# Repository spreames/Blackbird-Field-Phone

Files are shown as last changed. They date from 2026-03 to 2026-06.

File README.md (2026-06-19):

# Blackbird Field Phone

A cave rescue field phone for replacing the TP-6N.

#### **Status: Incomplete -- do not for design use until all files loaded**

### Background:

In the USA, cave rescue communications have been done with military field phones for decades. These are two-wire systems that are part of a party-line system (aka parallel connected). The National Cave Rescue Commission (NCRC) has a cache of these phones that are used for training. These units are available in the military surplus stores and online such as eBay. Over the years these field phones have become standard for all cave rescue teams in the USA.

There are three standard field phones that are in use today. The TA-1 ("sound powered" phone) which does not requires batteries but has a very limited range of 2 miles or less. The TA-312 (the "crank phone") has a theoretical range of 20 miles but weights 10.0 lbs with batteries! The TP-6N (the "NATO phone") has the same range but has solid-state circuitry, is much lighter (2.5 lbs), and much smaller.

The problem is that the units are failing. There a no replacement parts, no schematics, and no theory of operation. The most recent model, the TP-6N, was designed in 1973 -- a 50-year old design!

### Introduction to the Blackbird:

In December 2021, the NCRC formed the Communication Committee (CommComm) to address the increasing failure rate with the military phones in the field. The group decided to begin the design of a clone of the TP-6N which was named "Blackbird". Many of the original components are obsolete and very hard to obtain such as custom transformers and uni-junction transistors. So the team designed a functional clone such that works the same as the TP-6N but uses the modern techniques such as SMT components, KiCAD schematics and PCB layouts, 3D printing, and LTspice simulations.

The requirements and goals are:

- Backward compatable with the existing field phones

- Lighter, smaller, and requiring less power

- Runs off three AA batteries

- Is the same cost or less as TP-6Ns on eBay (when they are available)

The complete Goals and Requirements document is 13 pages and is linked here:

xxxxxx

### Block Diagram:

xxxx

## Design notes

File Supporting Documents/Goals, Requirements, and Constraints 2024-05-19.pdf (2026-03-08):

Goals, Requirements, and Constraints for the Design of the TP-6N Field Phone Replacement

last edit: May 19, 2024

authors: Steve Reames, with additions from members of the NCRC Communications Committee

### 1.0 Background:

The TP-6N has been the most popular field phone for cave rescue for over 15 years. It has been reliable, lightweight, and does well in the caving environment. There is a need for a replacement field phone that will be designed as a replacement for the TP-6N.

### 1.1 Who are the Users?

The users of the replacement field phone would be anyone who is involved with communications for cave rescue. This can include ordinary cavers who volunteer their time for teaching or real rescues, search and rescue team members (SAR), or agency personnel such as firefighters, National Park Service (NPS), the Bureau of Land Management (BLM), or United States Forest Service (USFS). This project is generally focused on U.S. users, but can include foreign cave rescue team members.

The NCRC has formed the NCRC Communication Committee (CommComm) to address the needs for supporting cave rescue communications, which includes a replacement for the TP-6N field phone. CommComm has taken the responsibility to design and possibly manufacture this potential replacement field phone. The committee will take into account the needs of the above mentioned users in the design of the field phone.

### 2.0 Abbreviations and Terms:

POTS: Plain Ordinary Telephone Service. Also referred to as a "landline".

EMC: Electromagnetic Compatibility. Ability of electrical equipment to function acceptably in their electromagnetic environment by limiting the unintentional generation of electromagnetic energy.

NCRC: National Cave Rescue Commission. A division of the NSS dedicated to cave rescue training.

TP-6N: A field phone often referred to as the "NATO phone". Designed in 1973 by the Norwegian Armed Forces.

TA-312: A field phone often referred to as the "crank phone". Designed in the 1950's and deployed in the Korean war.

TA-1: A field phone often referred to as the "sound powered phone". Designed in the 1950's.

RFI: Radio Frequency Interference. An old term, now replaced with EMC.

Opamp: Operational Amplifier. An integrated circuit with many uses in electronics.

SAR: Search and Rescue

PTT: Push To Talk. A switch that enables the microphone of a field phone.

### 3.0 Nomenclature:

A number surrounded by brackets, such as [1], indicates the priority of the requirement. There are three categories:

[1] -- Required: Cannot be changed without revisiting the purpose of the entire project.
[2] -- Strong Want: We are willing to put extra effort to accomplish this requirement.
[3] -- Would Be Nice: An extra feature that would make the product easier to use.

### 4.0 Requirements:

The requirements in this section are a combination of military specifications and real-world use of the field phones. The published military specs are very sparse and are completely inadequate for designing a replacement field phone (see Appendixes). When military specs are not available we fall back to measurements of physical units, knowing that we will be working with typical values rather than worst case values.

Section 4.1

[1] Backward compatible with the existing 2-wire military field phones, specifically the TP-6N (“NATO” phone), TA-312 (“Crank phone”), and the TA-1 (Sound-powered phone).

Description: Backward compatible means that the new phone can be added to an existing phone system with no adverse effect. The physical implementation can be different, for example the TA-312 uses D-cell batteries and the new proposed phone will use AA batteries. But the main functions of duplex voice communication with high-voltage ringing signal must be maintained.

Section 4.2

[1] The replacement unit will work with the standard 2-wire communication system. It will be designed to use lines with no 48V bias (LB, not CB, in military speak). It may work with lines DC voltage applied but is not required. Wires for cave rescue are assumed to have no DC bias.

Description: Conventional POTS telephones use a central 48V battery for powering the phone and for signaling. This is not required for cave rescue applications and the design of inductors that need to support 48V DC lines is unnecessarily complex. There is also the question of range. Two TP-6N units can communicate up to 14 miles (wet, WD-1 wire). The TA-312 also can go 14 miles (wet, WD-1 wire). The TA-1 is rated at 4 miles, and the EE-8 is rated at 7 miles. It is also known that each additional attached phone reduces the range. The proposed unit has not been tested for range. The standard WD-1 military wire is assumed, but the system should work with any pair of wires, though the range may be reduced.

Section 4.3

[2] Power: The replacement unit should operate from 3.0V to 5.0V. The quiescent current should be equal to or less than 7.5 mA. Typical power would be three AA batteries (4.5V to 3.0V) or a single 18650 Lithium-ion battery (4.2V to 3.0V).

Description: This is based on the typical use of three AA batteries for the TP-6N. The TP-6N was designed to use three D-cells, but the military wanted the unit to run for weeks. The capacity of an alkaline AA is approximately 2300 mAh (for a 1.0V dropout). So the quiescent run time would be 300 hours. For a Sanyo 3400mAh lithium-ion battery the run time would be 450 hours. The actual run time will be less due to use of the microphone and the ringer. It is rare for a cave rescue to run for 4 days (100 hours). In that situation it is reasonable to expect that someone would bring replacement batteries if the rescue ran that long. So a quiescent current of 7.5 mA is very conservative and can be increased if needed. The maximum permitted voltage of 5.0V is because many of the low-power opamps have a maximum voltage of 5.5V.

Section 4.4

Ringing Voltage: Ringing is a high-voltage signal used to alert other users on the line. The function of ringing is a type [1] requirement, but the exact voltage and frequency is a type [2] requirement. The ringing is expected to be an AC signal in the 40 to 100 Vpeak range. The ringer circuitry must not be damaged by a short circuit on the line.

Description: The generation of the ringing signal is one of the hardest design challenges for the replacement field phone. The circuit must work at the minimum input voltage (3.0V) but generate a 60 V (typical) signal that is switched at a 20 Hz (typical) to create an 120 Vp-p waveform on the line. The TP-6N has an amazing low part count for their circuit but required custom magnetics that we do not have access to nor the construction of said magnetics. We, being small-shop designers and manufacturers, are limited by off-the-shelf components or building components (such as magnetics) that are easily assembled with technician skills and do not require special tools.

The TA-1 uses a hand generator to create the ringing signal. One squeeze on the trigger creates the output voltage. The TA-312 has a crank generator on the side of the unit to create the ringing signal. On the receiving end, the TA-312 has a hammer on a diaphragm that creates a drumming sound. The specs for the TA-312 say the ringing signal is 20 Hz at 90 to 100 V (but does not indicate if that voltage is Vpeak, Vp-p, or RMS).

The TP-6N uses a solid-state ringing signal. When the button is pressed the circuit creates a 20 Hz or 25 Hz signal (depending on whether the unit is Norwegian or Swedish). The specification is that with a 4.5 V battery voltage the output is 60 Vrms; with a 3.0 V battery the output voltage is 38 Vrms (with a 3 Kohm load). It is known that on long lines the TP-6N does not have enough energy to trigger the sounder of a TA-312.

Commercial ringing circuits (used with local PBX systems) often have specifications of an output of voltage of 70 to 91 Vrms with an input power of 2 to 3 Watts. (Though available on eBay, they all require an input voltage of 12V.)

The telephone system (POTS) specifies the impedance of one REN (Ringer Equivalent Number) to be approximately 7 Kohm (or more) at 20 Hz. This is consistent with our measurement of 35 Kohm at the input of a TP-6N. Though REN is specified for POTS, the military phone system is derived from the POTS.

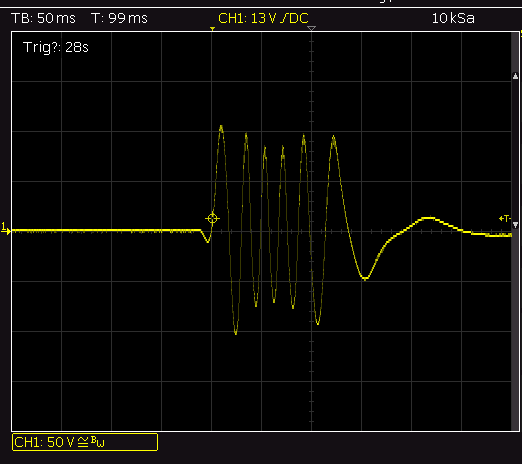
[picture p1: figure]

Ringing signal for the TA-1 (with 500 ft line and TP-6N load)

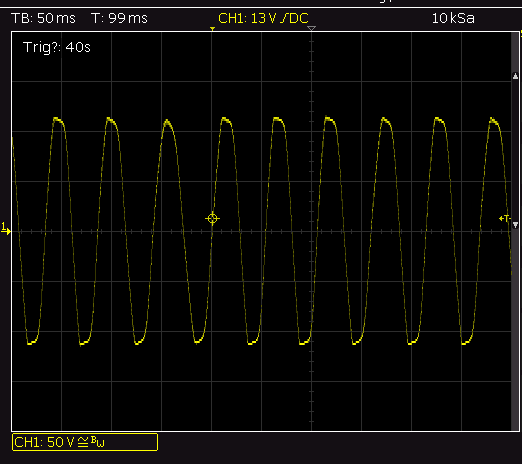
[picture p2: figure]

Ringing signal from a TA-312 (with 500 ft line and TP-6N load)

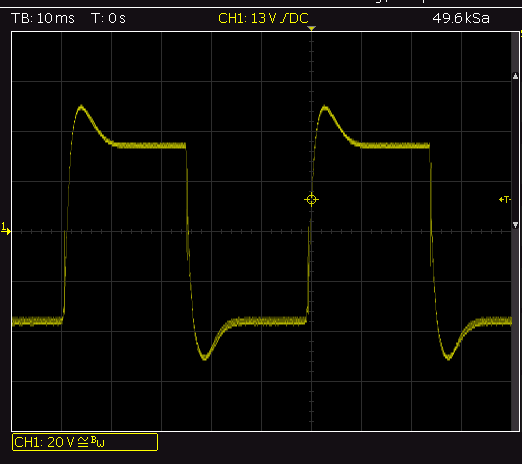
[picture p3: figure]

Ringing signal from TP-6N (with a 500 ft line and a TA-312 load)

Section 4.5

[2] Incoming Ringing Signal (audio): An incoming ringing signal will be heard in the earpiece of the handset. No additional circuitry is needed to receive the signal.

Description: The current design uses the same system as the TP-6N; the clicking from the ringing signal is heard in the earpiece. This is different from almost all military field phones; they typically have a separate sounder in the base unit. The TA-312 has a "drum" that vibrates at the ringing signal frequency. The British PTC-414 (circa 1993) has a piezoelectric buzzer that oscillates at 2 KHz, modulated by the 20 Hz ringing signal. This information is just for reference in the case we wish to change how the incoming ringing signal is indicated.

Section 4.6

[2] Incoming Ringing Indicator (visual): When a ringing signal is present, whether it is being generated in the unit or being received from a remote unit, a red LED flashes (at 20 Hz). An additional troubleshooting feature [3] of the TP-6N is that if the unit is open circuited (or not connected to the line) then the user can hear the ringing in the earpiece, but no LED is present. If the unit is shorted then the LED is visible, but no ringing is heard in the earpiece.

Description: The LED in the TP-6N appears to be type 1-3/4 (5 mm) which makes sense because red LEDs were just entering the market in the early 1970's. No other field phone (of that vintage) has a visible indicator. But it has been found to be very handy, particularly for troubleshooting. The LED on the TP-6N is very hard to see in daylight but works very well in cave conditions. These days there are much more efficient LEDs that only cost a few more pennies.

Section 4.7

[1] Weight and Volume: The weight and volume should be equal or less than a TP-6N.

Description: The weight of the TP-6N handset and cord is 0.73 lbs, the base unit of the TP-6N is 2.16 lb, and the entire package, including the pouch and D-cell batteries is 3.64 lbs. This is an unfair comparison because we never use D-cells, instead we use the insert with three AA batteries. Subtracting the difference between the D-cells and the AA cells, we should be looking for a target weight of 2.97 lbs. Volume is also a key parameter for cave rescuers. The existing TP-6N (total package) is approximately 10.2" x 7.7" x 2.6". A smaller package would enable a rescuer to move faster, or carry more gear at the same speed. Both are valuable attributes.

The intent of the project is to leverage techniques and processes that did not exist or were too expensive to implement in the 1970's. Some examples are 3D printing, inexpensive PCBs, and surface-mount devices (SMDs).

Section 4.8

[1] Full Duplex Communication: The existing military phone system uses full duplex communications. Specifically, when talker A is speaking, they still can hear speech from person
B. This requires a "hybrid" circuit which combines 4-wire communication (microphone and earpiece) into a 2-wire system which is attached to the field wire. This is how POTS works.

Description: The addition of a hybrid circuit is an additional complexity which is generally avoided. But to be compatible with existing field phones then it is required. The other approach, a half duplex system, is what is used with radios -- when the talker keys the microphone then no one else can interrupt the transmission. The use of a hybrid gives the ability of the receiver to give instant feedback to the transmitter (e.g. "hold on, give me that number slower", or "break, break, priority message incoming"). One could argue the utility of that feature, but since we want to be compatible with existing field phones then the decision is done. There is the question of why do we have a PTT button on our field phones? POTS does not have it. The answer is to keep the noise down on the wires. Only the person who has keyed their PTT will enable their microphone.

Section 4.9

[1] Electromagnetic Compatibility: Any electronic circuit has the potential to radiate electromagnetic energy and interfere with nearby communications. The Federal Communications Commission (FCC) is responsible for regulating the frequency and intensity of any EM emissions. There are three options for handing the FCC regulations. 1) Ensure by design that any potential radiation will be below any of the frequencies that are regulated by the

FCC. 2) Submit sample circuits to a test lab for certification that will confirm that the circuit is compliant. 3) Ignore the FCC regulations because it is unlikely we would be caught. We must decide which of the three options we choose to follow.

Description: Reading the regulations for EMC can be overwhelming. But in the U.S. battery operated devices are exempt as long as there are no clocks higher than 1.705 MHz. So the current Blackbird project is exempt. There is a caveat is that the product is not exempt if the product is running and connected (directly or indirectly) to an AC power line. So the field phone cannot be running while plugged into a battery charger. One of the proposed features is the ability to run off external batteries, such as 12V car battery. This would probably require a switching power supply to convert the 12V into 4.5V for the field phone circuitry. Most switching power supplies (at these powers and voltages) switch at 150 KHz to 1 MHz, so we are still covered. (see Appendix D.)

Technically, there is a fourth option: do it yourself kits. For many years it has been assumed that if you build a kit then it is exempt. Though this may have been true in the past, it is not correct anymore. But it is not clear who is responsible for compliance -- the kit manufacturer or the user. A dated link from Sparkfun is interesting reading:
https://www.sparkfun.com/tutorials/398

It would be nice to have the field phone covered in other countries, specially the EU. That would be a type [3] requirement. In recent years the EU has been regulating lower frequency emissions. In the past you could be safe with any frequency below 30 KHz. Recent changes apply to some circuits as low as 9 KHz (think of buried wires for guiding a robot lawn mower). Since certifications generally cost $2500 and up, it is not cost efficient for us to comply with EU regulations. But if we do have to do testing for the U.S. then it typically only costs another 10% to certify for the EU also.

EMC certification is a complex topic and cannot be easily summarized in these pages.

### 5.0 Requirements for Future Text-Based Communications System

(To be determined)

Notes from Andy Sheaff in April 2024:

Digital Text System Constraints (no particular order):

* Use WD-1 field wire for an communications because teams already have this wire and are unlikely to change.

* Avoid baseband digital data to keep Comms Operators from having to listen to the digital data; Parallel voice and data may be possible.

* Operate without termination because this just happens.

* Operate with or without stubs and branches of arbitrary length because the location of field phones may be in different and down forked passages. Field wire goes where it needs to.

* Operate with 10 km of wire between stations from Steve's recollection of the most distance rescue.

(Note: Steve's recollection was from the Fisher Ridge rescue reported by Tim Miller. They used 9,000 feet of wire, which is different than 10 km, though 10 km would be good goal -Steve R.)

* Devices should not be damaged by a short on the field wire because shorts do occur.

* Operate with a variable number of field phones attached as the number of field phones varies.

Appendix A:

Technical Data for the TP-6N

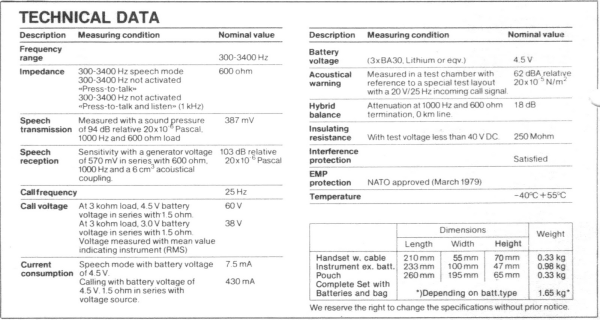
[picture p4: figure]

Appendix B:

Specifications for the TA-312/PT

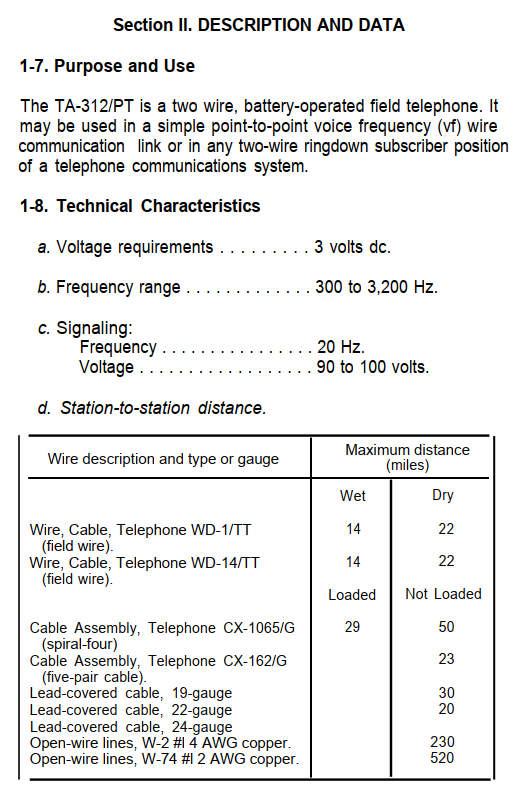
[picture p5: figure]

Appendix C:

Specifications for the TA-1/PT

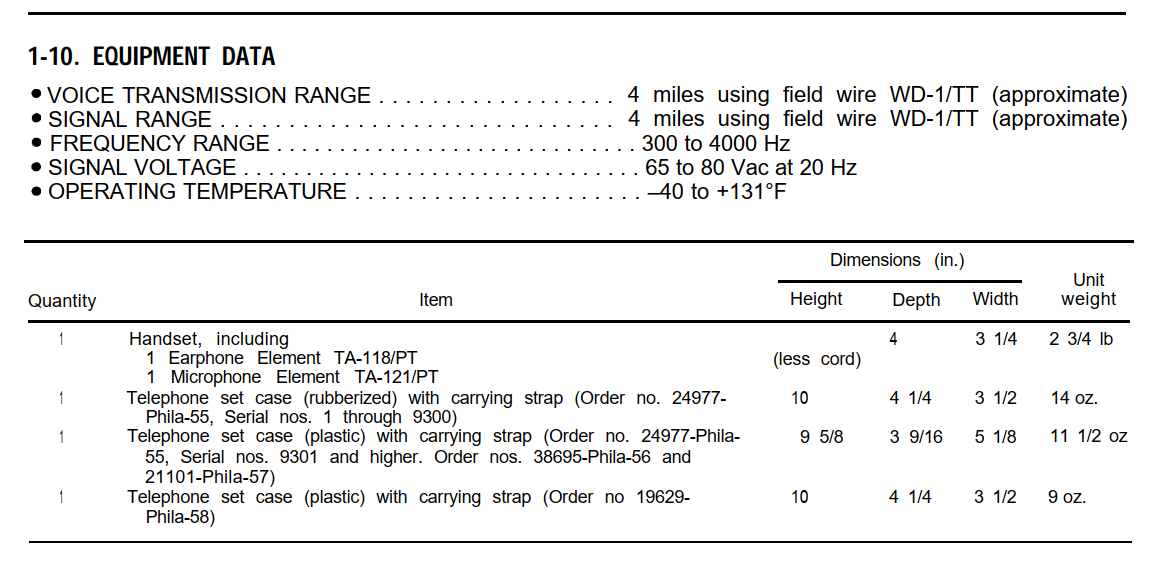
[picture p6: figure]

Appendix D:
FCC Title 47, Chapter 1, Subchapter A, Part 15, Subpart B:

§ 15.103 Exempted devices.

Except as provided in paragraph (j) (https://www.ecfr.gov/current/title-47/section-15.103#p-15.103(j)) of this section, the following devices are subject only to the general conditions of operation in §§ 15.5 (https://www.ecfr.gov/current/title-47/section-15.5) and 15.29, (https://www.ecfr.gov/current/title-47/section-15.29) and are exempt from the specific technical standards and other requirements contained in this part. The operator of the exempted device shall be required to stop operating the device upon a finding by the Commission or its representative that the device is causing harmful interference. Operation shall not resume until the condition causing the harmful interference has been corrected. Although not mandatory, it is strongly recommended that the manufacturer of an exempted device endeavor to have the device meet the specific technical standards in this part.

(a) A digital device utilized exclusively in any transportation vehicle including motor vehicles and aircraft.
(b) A digital device used exclusively as an electronic control or power system utilized by a public utility or in an industrial plant. The term public utility includes equipment only to the extent that it is in a dedicated building or large room owned or leased by the utility and does not extend to equipment installed in a subscriber's facility.
(c) A digital device used exclusively as industrial, commercial, or medical test equipment.
(d) A digital device utilized exclusively in an appliance, e.g., microwave oven, dishwasher, clothes dryer, air conditioner (central or window), etc.
(e) Specialized medical digital devices (generally used at the direction of or under the supervision of a licensed health care practitioner) whether used in a patient's home or a health care facility. Non-specialized medical devices, i.e., devices marketed through retail channels for use by the general public, are not exempted. This exemption also does not apply to digital devices used for record keeping or any purpose not directly connected with medical treatment.
(f) Digital devices that have a power consumption not exceeding 6 nW.
(g) Joystick controllers or similar devices, such as a mouse, used with digital devices but which contain only non-digital circuitry or a simple circuit to convert the signal to the format required (e.g., an integrated circuit for analog to digital conversion) are viewed as passive add-on devices, not themselves directly subject to the technical standards or the equipment authorization requirements.
(h) Digital devices in which both the highest frequency generated and the highest frequency used are less than 1.705 MHz and which do not operate from the AC power lines or contain provisions for operation while connected to the AC power lines. Digital devices that include, or make provision for the use of, battery eliminators, AC adaptors or battery chargers which permit operation while charging or that connect to the AC power lines indirectly, obtaining their power through another device which is connected to the AC power lines, do not fall under this exemption.
(i) Responsible parties should note that equipment containing more than one device is not exempt from the technical standards in this part unless all of the devices in the equipment meet the criteria for exemption. If only one of the included devices qualifies for exemption, the remainder of the equipment must comply with any applicable regulations. If a device performs more than one function and all of those functions do not meet the criteria for exemption, the device does not qualify for inclusion under the exemptions.
(j) Notwithstanding other provisions of this section, the rules governing certification apply to any equipment produced by any entity identified on the Covered List, as established pursuant to § 1.50002 of this chapter, (https://www.ecfr.gov/current/title-47/section-1.50002) as producing covered communications equipment.

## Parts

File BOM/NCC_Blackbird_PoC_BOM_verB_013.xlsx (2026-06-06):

MME P/N | REV | DWG No | PART DESCRIPTION | REF. DES. | QTY | UOM | Make/Buy | MFGR-1 | MFGR-1 P/N | DIST-1 | DIST-1 P/N | MFGR-2 | MFGR-2 P/N | MFGR-3 | MFGR-3 P/N | Cost (1) | Ext. Cost (1) | Cost (10) | Ext Cost (10)
 |  |  | Top Level – Blackbird Proof-of-Concept Field Phone
 |  |  | Main PCB Assy |  | 1 | EA | M
 |  |  | Handset Assy |  | 1 | EA | M
 |  |  | Base Unit Assy |  | 1 | EA | M
 |  |  | Battery, 18650 |  | 1 | EA | B
 |  |  | Battery, AA |  | 3 | EA | B
MME P/N | REV | DWG No | PART DESCRIPTION | REF. DES. | QTY | UOM | Make/Buy | MFGR-1 | MFGR-1 P/N | DIST-1 | DIST-1 P/N | MFGR-2 | MFGR-2 P/N | MFGR-3 | MFGR-3 P/N | Cost (1) | Ext. Cost (1) | Cost (10) | Ext Cost (10)
 |  |  | Handset Assy
 |  |  | Speaker, IP67, 30mm, WSPH-3005 |  | 1 | EA | B | Soberton Inc. | WSPH-3005 | Digikey | 433-1284-ND |  |  |  |  | $3.03 | $3.03 | $2.28 | $2.28
 |  |  | Microphone, 6mm dia, electret |  | 1 | EA | B | Soberton Inc. | EM6027LW-42C | Digikey | 433-1154-ND |  |  |  |  | $1.68 | $1.68 | $1.37 | $1.37
 |  |  | Switch, momentary pushbutton, for PTT | M1 | 1 | EA | B | Judco Manufacturing Inc. | 40-2390-00 | Digikey | 506PB-ND |  |  |  |  | $2.35 | $2.35 | $2.03 | $2.03 | old switch
 |  | xxx | Microphone Insert, 82A filament, Recreus FilaFlex |  | 1 | EA | M |  |  |  |  |  |  |  |  | $0.15 | $0.15 | $0.15 | $0.15
 |  |  | Cable, 5 cond, 5 x 0.34mm (22 AWG) |  | 1.5 | m | B | Helukabel | 49608 | TME | STR-PUR5X0.34 |  |  |  |  | $4.87 | $7.30 | $2.42 | $3.62
 |  |  | Cable gland, with pigtail |  | 1 | EA | B | Heyco Products Corp | 3237 | Digikey | 3720-3237-ND |  |  |  |  | $1.78 | $1.78 | $1.51 | $1.51
 |  |  | Screw, 316 SS, Button Head, Hex Drive, M3 x 0.5mm, 10mm Long |  | 13 | EA | B | McMaster | 94500A223 |  |  |  |  |  |  | $0.09 | $1.14 | $0.09 | $1.14 | uses 2.5mm hex driver
 |  |  | Connector,butt splice, 22-26 AWG, crimp |  | 5 | EA | B | TE Conn AMP Connectors | 321026 | Digikey | A27461 |  |  |  |  | $0.39 | $1.95 | $0.31 | $1.57
 |  |  | Connector, butt splice,
 |  |  | Brass Heat-Set Inserts for Plastic, M3 x 5.7mm | M3 | 13 | EA | B | CNC Kitchen | M3x5.7 | CNC Kitchen |  | McMaster | 97171A310 |  |  | $0.21 | $2.73 | $0.12 | $1.57
 |  | xxx | Filament, 3D printer, PCTG, Handset Cover, 2 copies |  | 26 | gm | M | 3D Fuel | Pro PCTG filament |  |  |  |  |  |  | $0.04 | $1.04 | $0.04 | $1.04 | based on PCTG
 |  | xxx | Filament, 3D printer, PCTG, Handset, Left body |  | 57 | gm | M | 3D Fuel | Pro PCTG filament |  |  |  |  |  |  | $0.04 | $2.27 | $0.04 | $2.27 | based on PCTG
 |  | xxx | Filament, 3D printer, PCTG, Handset, Right body |  | 58 | gm | M | 3D Fuel | Pro PCTG filament |  |  |  |  |  |  | $0.04 | $2.31 | $0.04 | $2.31 | based on PCTG
MME P/N | REV | DWG No | PART DESCRIPTION | REF. DES. | QTY | UOM | Make/Buy | MFGR-1 | MFGR-1 P/N | DIST-1 | DIST-1 P/N | MFGR-2 | MFGR-2 P/N | MFGR-3 | MFGR-3 P/N | Cost (1) | Ext. Cost (1) | Cost (10) | Ext Cost (10)
 |  |  | Base Unit Assy
 |  |  | Diode, LED, red, T ¾ package (5mm), 60 deg, 700 mcd | D200 | 1 | EA | B | Lumex Opto/Components Inc. | SSL-LX5093SID | Digikey | 67-2288-ND | Kingbright | WP63SURDK |  |  | $0.68 | $0.68 | $0.40 | $0.40
 |  |  | Diode mounting, for 1 ¾ package | LED mounting | 1 | EA | B | Lumex Opto/Components Inc. | SSH-LX5091 | Digikey | 67-1332-ND |  |  |  |  | $0.33 | $0.33 | $0.18 | $0.18
 |  |  | LED mounting,
 |  |  | Speaker, 8 ohm, square, for buzzer |  | 1 | EA | B | Wolff Electronics | OWS-131845W50A-8 | Digikey | 3949-OWS-131845W50A-8-ND |  |  |  |  | $1.51 | $1.51 | $1.18 | $1.18
 |  |  | Terminal Post, for comm line connection |  | 2 | EA | B | CLIFF Electronics | CL681561 | Digikey | 4654-CL681561-ND |  |  |  |  | $2.23 | $4.46 | $2.09 | $4.18
 |  |  | Connector, TRRS, 3.5mm, panel mount (aux connector) |  | 1 | EA | B | Same Sky (Formerly CUI Devices) | SJ5-43502PM | Digikey | CP5-43502PM-ND |  |  |  |  | $2.43 | $2.43 | $2.07 | $2.07
 |  |  | Cable gland with pigtail, PG7, nylon, range 2.9-6.35mm |  | 1 | EA | B | Heyco | 3237 | Digikey | 3720-3237-ND |  |  |  |  | $1.78 | $1.78 | $1.51 | $1.51
 |  |  | Switch, momentary pushbutton, for Ringer, waterproof | M2 | 1 | EA | B | CIT Relay and Switch | FHNDSBX | Digikey | 2449-FHNDSBX-ND | E-Switch | PV0H240SS |  |  | $7.77 | $7.77 | $7.77 | $7.77 | new switch
 |  |  | Brass Heat-Set Inserts for Plastic, M3 x 5.7mm | M3 | 7 | EA | B | CNC Kitchen | M3x5.7 | CNC Kitchen |  | McMaster | 97171A310 |  |  | $0.21 | $1.47 | $0.12 | $0.85
 |  |  | Brass Heat-Set Inserts for Plastic, ¼-20 | M4 | 1 | EA | B | McMaster | 93365A160 |  |  |  |  |  |  | $0.21 | $0.21 | $0.21 | $0.21
 |  |  | Screw, 316 SS, Button Head, Hex Drive, M3 x 0.5mm, 10mm Long | uses 2.5mm hex driver | 7 | EA | B | McMaster | 94500A223 |  |  |  |  |  |  | $0.09 | $0.61 | $0.09 | $0.61
 |  |  | Rod, 304 SS Rod, 3 mm Diameter |  | 0.2 | FT | B | McMaster | 1272T33 |  |  |  |  |  |  | $3.77 | $0.75 | $3.77 | $0.75
 |  |  | Battery Contact, leaf, 1017-1 | battery door side | 3 | EA | B | Keystone Electronics | 1017-1 | Digikey | 36-1017-1-ND |  |  |  |  | $0.19 | $0.57 | $0.15 | $0.46
 |  |  | Battery Contact, leaf, 209 | inside of the case | 3 | EA | B | Keystone Electronics | 209 | Digikey | 36-209-ND |  |  |  |  | $0.25 | $0.75 | $0.20 | $0.61
 |  |  | O-ring, large, for case |  | 1 | EA | B | McMaster-Carr | 1302N156 |  |  |  |  |  |  | $8.24 | $8.24 | $1.64 | $1.64 | bag of 5
 |  |  | O-ring, medium, for battery door |  | 1 | EA | B | McMaster-Carr | 9262K529 |  |  |  |  |  |  | $7.17 | $7.17 | $0.29 | $0.29 | bag of 25
 |  |  | Cable gland, with pigtail |  | 1 | EA | B | Heyco Products Corp | 3237 | Digikey | 3720-3237-ND |  |  |  |  | $1.78 | $1.78 | $1.51 | $1.51
 |  |  | Ring lug, 4mm or #8, non-insulated | for comm line conn. | 2 | EA | B | Amazon |  |  |  |  |  |  |  | $13.94 | $27.88 | $0.09 | $0.17 | https://www.amazon.com/dp/B0CYBZDDG6
 |  |  | D-ring, 1/4-20 tripod mounting, stainless | for battery door | 1 | EA | B | Amazon |  |  |  |  |  |  |  | $1.60 | $1.60 | $1.60 | $1.60 | https://www.amazon.com/dp/B0CR1PKCG3
 |  |  | rubber seal for D-ring | for battery door | 1 | EA | B
 |  | xxx | Filament, 3D printer, PCTG, CASE |  | 226 | gm | M | 3D Fuel | Pro PCTG filament |  |  |  |  |  |  | $0.04 | $9.02 | $0.04 | $9.02 | based on PCTG
 |  | xxx | Filament, 3D printer, PCTG, Case Cover |  | 22 | gm | M | 3D Fuel | Pro PCTG filament |  |  |  |  |  |  | $0.04 | $0.88 | $0.04 | $0.88 | based on PCTG
 |  | xxx | Filament, 3D printer, PCTG, Battery Cover |  | 24 | gm | M | 3D Fuel | Pro PCTG filament |  |  |  |  |  |  | $0.04 | $0.96 | $0.04 | $0.96 | based on PCTG
MME P/N | REV | DWG No | PART DESCRIPTION | REF. DES. | QTY | UOM | Make/Buy | MFGR-1 | MFGR-1 P/N | DIST-1 | DIST-1 P/N | MFGR-2 | MFGR-2 P/N | MFGR-3 | MFGR-3 P/N | Cost (1) | Ext. Cost (1) | Cost (10) | Ext Cost (10)
 |  |  | Internal Cables
 |  |  | Connector, JST XA, 8-pin, right angle, receptacle, TH | J1A | 1 | EA | B | JST Sales America Inc. | XAP-08V-1 | Digikey | 455-2154-ND |  |  |  |  | $0.19 | $0.19 | $0.16 | $0.16
 |  |  | Connector, JST XA, 4-pin, right angle, receptacle, TH | J2A, J6A | 2 | EA | B | JST Sales America Inc. | XAP-04V-1 | Digikey | 455-2150-ND |  |  |  |  | $0.10 | $0.20 | $0.08 | $0.15
 |  |  | Connector, JST VH, 2-pin, right angle, receptacle, TH | J3A | 1 | EA | B | JST Sales America Inc. | VHR-2N | Digikey | 455-VHR-2N-ND | JST Sales America Inc. | VHR-2M |  |  | $0.10 | $0.10 | $0.07 | $0.07
 |  |  | Connector, JST XA, 5-pin, right angle, receptacle,TH | J4A | 1 | EA | B | JST Sales America Inc. | XAP-05V-1 | Digikey | 455-2151-ND |  |  |  |  | $0.10 | $0.10 | $0.08 | $0.08
 |  |  | Connector, pins for JST XA connectors | pins for XA conn. | 21 | EA | B | JST Sales America Inc. | SXA-001T-P0.6 | Digikey | 455-1904-500-ND |  |  |  |  | $0.02 | $0.52 | $0.02 | $0.52 | strips of 100, 500, or 1000
 |  |  | Connector, pins for JST VH connectors | pins for VH conn. | 2 | EA | B | JST Sales America Inc. | SVH-21T-P1.1 | Digikey | 455-1133-100-ND |  |  |  |  | $0.05 | $0.11 | $0.05 | $0.11 | strips of 100, 500, or 1000
 |  |  | Wire, AWG 24, stranded, irradiated PVC, black |  | 1.5 | FT | B | Daburn | 2200/24 black | Daburn | 2200/24 black |  |  |  |  | $0.22 | $0.33 | $0.22 | $0.33
 |  |  | Wire, AWG 24, stranded, irradiated PVC, red |  | 1.5 | FT | B | Daburn | 2200/24 red | Daburn | 2200/24 red |  |  |  |  | $0.22 | $0.33 | $0.22 | $0.33
 |  |  | Wire, AWG 24, stranded, irradiated PVC, green |  | 1 | FT | B | Daburn | 2200/24 green | Daburn | 2200/24 green |  |  |  |  | $0.22 | $0.22 | $0.22 | $0.22
 |  |  | Wire, AWG 24, stranded, irradiated PVC, gray |  | 1 | FT | B | Daburn | 2200/24 gray | Daburn | 2200/24 gray |  |  |  |  | $0.22 | $0.22 | $0.22 | $0.22
 |  |  | Wire, AWG 24, stranded, irradiated PVC, yellow |  | 1 | FT | B | Daburn | 2200/24 yellow | Daburn | 2200/24 yellow |  |  |  |  | $0.22 | $0.22 | $0.22 | $0.22
 |  |  | Wire, AWG 24, stranded, irradiated PVC, white |  | 1.5 | FT | B | Daburn | 2200/24 white | Daburn | 2200/24 white |  |  |  |  | $0.22 | $0.33 | $0.22 | $0.33
 |  |  | Wire, AWG 24, stranded, irradiated PVC, brown |  | 1 | FT | B | Daburn | 2200/24 brown | Daburn | 2200/24 brown |  |  |  |  | $0.22 | $0.22 | $0.22 | $0.22
 |  |  | Wire, AWG 22, stranded, irradiated PVC, black |  | 1 | FT | B | Daburn | 2200/24 black | Daburn | 2200/24 black |  |  |  |  | $0.24 | $0.24 | $0.24 | $0.24
MME P/N | REV | DWG No | PART DESCRIPTION | REF. DES. | QTY | UOM | Make/Buy | MFGR-1 | MFGR-1 P/N | DIST-1 | DIST-1 P/N | MFGR-2 | MFGR-2 P/N | MFGR-3 | MFGR-3 P/N | Cost (1) | Ext. Cost (1) | Cost (10) | Ext Cost (10)
 |  |  | Main PCB Assy
 |  |  | Cap, ceramic, 22uF, 25V, 20%, X5R, SMT 0805 | C4,C19,C22,C25 | 4 | EA | B | Samsung Electro-Mechanics | CL21A226MAYNNNE | Digikey | 1276-CL21A226MAYNNNECT-ND |  |  |  |  | $0.08 | $0.32 | $0.04 | $0.17
 |  |  | Cap, ceramic, 330pF, 50V, 5%, NP0, SMT 0805 | C23 | 1 | EA | B | KEMET | C0805C331J5GACTU | Digikey | 399-C0805C331J5GACTUCT-ND |  |  |  |  | $0.10 | $0.10 | $0.05 | $0.05
 |  |  | Cap,ceramic, 10uF, 25V, X5R, 20%, SMD 0805 | C24 | 1 | EA | B | Murata Electronics | GRM21BR61E106KA73K | Digikey | 490-16824-1-ND |  |  |  |  | $0.15 | $0.15 | $0.09 | $0.09
 |  |  | Cap, ceramic, 0.47uF, 250V, 10%, X7R, SMT 1812 | C18,C26,C27 | 3 | EA | B | KYOCERA AVX | 1812PC474KAT2A | Digikey | 478-10710-1-ND |  |  |  |  | $0.54 | $1.62 | $0.32 | $0.97
 |  |  | Cap, ceramic, 39nF, 50V, 10%, X7R, SMT 0805 | C15,C33 | 2 | EA | B | YAGEO | AC0805KRX7R9BB393 | Digikey | 13-AC0805KRX7R9BB393CT-ND |  |  |  |  | $0.10 |  | $0.04
 |  |  | Cap, ceramic, 0.1uF, 50V, X7R, 20%, SMD 0805 | C1, C2, C5, C6, C7, C8, C20, C28, C30, C32, C35 | 11 | EA | B | KEMET | C0805C104M5RAC7800 | Digikey | 399-C0805C104M5RAC7800CT-ND |  |  |  |  | $0.10 | $1.10 | $0.04 | $0.47
 |  |  | Cap, ceramic, 1uF, 10%, 25V, X7R, SMD 0805 | C14,C29,C31 | 3 | EA | B | Samsung Electro-Mechanics | CL21B105KAFNNNE | Digikey | 1276-1066-1-ND | KEMET | C0805C105K3RACTU |  |  | $0.08 | $0.24 | $0.01 | $0.03
 |  |  | Cap, ceramic, 470pF, 50V, 5%, NP0, SMT 0805 | C9 | 1 | EA | B | KEMET | C0805C471J5GAC7210 | Digikey | 399-C0805C471J5GAC7210CT-ND |  |  |  |  | $0.18 | $0.18 | $0.10 | $0.10
 |  |  | Cap, ceramic, 1600pF, 50V, 5%, NP0, SMT 0805 | C10 | 1 | EA | B | KEMET | C0805C162J5GACTU | Digikey | 399-C0805C162J5GACTUCT-ND |  |  |  |  | $0.00 | $0.00 | $0.30 | $0.30
 |  |  | Cap, ceramic, 0.12uF, 50V, 10%, X7R, SMT 0805 | C11 | 1 | EA | B | YAGEO | CC0805KRX7R9BB124 | Digikey | 311-4323-1-ND |  |  |  |  | $0.10 | $0.10 | $0.05 | $0.05
 |  |  | Cap, ceramic, 0.01uF, 50V, 5%, NP0, SMT 0805 | C12 | 1 | EA | B | Walsin Technology Corp | 0805N103J500CT | Digikey | 1292-0805N103J500CT-ND |  |  |  |  | $0.10 | $0.10 | $0.05 | $0.05
 |  |  | Cap, ceramic, 150pF, 50V, 5%, NP0, SMT 0805 | C13, C39 | 2 | EA | B | KEMET | C0805C151J5GACTU | Digikey | 399-C0805C151J5GACTUCT-ND |  |  |  |  | $0.10 | $0.20 | $0.05 | $0.11
 |  |  | Cap, ceramic, 1.0uF, 250V, Tip & Ring, SMT 1825 | C16 | 1 | EA | B | KYOCERA AVX | 1825PC105KAT2A | Digikey | 478-8052-1-ND |  |  |  |  | $1.32 | $1.32 | $0.83 | $0.83
 |  |  | Cap, ceramic, 3.3uF, 10V, 10%, X5R, SMT 0805 | C17 | 1 | EA | B | Samsung Electro-Mechanics | CL21A335KPFNNNE | Digikey | 1276-2912-1-ND |  |  |  |  | $0.19 | $0.19 | $0.11 | $0.11
 |  |  | Cap, ceramic, 2.2uF, 16V, 10%, X7R, SMT 0805 | C3,C21 | 2 | EA | B | Samsung Electro-Mechanics | CL21B225KOFNNNE | Digikey | 1276-1162-1-ND |  |  |  |  | $0.11 | $0.22 | $0.06 | $0.12
 |  |  | Cap, ceramic, 390nF, 16V, 5%, X7R, SMT 0805 | C36 | 1 | EA | B | KYOCERA AVX | 0805YC394JAT2A | Digikey | 478-10574-1-ND |  |  |  |  | $0.36 | $0.36 | $0.21 | $0.21
 |  |  | Cap, ceramic, 5.6nF, 50V, 5%, NP0, SMT 0805 | C37 | 1 | EA | B | Murata Electronics | GRM2195C2A562JA01D | Digikey | 490-GRM2195C2A562JA01DCT-ND |  |  |  |  | $0.10 | $0.10 | $0.06 | $0.06
 |  |  | Cap, ceramic, 560pF, 50V, 5%, NP0, SMT 0805 | C34 | 1 | EA | B | YAGEO | CC0805JRNPO9BN561 | Digikey | 311-1120-1-ND |  |  |  |  | $0.11 | $0.11 | $0.06 | $0.06
 |  |  | Cap, alum-poly, 100uF, 25V, 20%, 6.6x6.6, 6mm tall, SMT | C38 | 1 | EA | B | KEMET | A768EB107M1ELAS036 | Digikey | 399-A768EB107M1ELAS036CT-ND | KYOCERA AVX | 478-APA0609101M025RCT-ND |  |  | $0.53 | $0.53 | $0.33 | $0.33
 |  |  | Diode, Schottkey, 30V, 500mA, SOD-123, MBR0530 | D20,D21,D22,D23 | 4 | EA | B | Micro Commercial Co | MBR0530-TP | Digikey | MBR0530TPMSCT-ND |  |  |  |  | $0.15 | $0.60 | $0.10 | $0.42
 |  |  | Diode, 1000V, 1A, SMT SMA, M7 | D24,D25 | 2 | EA | B | Diotec Semiconductor | M7 | Digikey | 4878-M7CT-ND |  |  |  |  | $0.10 | $0.20 | $0.06 | $0.11
 |  |  | Diode, dual, 300mA, 75V, SOT-23 | D1,D2,D3 | 2 | EA | B | Diodes Incorporated | BAV99-7-F | Digikey | BAV99-FDICT-ND | onsemi | BAV99LT1G |  |  | $0.10 | $0.20 | $0.06 | $0.12
 |  |  | Diode, TVS, unidirectional, 5.0V, SMT SMA, SMAJ5.0A | D4 | 1 | EA | B | Diotec Semiconductor | P4SMAJ5.0A | Digikey | 4878-P4SMAJ5.0ACT-ND | MCC (Micro Commercial Components) | SMAJ5.0A-TP | YAGEO | SMAJ5.0A/TR13 | $0.11 | $0.11 | $0.09 | $0.09
 |  |  | Diode, 1A, 1000V, SOD-123F, SLM1 | D5,D6,D7,D8,D9,D10,D11,D12 | 8 | EA | B | Diotec Semiconductor | SL1M | Digikey | 4878-SL1MCT-ND |  |  |  |  | $0.10 | $0.80 | $0.06 | $0.50
 |  |  | Diode, zener, 12V, 5%, SOD-123 | D13,D14 | 2 | EA | B | Micro Commercial Co | BZT52C12-TP | Digikey | BZT52C12-TPMSCT-ND |  |  |  |  | $0.10 | $0.20 | $0.06 | $0.12
 |  |  | Diode, 150mA, 75V, SOD-123, 1N4148W | D15,D17,D18 | 3 | EA | B | Diodes Incorporated | 1N4148W-13-F | Digikey | 1N4148W-13FDICT-ND |  |  |  |  | $0.10 | $0.30 | $0.06 | $0.18
 |  |  | Diode, thyristor, 150V, SMT SMA, TISP4145 | D16 | 1 | EA | B | Bourns Inc. | TISP4145M3BJR-S | Digikey | TISP4145M3BJR-SCT-ND | Bourns Inc. | TISP4145H3BJR-S |  |  | $1.17 | $1.17 | $0.73 | $0.73
 |  |  | Diode, Schottky, 1A, 20V, <0.4V, SOT-123 | D19 | 1 | EA | B | Panjit International Inc. | MBR1020VL-AU_R1_000A1 | Digikey | 3757-MBR1020VL-AU_R1_000A1CT-ND | onsemi | MBR120VLSFT1G | Diodes Inc. | DFLS120LQ-7 | $0.30 | $0.30 | $0.18 | $0.18 | Minimum Vf, <0.4V
 |  |  | Diode, LED, red, SMT 1206 | D26 | 0 | EA | B | Kingbright | APT3216SECK/J3-PRV | Digikey | 754-1796-1-ND |  |  |  |  | $0.44 | $0.00 | $0.44 | $0.00 | optional
 |  |  | Connector, JST XA, 8-pin, right angle, TH | J3 | 1 | EA | B | JST Sales America Inc. | S08B-XASK-1 | Digkey | 455-S08B-XASK-1-ND |  |  |  |  | $0.56 | $0.56 | $0.47 | $0.47
 |  |  | Connector, JST XA, 4-pin, right angle, TH | J2,J4 | 2 | EA | B | JST Sales America Inc. | S04B-XASK-1 | Digikey | 455-4090-ND |  |  |  |  | $0.40 | $0.80 | $0.34 | $0.68
 |  |  | Connector, JST VH, 2-pin, right angle, TH | J5 | 1 | EA | B | JST Sales America Inc. | S2P-VH | Digikey | 455-S2P-VH-ND |  |  |  |  | $0.19 | $0.19 | $0.16 | $0.16
 |  |  | Connector, JST XA, 5-pin, right angle, TH | J1 | 1 | EA | B | JST Sales America Inc. | S05B-XASK-1 | Digikey | 455-S05B-XASK-1-ND |  |  |  |  | $0.42 | $0.42 | $0.36 | $0.36
 |  |  | Connector, 0.1” header, 3-pin, female, TH, programming | J6 | 1 | EA | B | Samtec Inc. | SLW-103-01-F-S | Digikey | SAM15260-ND |  |  |  |  | $0.56 | $0.56 | $0.56 | $0.56
 |  |  | Inductor, 12mH, radial, D8.5mm x 11.2 tall, TH | L1, L2 | 2 | EA | B | Abracon LLC | AIUR-04-123J | Digikey | AIUR-04-123J-ND |  |  |  |  | $0.64 | $1.28 | $0.53 | $1.05
 |  |  | Inductor, 15uH, 2A, 5x5mm or 6.3x6.6.0mm, SMT | L3 | 1 | EA | B | Laird-Signal Integrity Products | TYS5040150M-10 | Digikey | 240-2712-1-ND | EPCOS - TDK Electronics | B82562N4153M000 | Würth Elektronik | 74404054150 | $0.41 | $0.41 | $0.33 | $0.33
 |  |  | Transistor, NPN, 40V, 600mA, SOT-23, MMBT4401 | Q2,Q6,Q8,Q14 | 4 | EA | B | MCC (Micro Commercial Components) | MMBT4401-TP | Digikey | MMBT4401TPMSCT-ND | Diodes Incorporated | MMBT4401-7-F | Good-Ark Semiconductor | MMBT4401 | $0.12 | $0.48 | $0.07 | $0.29
 |  |  | Transistor, PNP, 40V, 600mA, SOT-23, MMBT4403 | Q3,Q4,Q5,Q7 | 4 | EA | B | MCC (Micro Commercial Components) | MMBT4403-TP | Digikey | MMBT4403-TPCT-ND | ANBON SEMICONDUCTOR (INT'L) LIMITED | MMBT4403 | onsemi | MMBT4403LT1G | $0.12 | $0.48 | $0.07 | $0.29
 |  |  | MOSFET, N-channel, 30V, 5A, SOT-23 | Q1 | 1 | EA | B | Good-Ark Semiconductor | GSF3404 | Digikey | 4786-GSF3404CT-ND |  |  |  |  | $0.25 | $0.25 | $0.15 | $0.15
 |  |  | Transistor, NPN, 300V, 500mA, SOT-23, MMBTA42 | Q10,Q13 | 2 | EA | B | Diodes Incorporated | MMBTA42-7-F | Digikey | MMBTA42-FDICT-ND |  |  |  |  | $0.17 | $0.34 | $0.10 | $0.20
 |  |  | Transistor, PNP, 300V, 500mA, SOT-23, MMBTA92 | Q11,Q12 | 2 | EA | B | Diodes Incorporated | MMBTA92-7-F | Digikey | MMBTA92-FDICT-ND |  |  |  |  | $0.19 | $0.38 | $0.12 | $0.24
 |  |  | Transistor, MOSFET, P-chan,, >20V, >600mA, SOIC-8 | Q9 | 1 | EA | B | Diodes Incorporated | DMP3085LSS-13 | Digikey | DMP3085LSS-13DICT-ND | Panjit International Inc. | PJL9407_R2_00001 | Taiwan Semiconductor Corporation | TSM600P03CS RLG | $0.44 | $0.44 | $0.27 | $0.27
 |  |  | Resistor, 49.9R, 1%, SMD 0805 | R21 | 1 | EA | B | YAEGO | RC0805FR-0749R9L | Digikey | 311-49.9CRCT-ND |  |  |  |  | $0.11 | $0.11 | $0.01 | $0.01
 |  |  | Resistor, 499R, 1%, SMD 0805 | R20,R27 | 2 | EA | B | YAEGO | RC0805FR-07499RL | Digikey | 311-499CRCT-ND |  |  |  |  | $0.10 | $0.20 | $0.01 | $0.02
 |  |  | Resistor, 16 ohms, 5%, 3W, pulse-withstanding, SMD 2512 | R17,R18 | 2 | EA | B | Rohm Semiconductor | LTR100JZPJ160 | Digikey | 846-LTR100JZPJ160CT-ND | TE Connectivity | 3430A3F16RTDF |  |  | $0.60 | $1.20 | $0.35 | $0.70
 |  |  | Resistor, 30.1K, 1%, SMD 0805 | R22 | 1 | EA | B | YAEGO | RC0805FR-0730K1L | Digikey | 311-30.1KCRCT-ND |  |  |  |  | $0.10 |  | $0.01
 |  |  | Resistor, 200K, 1%, SMD 0805 | R19,R51,R52,R60,R61,R62 | 6 | EA | B | YAEGO | RC0805FR-07200KL | Digikey | 311-200KCRCT-ND |  |  |  |  | $0.11 | $0.66 | $0.01 | $0.05
 |  |  | Resistor, 100K, 1%, SMD 0805 | R8,R10,R11,R13,R14,R29,R31 | 7 | EA | B | YAEGO | RC0805FR-07100KL | Digikey | 311-100KCRCT-ND |  |  |  |  | $0.10 | $0.70 | $0.02 | $0.11
 |  |  | Resistor, 10.0K, 1%, SMD 0805 | R1,R3,R35,R49,R50,R56 | 6 | EA | B | YAEGO | RC0805FR-0710KL | Digikey | 311-10.0KCRCT-ND |  |  |  |  | $0.12 | $0.72 | $0.01 | $0.07
 |  |  | Resistor, 2.00K, 1%, SMD 0805 | R12,R36,R44,R55 | 4 | EA | B | YAEGO | RC0805FR-072KL | Digikey | 311-2.00KCRCT-ND |  |  |  |  | $0.11 | $0.44 | $0.01 | $0.04
 |  |  | Resistor, 90.9K, 1%, SMD 0805 | R34,R58 | 2 | EA | B | YAEGO | RC0805FR-0790K9L | Digikey | 311-90.9KCRCT-ND |  |  |  |  | $0.10 | $0.20 | $0.01 | $0.01
 |  |  | Resistor, 1.00K, 1%, SMD 0805 | R16,R24,R28,R30 | 4 | EA | B | YAEGO | RC0805FR-071KL | Digikey | 311-1.00KCRCT-ND |  |  |  |  | $0.10 | $0.40 | $0.01 | $0.04
 |  |  | Resistor, 66.5R | R37,R40 | 2 | EA | B | YAGEO | RC0805FR-0766R5L | Digikey | 311-66.5CRCT-ND |  |  |  |  | $0.10 | $0.20 | $0.03 | $0.06
 |  |  | Resistor, 1.00R, 1%, SMD 0805 | R39 | 1 | EA | B | YAEGO | RC0805FR-071RL | Digikey | 311-1.00CRCT-ND |  |  |  |  | $0.10 | $0.10 | $0.01 | $0.01
 |  |  | Resistor, 806R, 1%, SMD 0805 | R15 | 1 | EA | B | YAEGO | RC0805FR-07806RL | Digikey | 311-806CRCT-ND |  |  |  |  | $0.11 | $0.11 | $0.01 | $0.01
 |  |  | Resistor, 11.0K, 1%, SMD 0805 | R6 | 1 | EA | B | YAEGO | RC0805FR-0711KL | Digikey | 311-11.0KCRCT-ND |  |  |  |  | $0.10 | $0.10 | $0.01 | $0.01
 |  |  | Resistor, 20.0K, 1%, SMD 0805 | R2,R4,R7,R25,R26,R45,R46,R57 | 8 | EA | B | YAEGO | RC0805FR-0720KL | Digikey | 311-20.0KCRCT-ND |  |  |  |  | $0.10 | $0.80 | $0.01 | $0.08
 |  |  | Resistor, 16.9K, 1%, SMD 0805 | R9 | 1 | EA | B | YAEGO | RC0805FR-0716K9L | Digikey | 311-16.9KCRCT-ND |  |  |  |  | $0.10 | $0.10 | $0.01 | $0.01
 |  |  | Resistor, 4.99K, 1%, SMD 0805 | R32, R38,R42,R47,R48 | 5 | EA | B | YAEGO | RC0805FR-074K99L | Digikey | 311-4.99KCRCT-ND |  |  |  |  | $0.11 | $0.55 | $0.01 | $0.06
 |  |  | Resistor, 100R, 1%, SMD 1210 | R53,R54 | 2 | EA | B | Stackpole Electronics | RMCF1210JT100R | Digikey | RMCF1210JT100RCT-ND |  |  |  |  | $0.13 | $0.26 | $0.06 | $0.12
 |  |  | Resistor, 31.6K, 1%, SMD 0805 | R5 | 1 | EA | B | YAEGO | RC0805FR-0731K6L | Digikey | 311-31.6KCRCT-ND |  |  |  |  | $0.14 | $0.14 | $0.01 | $0.01
 |  |  | Resistor, 499K, 1%, SMD 0805 | R23,R59 | 2 | EA | B | YAEGO | RC0805FR-07499KL | Digikey | 311-499KCRCT-ND |  |  |  |  | $0.10 | $0.20 | $0.01 | $0.02
 |  |  | Resistor, 5.60K, 1%, SMD 0805 | R68,R74 | 2 | EA | B | YAEGO | RC0805FR-075K6L | Digikey | 311-5.60KCRCT-ND |  |  |  |  | $0.10 | $0.20 | $0.01 | $0.02
 |  |  | Resistor, 9.09K, 1%, SMD 0805 | R66,R72 | 2 | EA | B | YAEGO | RC0805FR-079K09L | Digikey | 311-9.09KCRCT-ND |  |  |  |  | $0.10 | $0.20 | $0.01 | $0.02
 |  |  | Resistor, 332R, 1%, SMD 0805 | R63,R69 | 2 | EA | B | YAEGO | RC0805FR-07332RL | Digikey | 311-332CRCT-ND |  |  |  |  | $0.10 | $0.20 | $0.01 | $0.02
 |  |  | Resistor, 845R, 1%, SMD 0805 | R64,R70 | 2 | EA | B | YAEGO | RC0805FR-07845RL | Digikey | 311-845CRCT-ND |  |  |  |  | $0.10 | $0.20 | $0.01 | $0.02
 |  |  | Resistor, 143K, 1%, SMD 0805 | R65,R71 | 2 | EA | B | YAEGO | RC0805FR-07143KL | Digikey | 311-143KCRCT-ND |  |  |  |  | $0.10 | $0.20 | $0.02 | $0.03
 |  |  | Resistor, 464R, 1%, SMD 0805 | R67,R73 | 2 | EA | B | YAEGO | RC0805FR-07464RL | Digikey | 311-464CRCT-ND |  |  |  |  | $0.10 | $0.20 | $0.01 | $0.02
 |  |  | Resistor, 121K, 1%, SMD 0805 | R41 | 1 | EA | B | YAEGO | RC0805FR-07121KL | Digikey | 311-121KCRCT-ND |  |  |  |  | $0.10 | $0.10 | $0.01 | $0.01
 |  |  | Resistor, 100R, 1%, SMD 0805 | R43 | 1 | EA | B | YAEGO | RC0805FR-13100RL | Digikey | 13-RC0805FR-13100RLCT-ND |  |  |  |  | $0.10 | $0.10 | $0.01 | $0.01
 |  |  | Resistor, 200R, 1%, SMD 0805 | R75 | 0 | EA | B | YAEGO | RC0805FR-07200RL | Digikey | 311-200CRCT-ND |  |  |  |  | $0.10 | $0.00 | $0.01 | $0.00 | optional
 |  | xxx | Transformer, bobbin | T1A | 1 | EA | M | EPCOS - TDK Electronics | B65820W1008D001 | Digikey | 495-5307-ND |  |  |  |  | $1.95 | $1.95 | $1.35 | $1.35
 |  | xxx | Transformer, ferrite, pair | T1B | 1 | EA | M | EPCOS - TDK Electronics | B65819J0000R087 | Digikey | 495-75901-ND |  |  |  |  | $2.72 | $2.72 | $1.87 | $1.87
 |  | xxx | Transformer, RM7 clamp | T1C | 2 | EA | M | EPCOS - TDK Electronics | B65820B2001X000 | Digkey | 495-5306-ND |  |  |  |  | $0.43 | $0.86 | $0.30 | $0.61
 |  |  | IC, analog switch, SOT-23-5, 74LVC1G66 | U3,U8 | 2 | EA | B | Texas Instruments | SN74LVC1G66DBVR | Digikey | 296-13253-1-ND | 3PEAK | TPW3115-S5TR | UMW | SN74LVC1G66DBVR | $0.18 | $0.36 | $0.12 | $0.24
 |  |  | IC, dual opamp, TLV9052, SOIC-8 | U2 | 1 | EA | B | Texas Instruments | TLV9052IDR | Digikey | 296-53049-1-ND |  |  |  |  | $0.73 | $0.73 | $0.52 | $0.52
 |  |  | IC, optocoupler, TLV-817, DIP-4 | U4 | 1 | EA | B | Lite-On Inc. | LTV-816S-TA1 | Digikey | 160-1892-1-ND | American Bright Optoelectronics Corporation | APC-817D1-SL | QT Brightek (QTB) | Q817CST1 | $0.38 | $0.38 | $0.26 | $0.26
 |  |  | IC, audio amplfier, TPA321, SOIC-8 | U1,U5 | 2 | EA | B | Texas Instruments | TPA321DR | Digikey | 296-46365-1-ND |  |  |  |  | $1.13 | $2.26 | $0.81 | $1.63
 |  |  | IC, opamp, dual, SOIC-8, TLV9002 | U14 | 1 | EA | B | Texas Instruments | TLV9002IDR | Digikey | 296-47596-1-ND |  |  |  |  | $0.59 | $0.59 | $0.42 | $0.42
 |  |  | IC, opamp, single, SOT23-5, TLV9001 | U9,U13 | 2 | EA | B | Texas Instruments | TLV9001IDBVR | Digikey | 296-TLV9001IDBVRCT-ND |  |  |  |  | $0.40 | $0.80 | $0.28 | $0.55
 |  |  | IC, comparator, dual, SOIC-8, TS3702 | U7 | 1 | EA | B | STMicroelectronics | TS3702IDT | Digkey | 497-2267-1-ND | STMicroelectronics | TS3702CDT | Texas Instruments | TLC3702IDR | $0.66 | $0.66 | $0.47 | $0.47
 |  |  | IC, microprocessor, SOIC-20, ATtiny406 | U11 | 1 | EA | B | Microchip Technology | ATTINY406-SNR | Digikey | ATTINY406-SNRCT-ND | Microchip Technology | ATTINY406-SFR |  |  | $0.96 | $0.96 | $0.96 | $0.96
 |  |  | IC, AND gate, single, SOT-23-5, 74AHC1G08 | U12 | 1 | EA | B | Texas Instruments | SN74AHC1G08DBVR | Digikey | 296-1091-1-ND |  |  |  |  | $0.12 | $0.12 | $0.08 | $0.08
 |  |  | IC, switching supply regulator, SOT-23-5, LM2735Y | U6 | 1 | EA | B | Texas Instruments | LM2735YMFX/NOPB | Digikey | 296-38711-1-ND |  |  |  |  | $2.44 | $2.44 | $1.81 | $1.81
 |  |  | IC, regulator, LDO, 2.5V, SOT-23-5, TPS7A2025 | U10 | 1 | EA | B | Texas Instruments | TPS7A2025PDBVR | Digikey | 296-TPS7A2025PDBVRCT-ND |  |  |  |  | $0.36 | $0.36 | $0.25 | $0.25
 |  | xxx | PCB |  | 1 | EA | M | OSH Park | internal | OSHpark |  |  |  |  |  | $40.03 | $40.03 | $36.00 | $36.00 | estimated cost
 |  |  |  |  |  |  |  |  |  |  |  |  |  |  | Total Cost = |  | $193.13 |  | $121.17
 |  |  | Small O-ring |  |  |  |  | McMaster-Carr | 1174N781 | old
 |  |  |  |  |  |  |  |  | 1174N422
 |  |  | Large O-ring |  |  |  |  | McMaster-Carr | 1302N155
Future Components

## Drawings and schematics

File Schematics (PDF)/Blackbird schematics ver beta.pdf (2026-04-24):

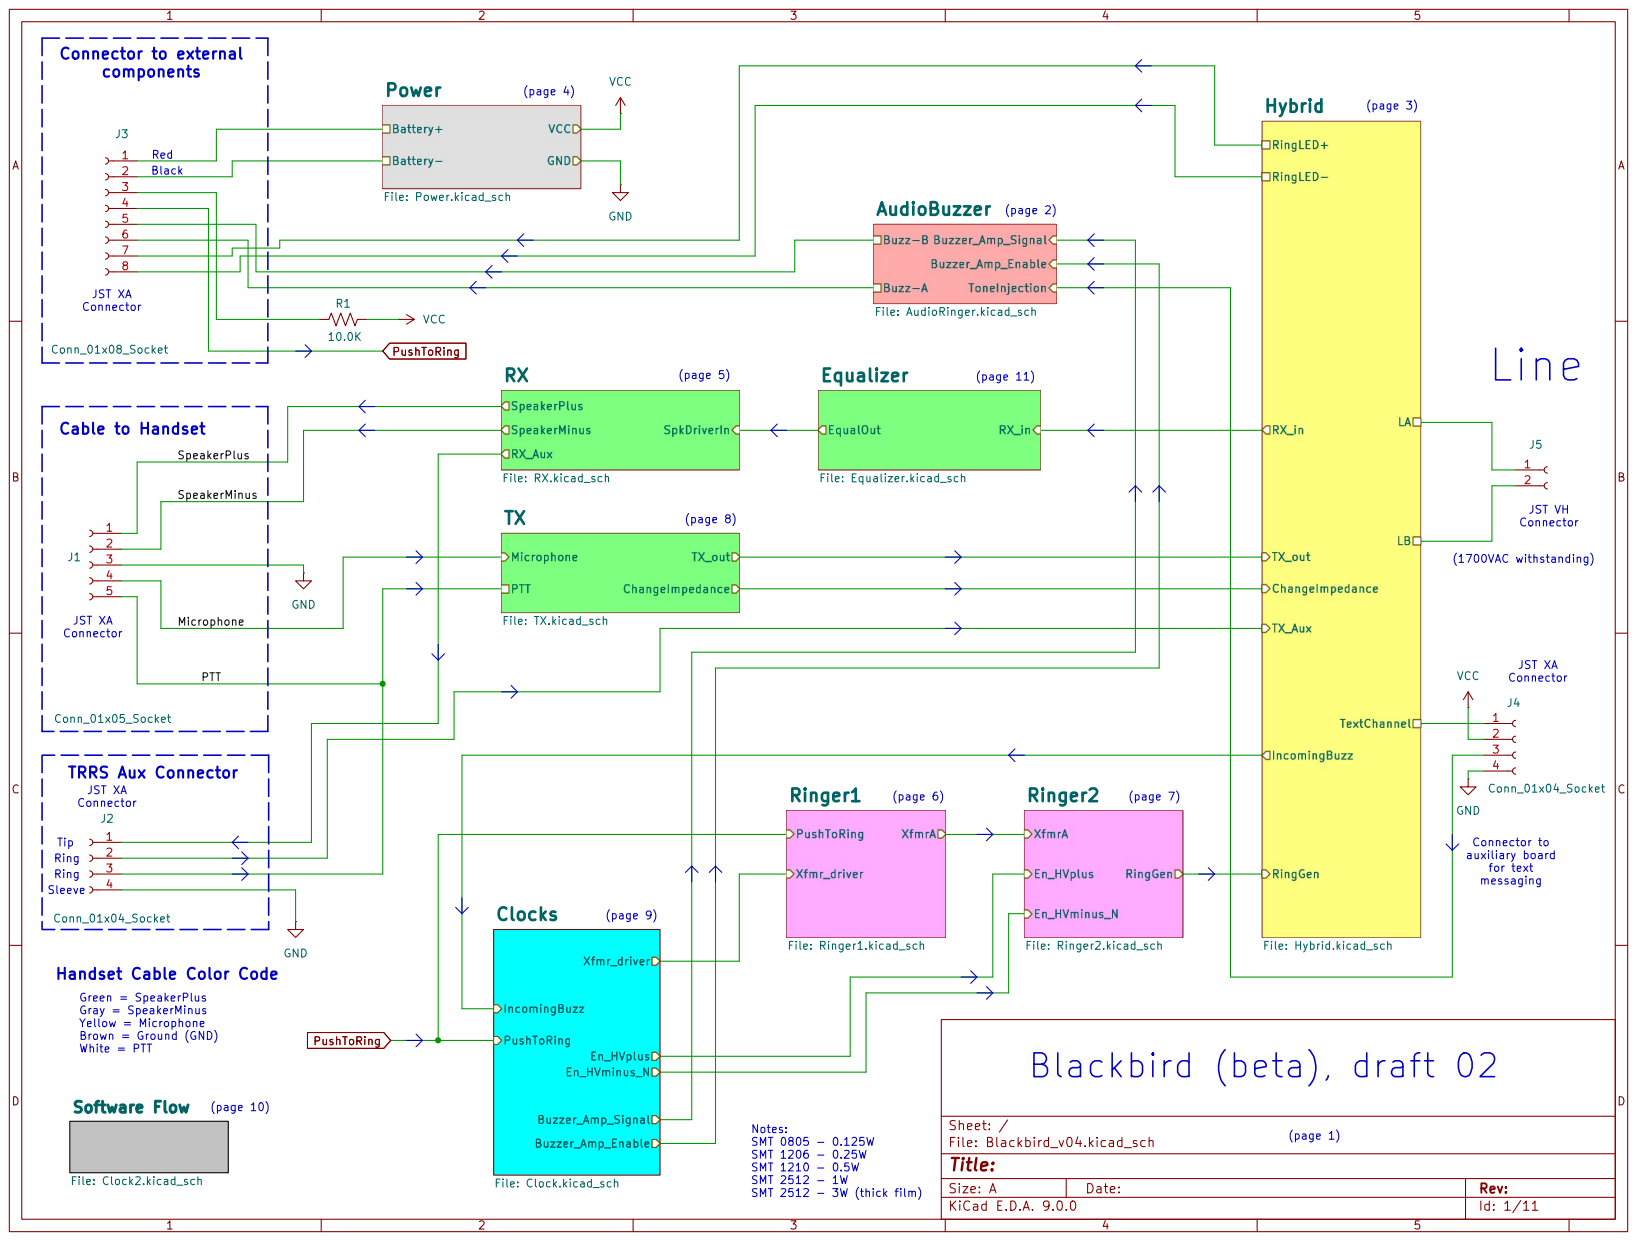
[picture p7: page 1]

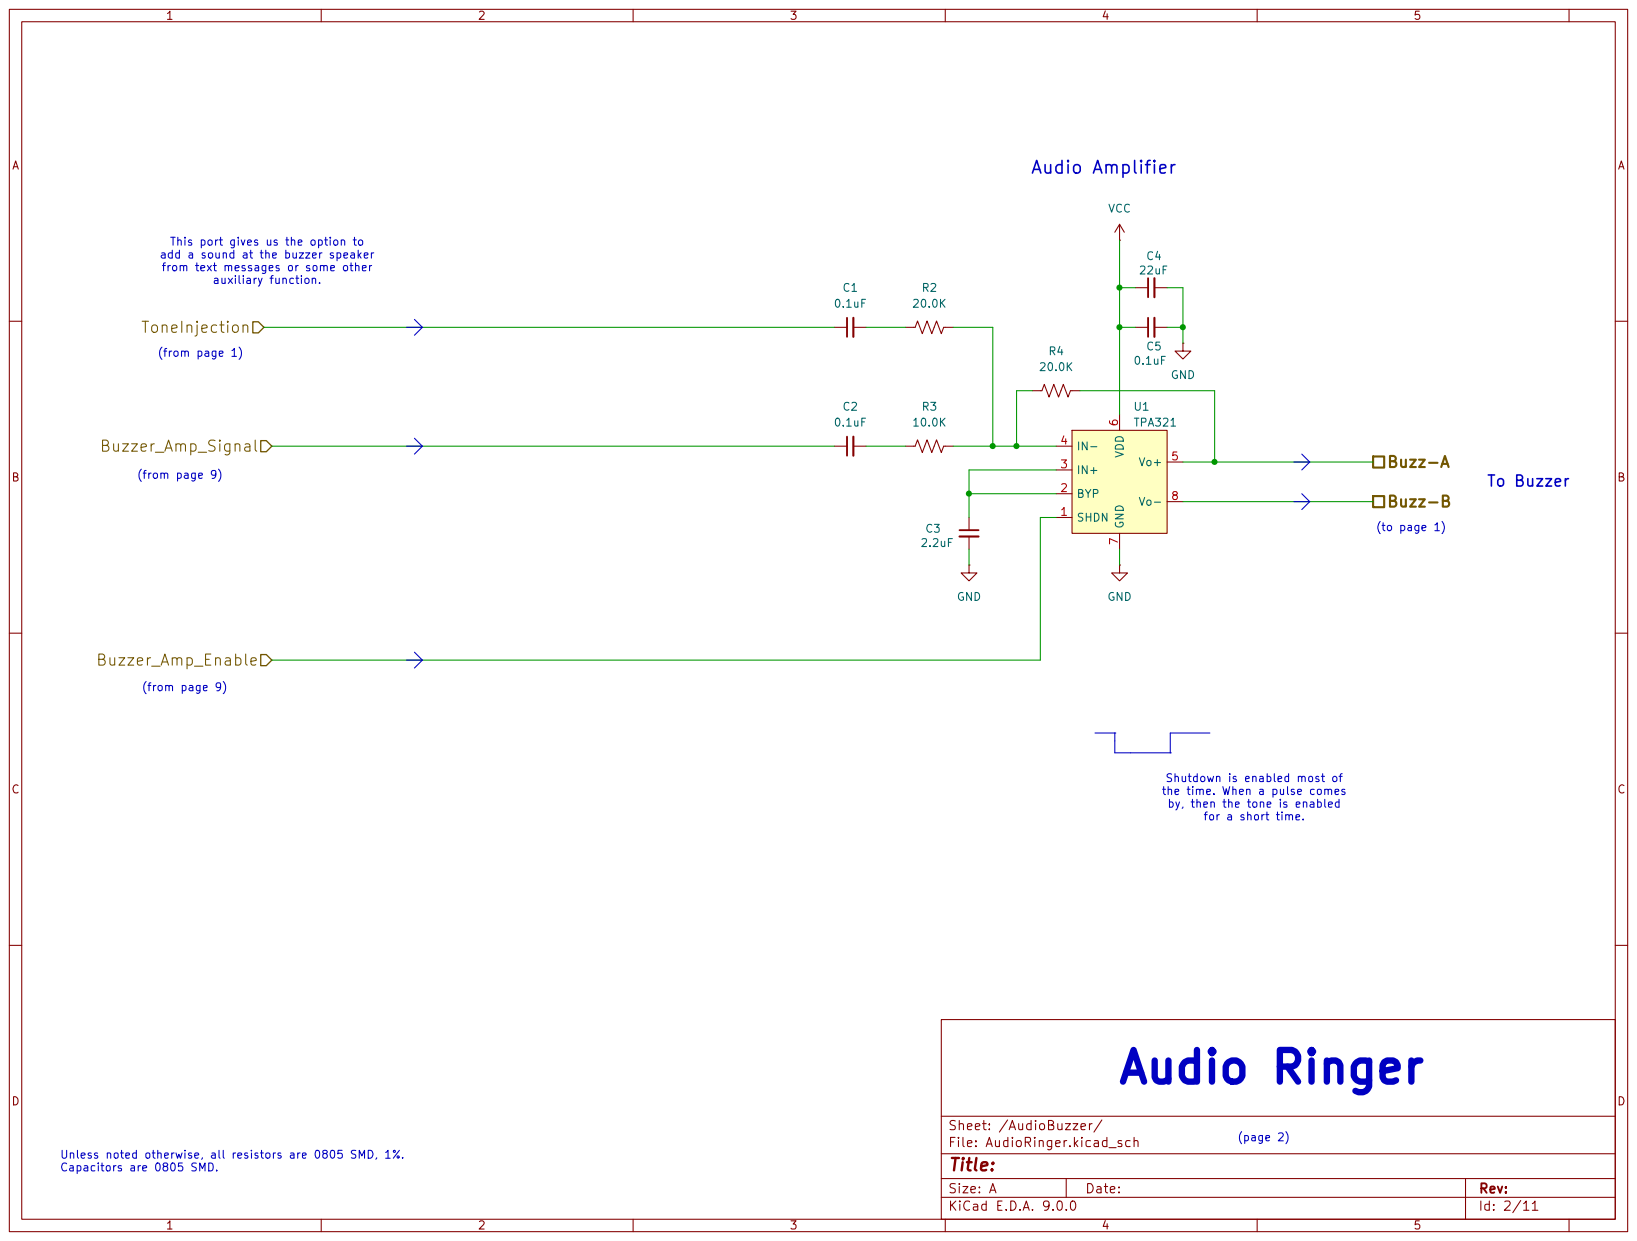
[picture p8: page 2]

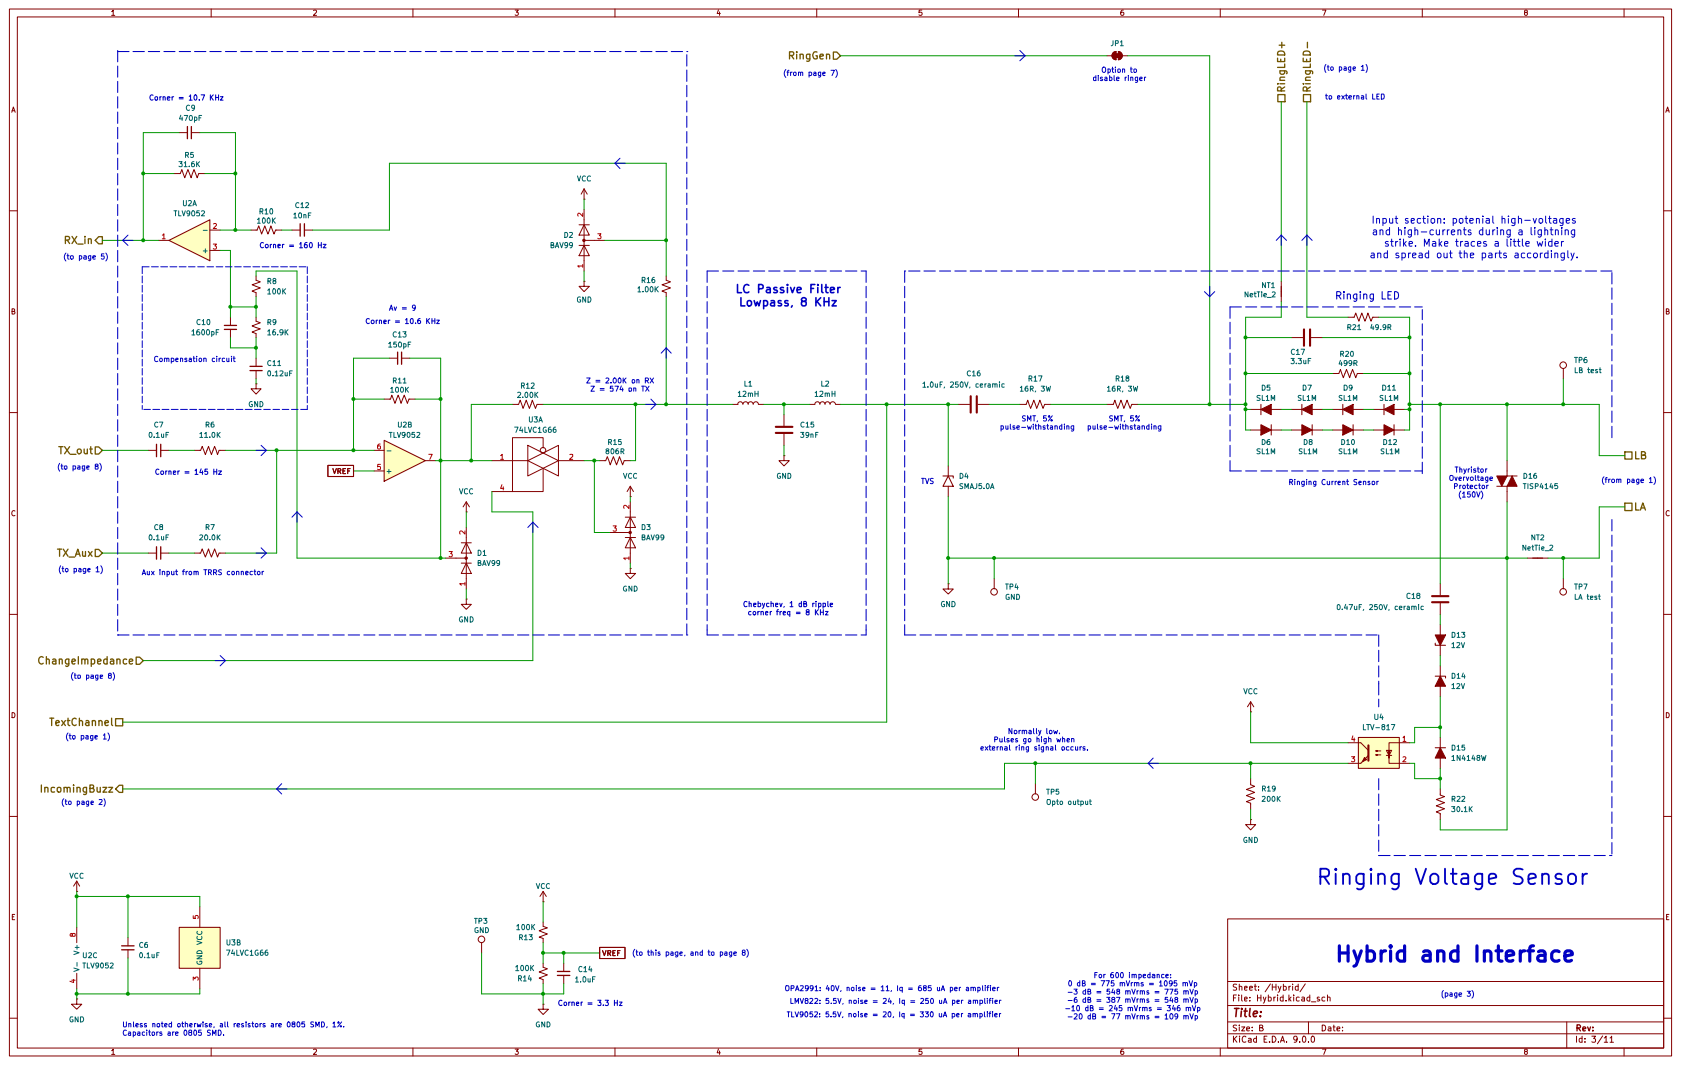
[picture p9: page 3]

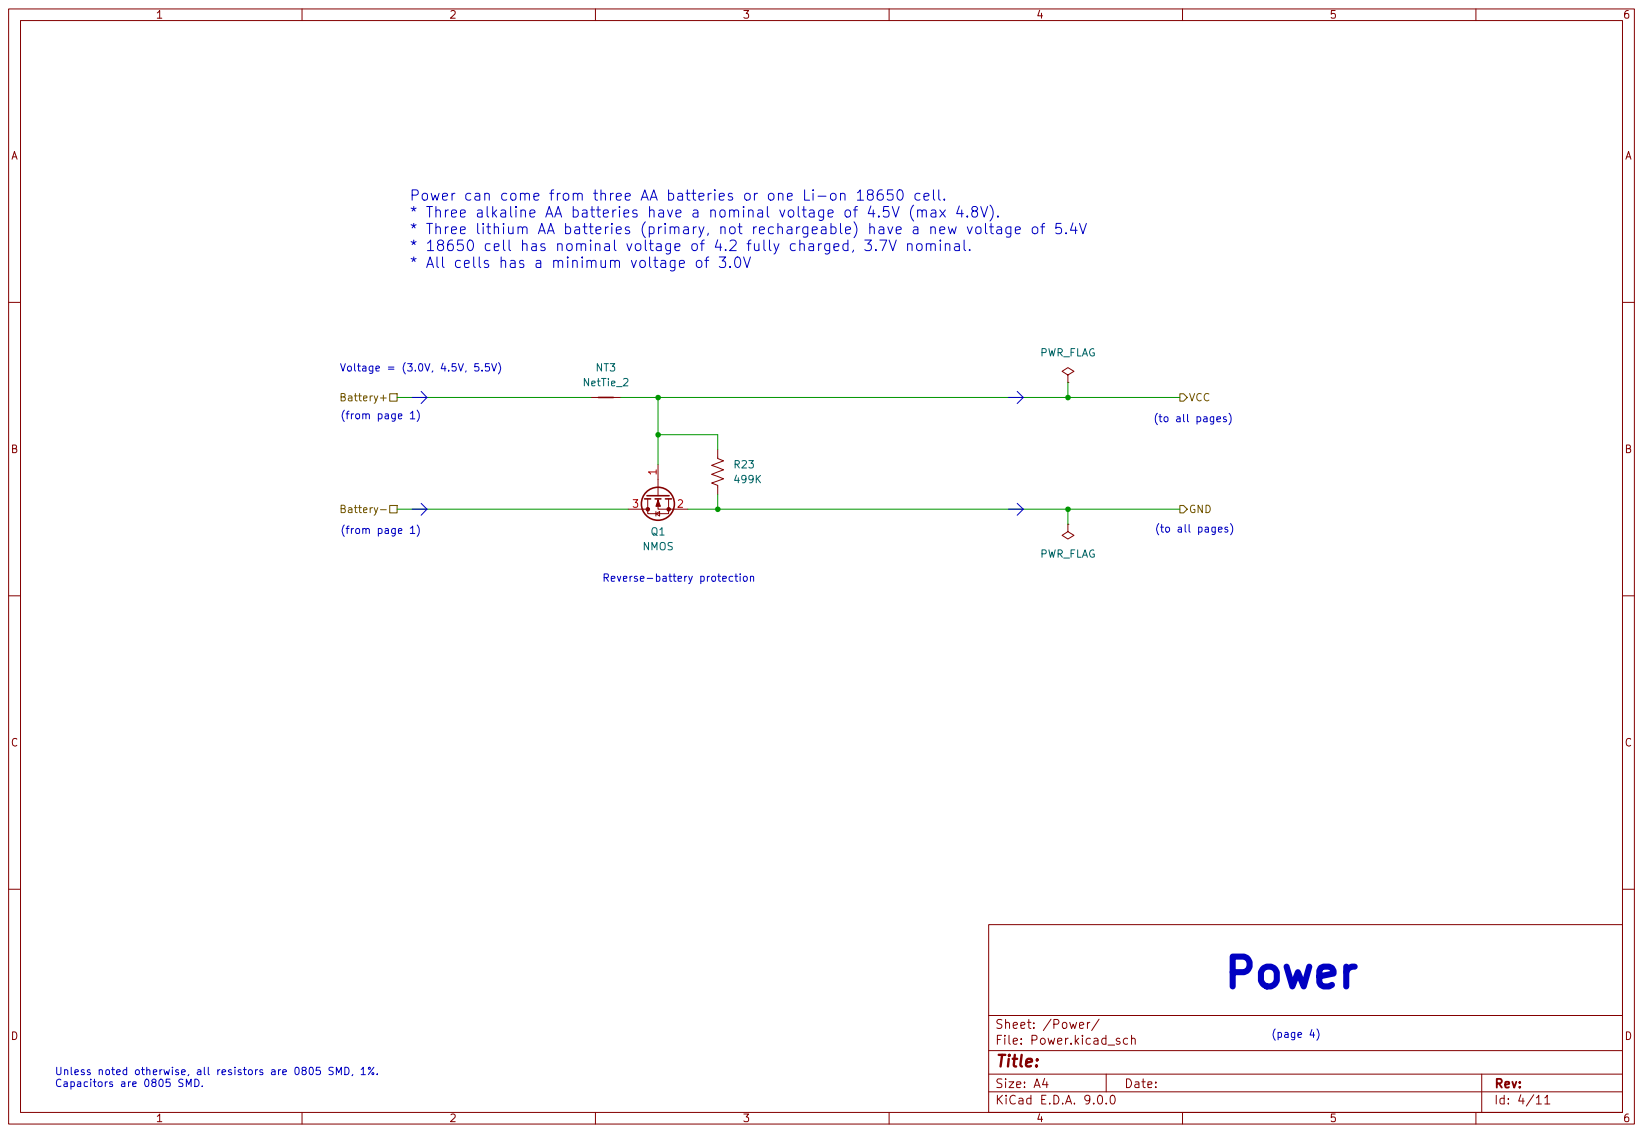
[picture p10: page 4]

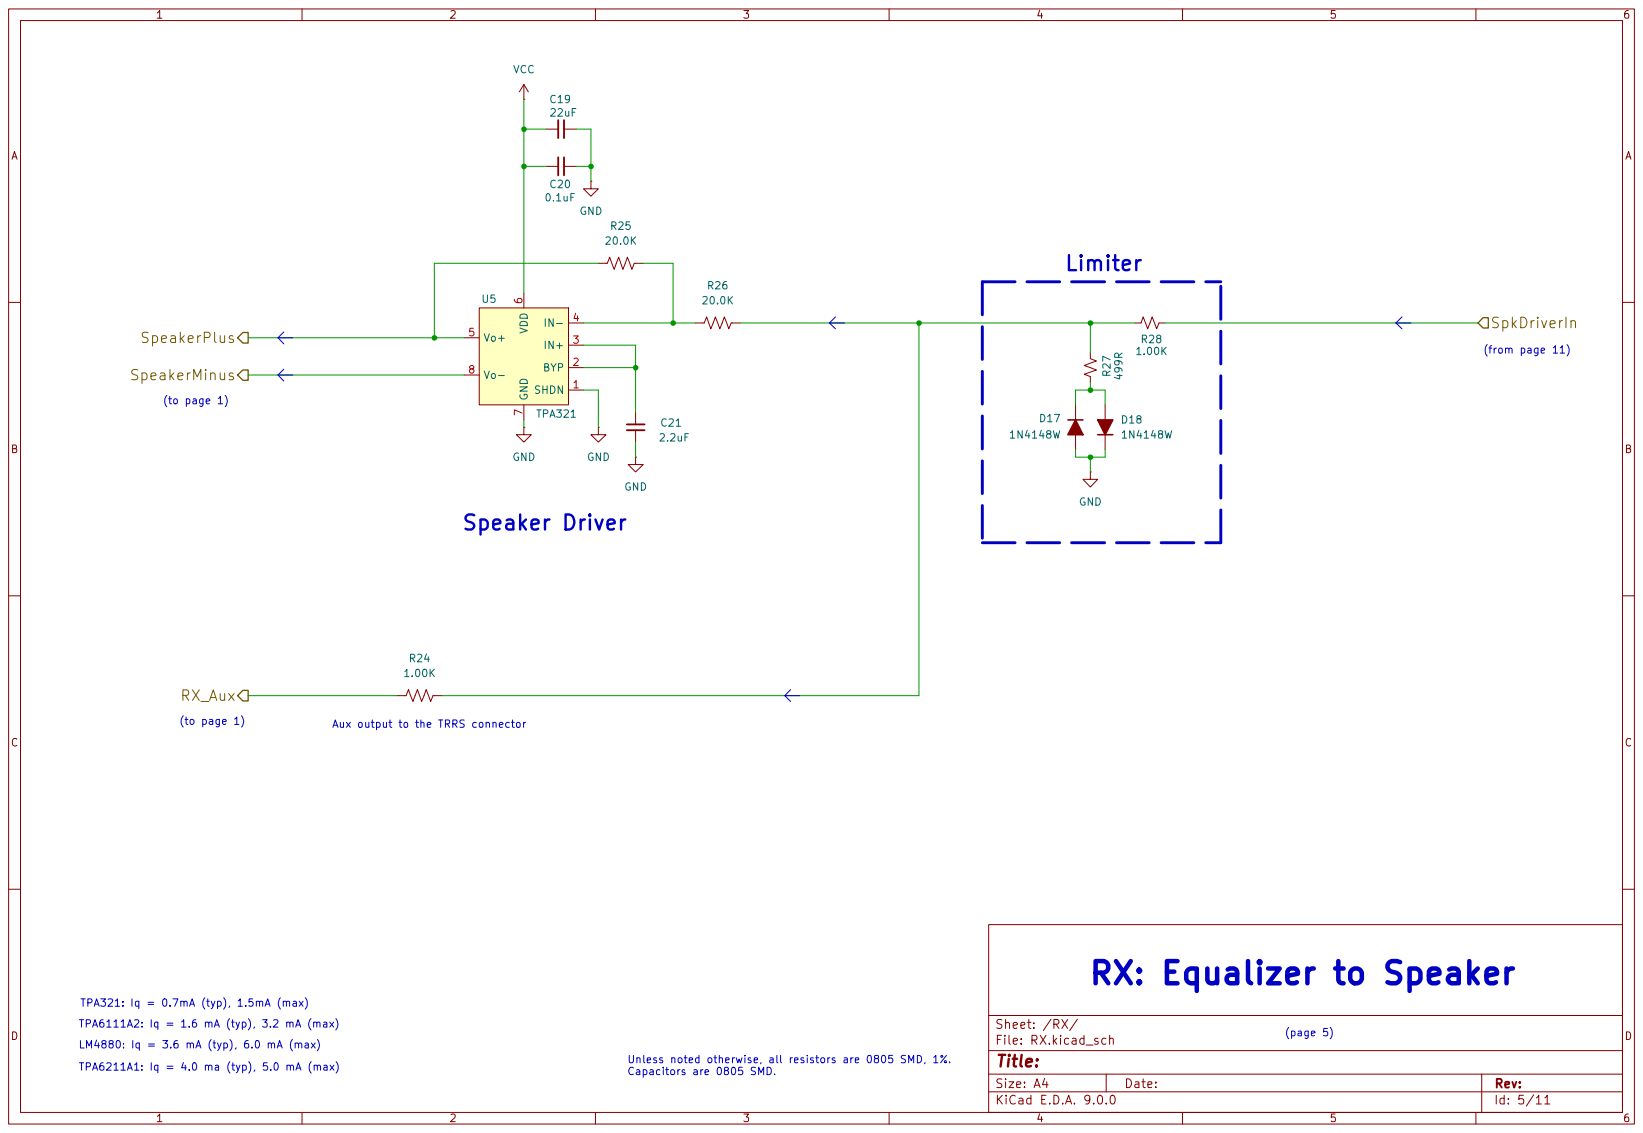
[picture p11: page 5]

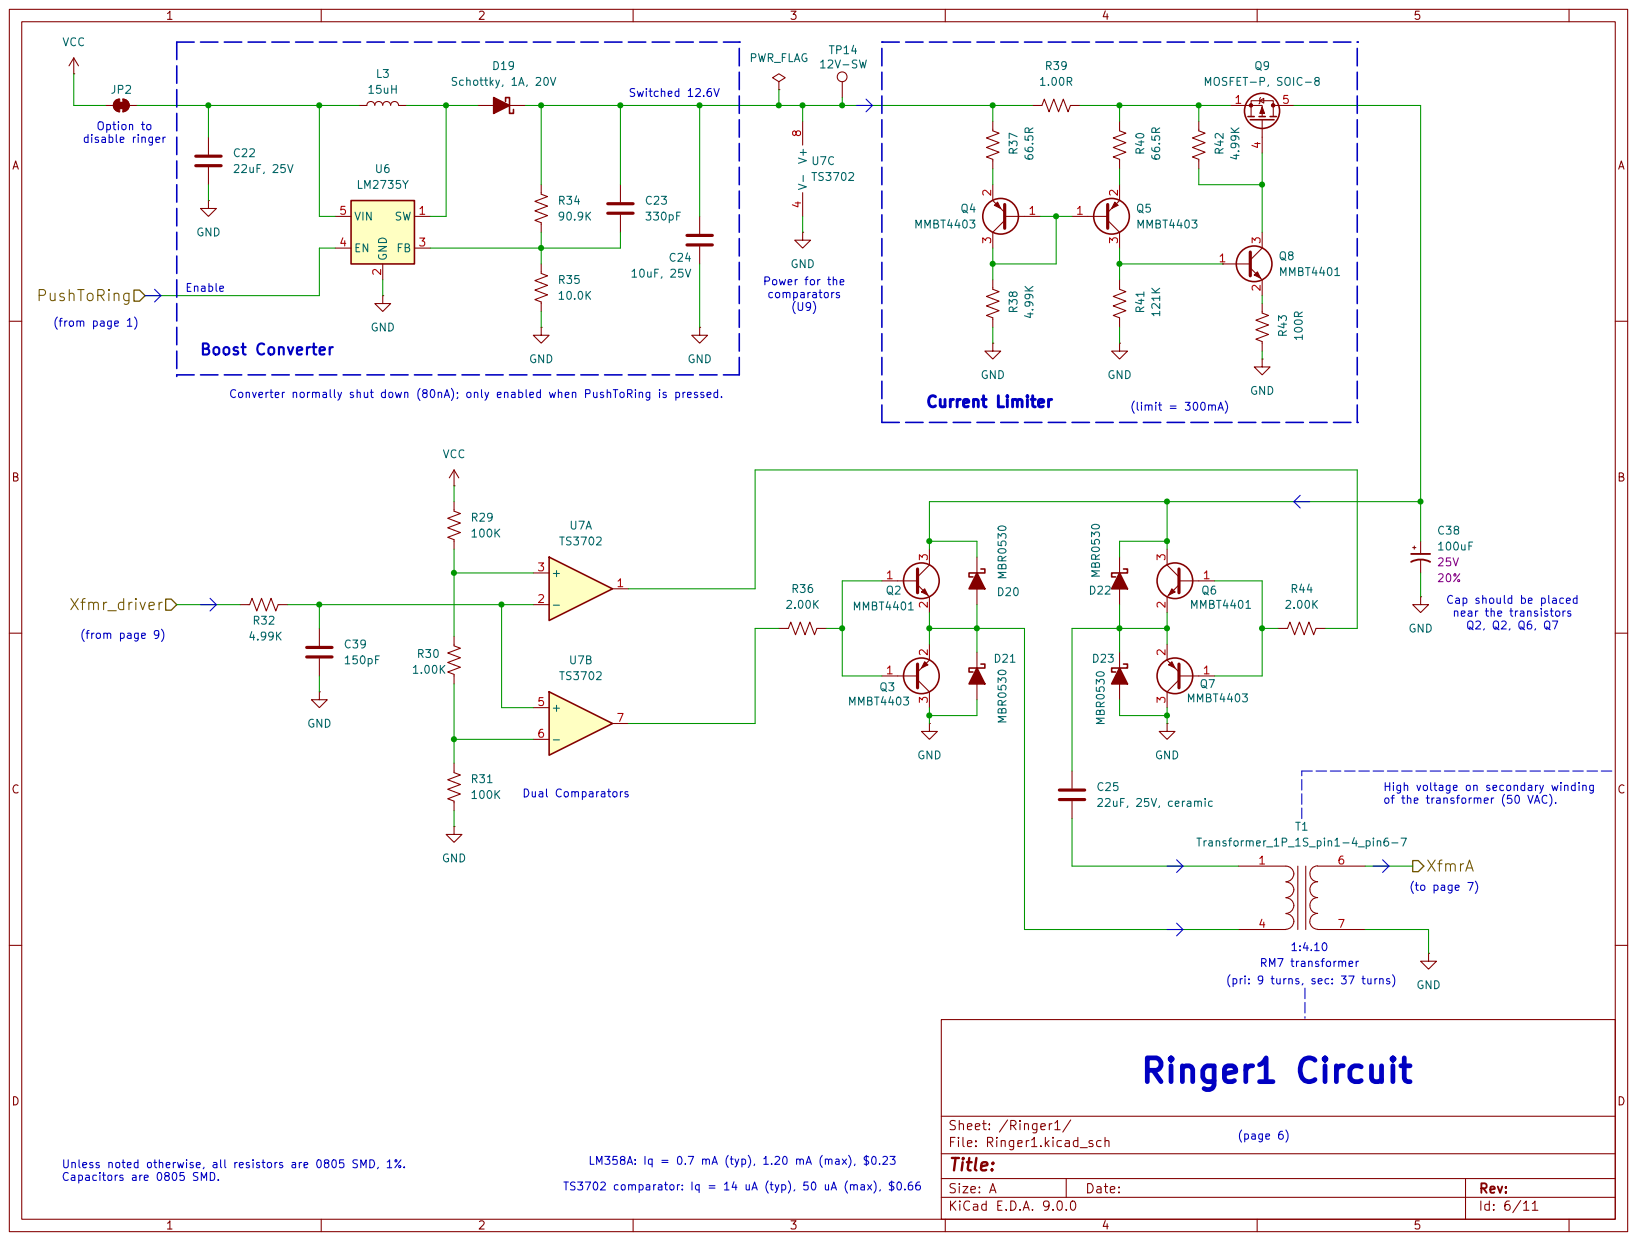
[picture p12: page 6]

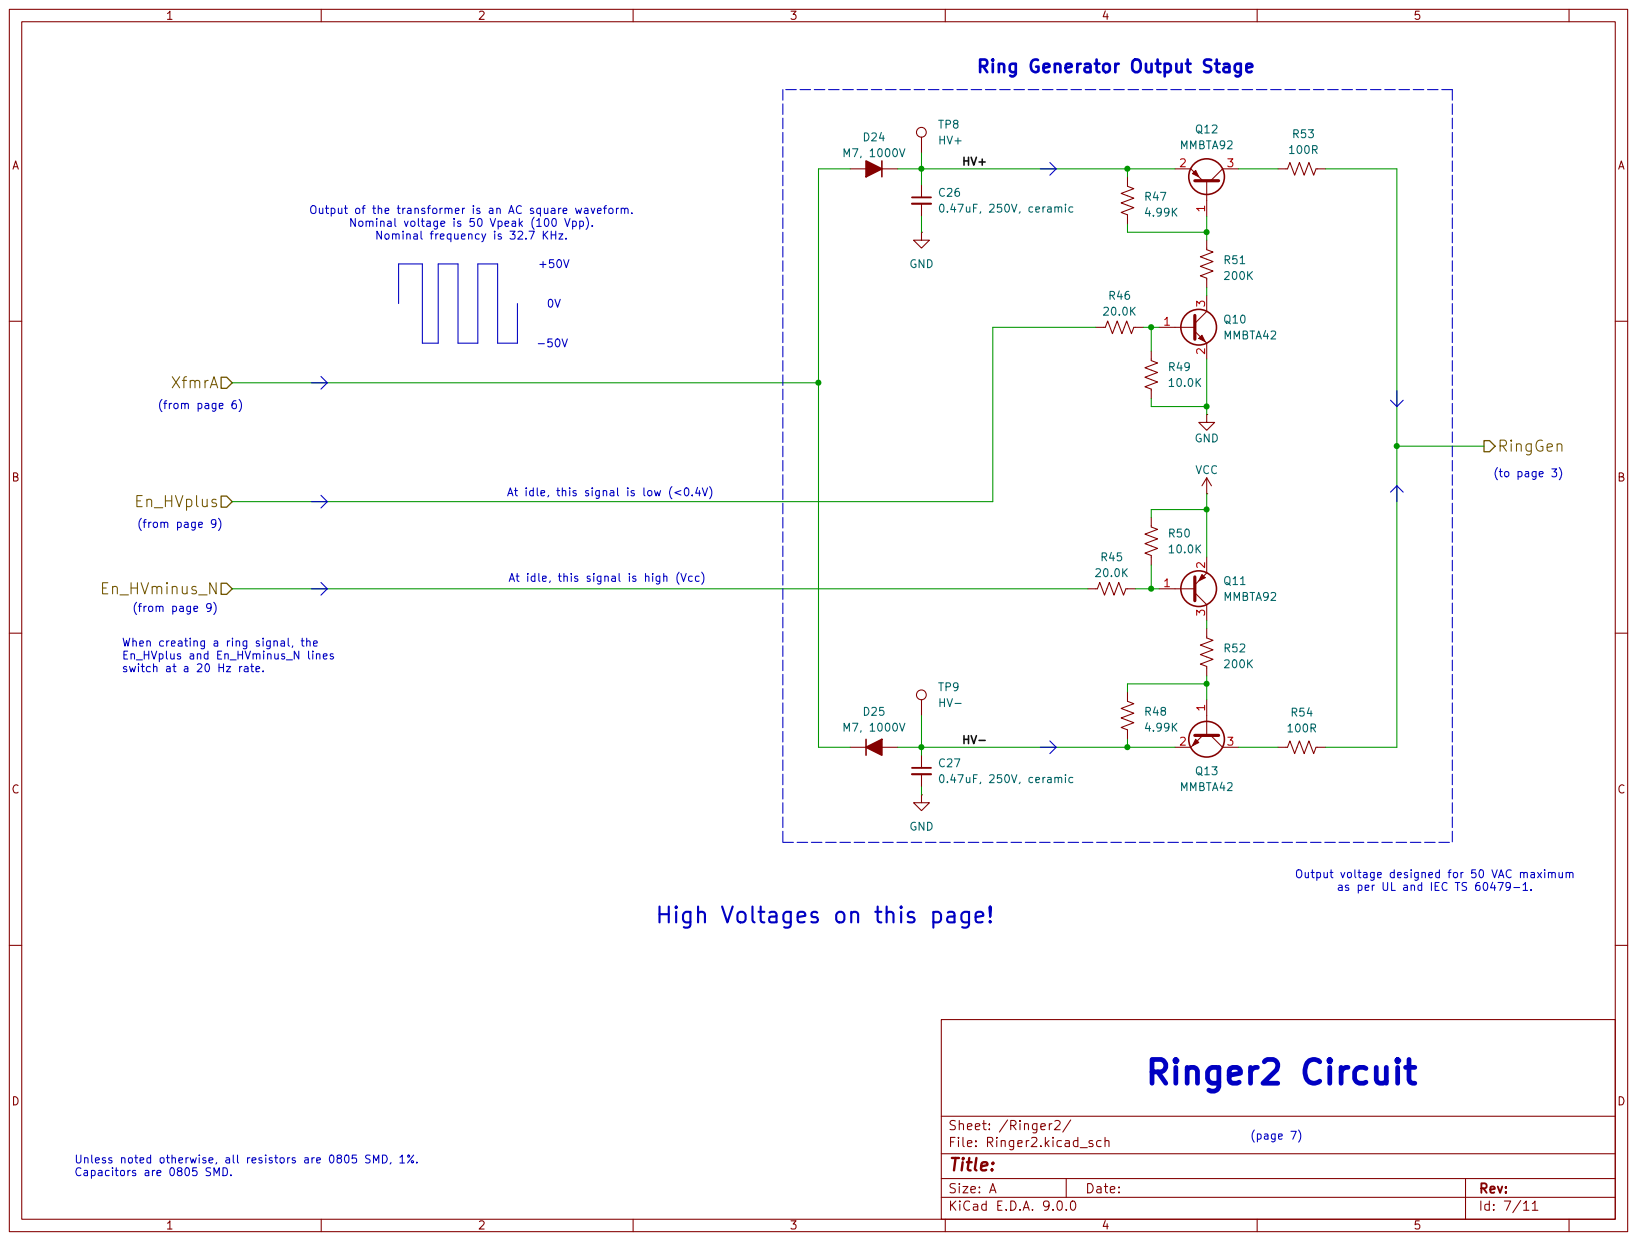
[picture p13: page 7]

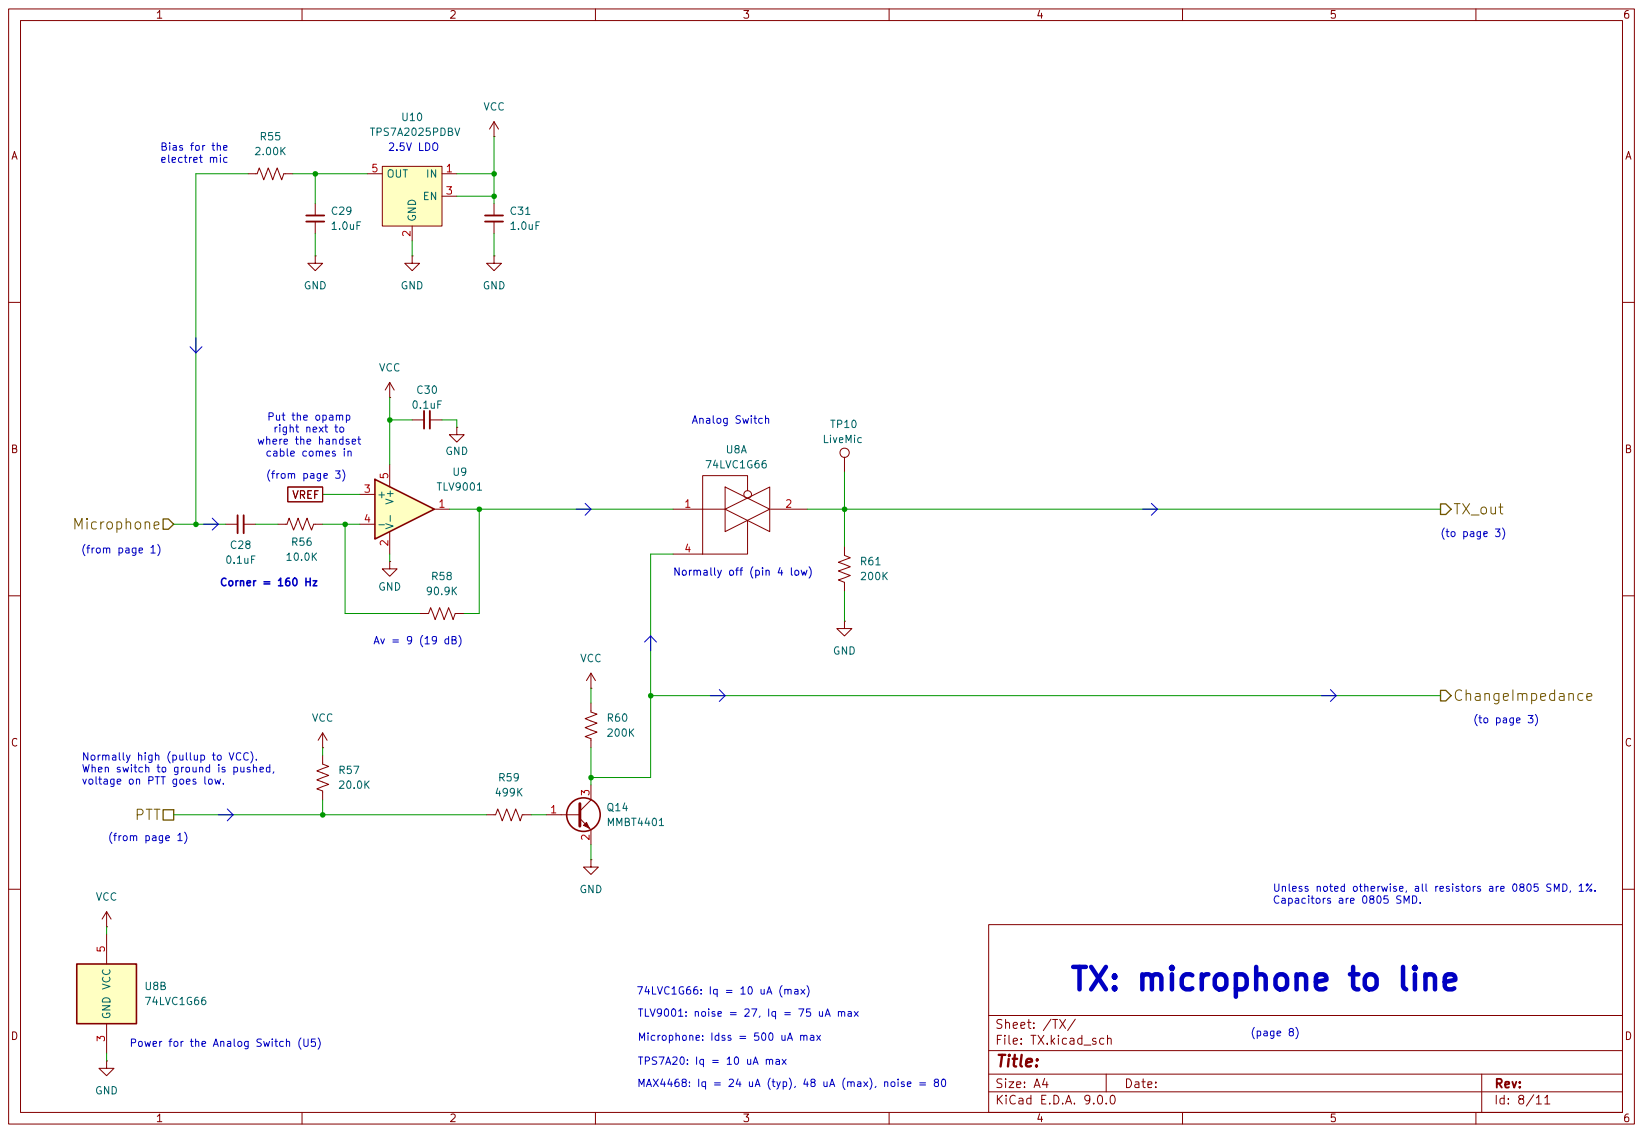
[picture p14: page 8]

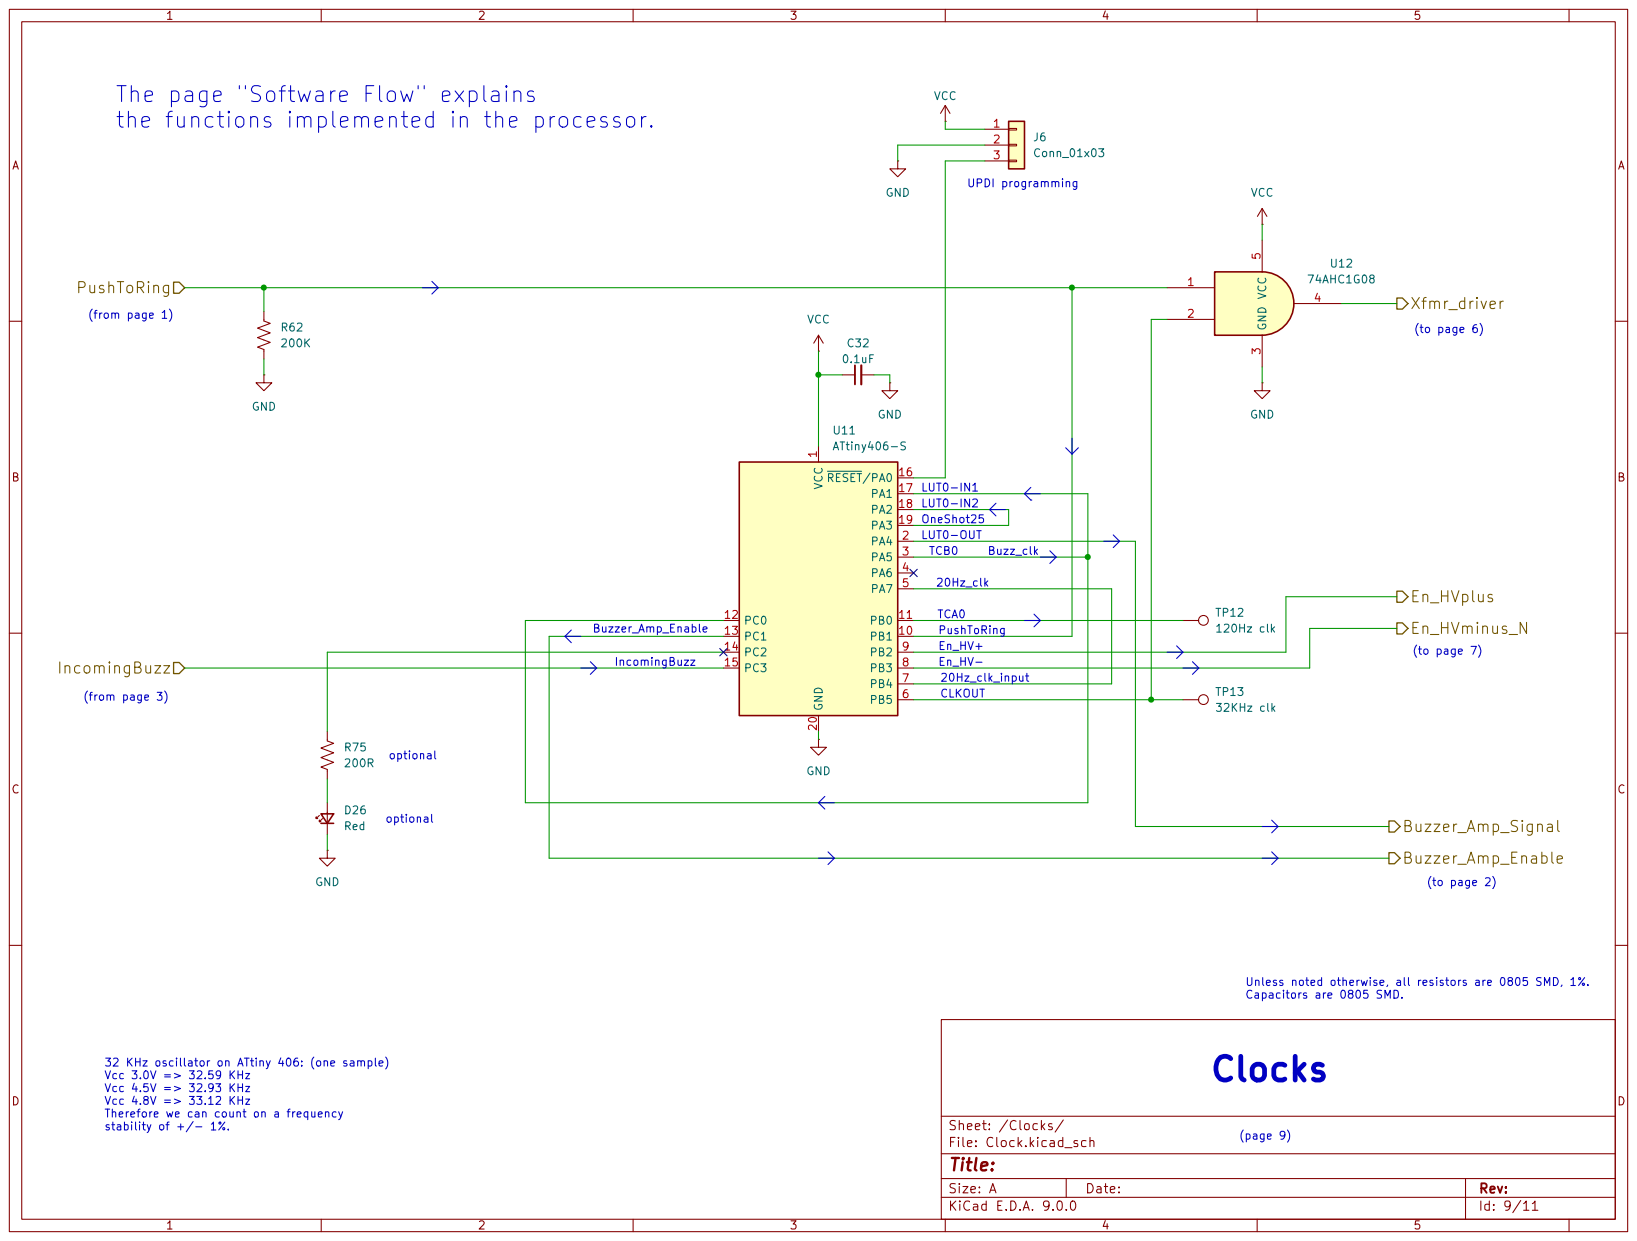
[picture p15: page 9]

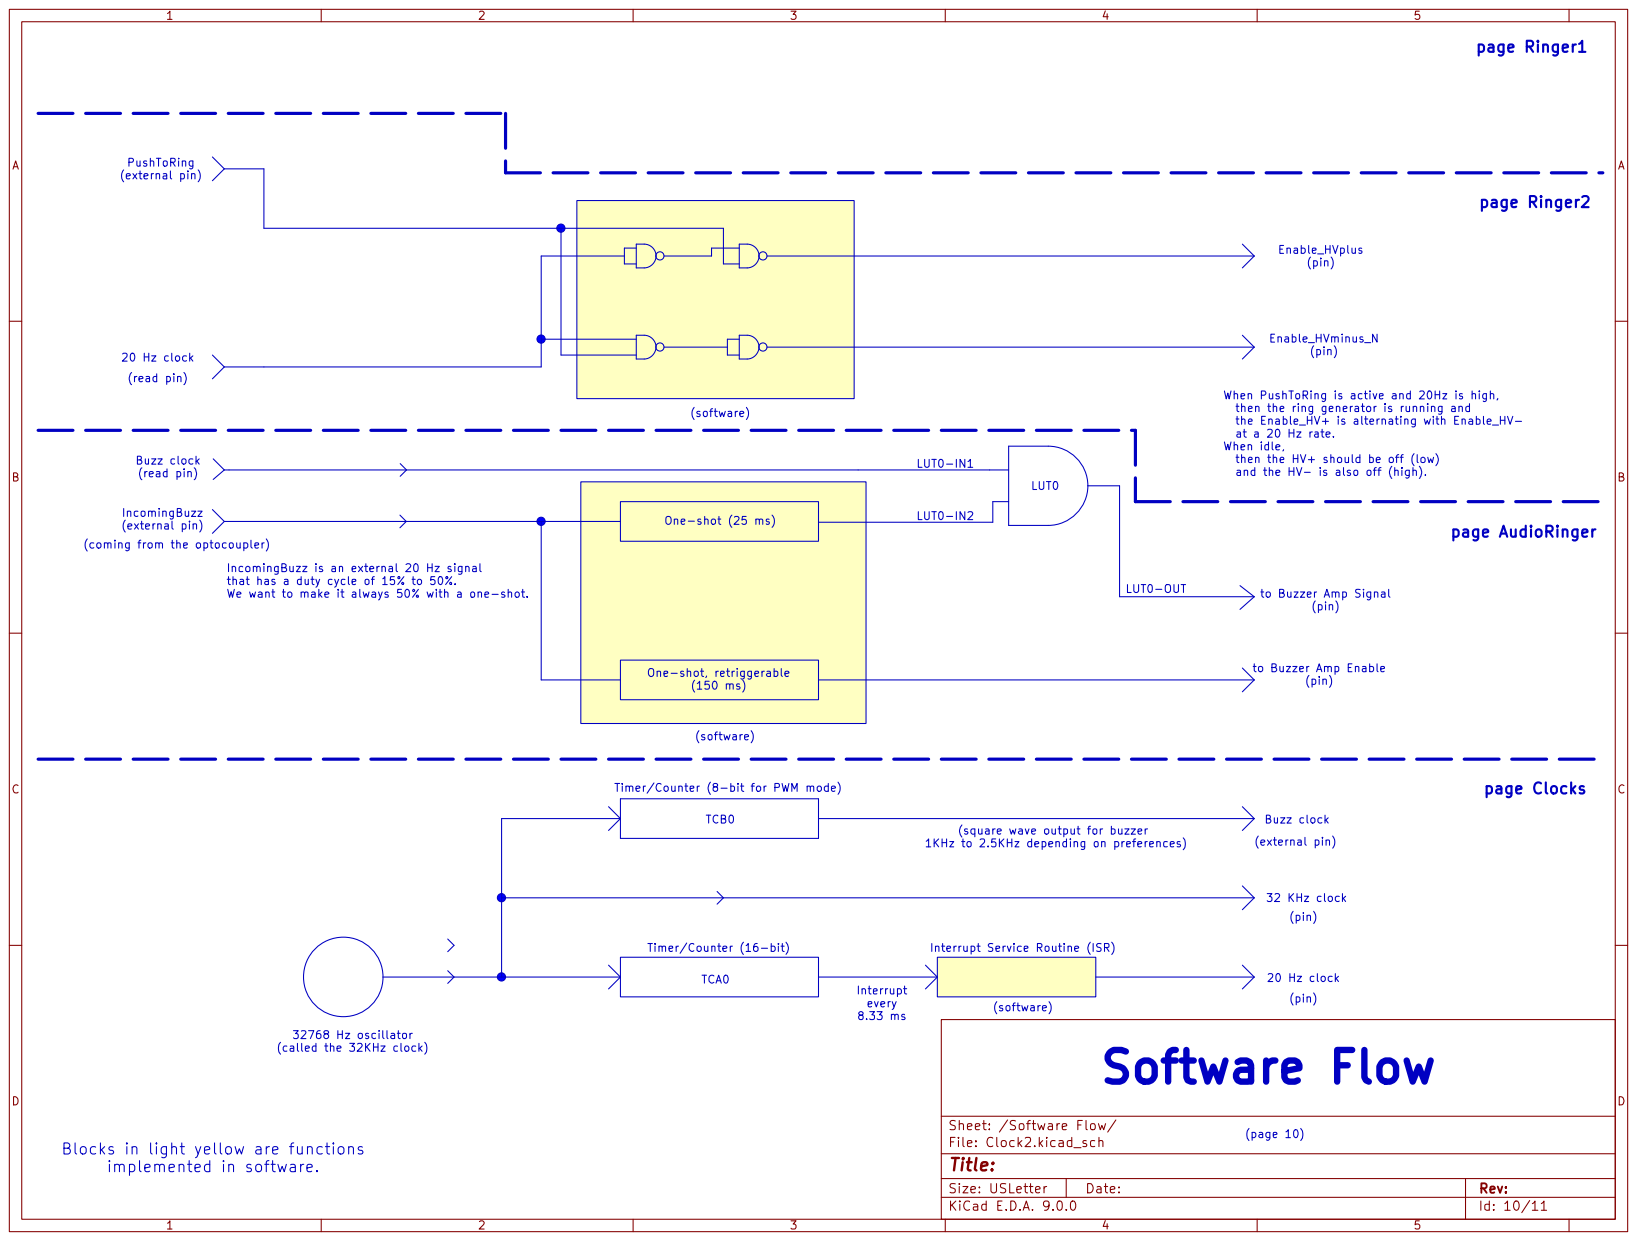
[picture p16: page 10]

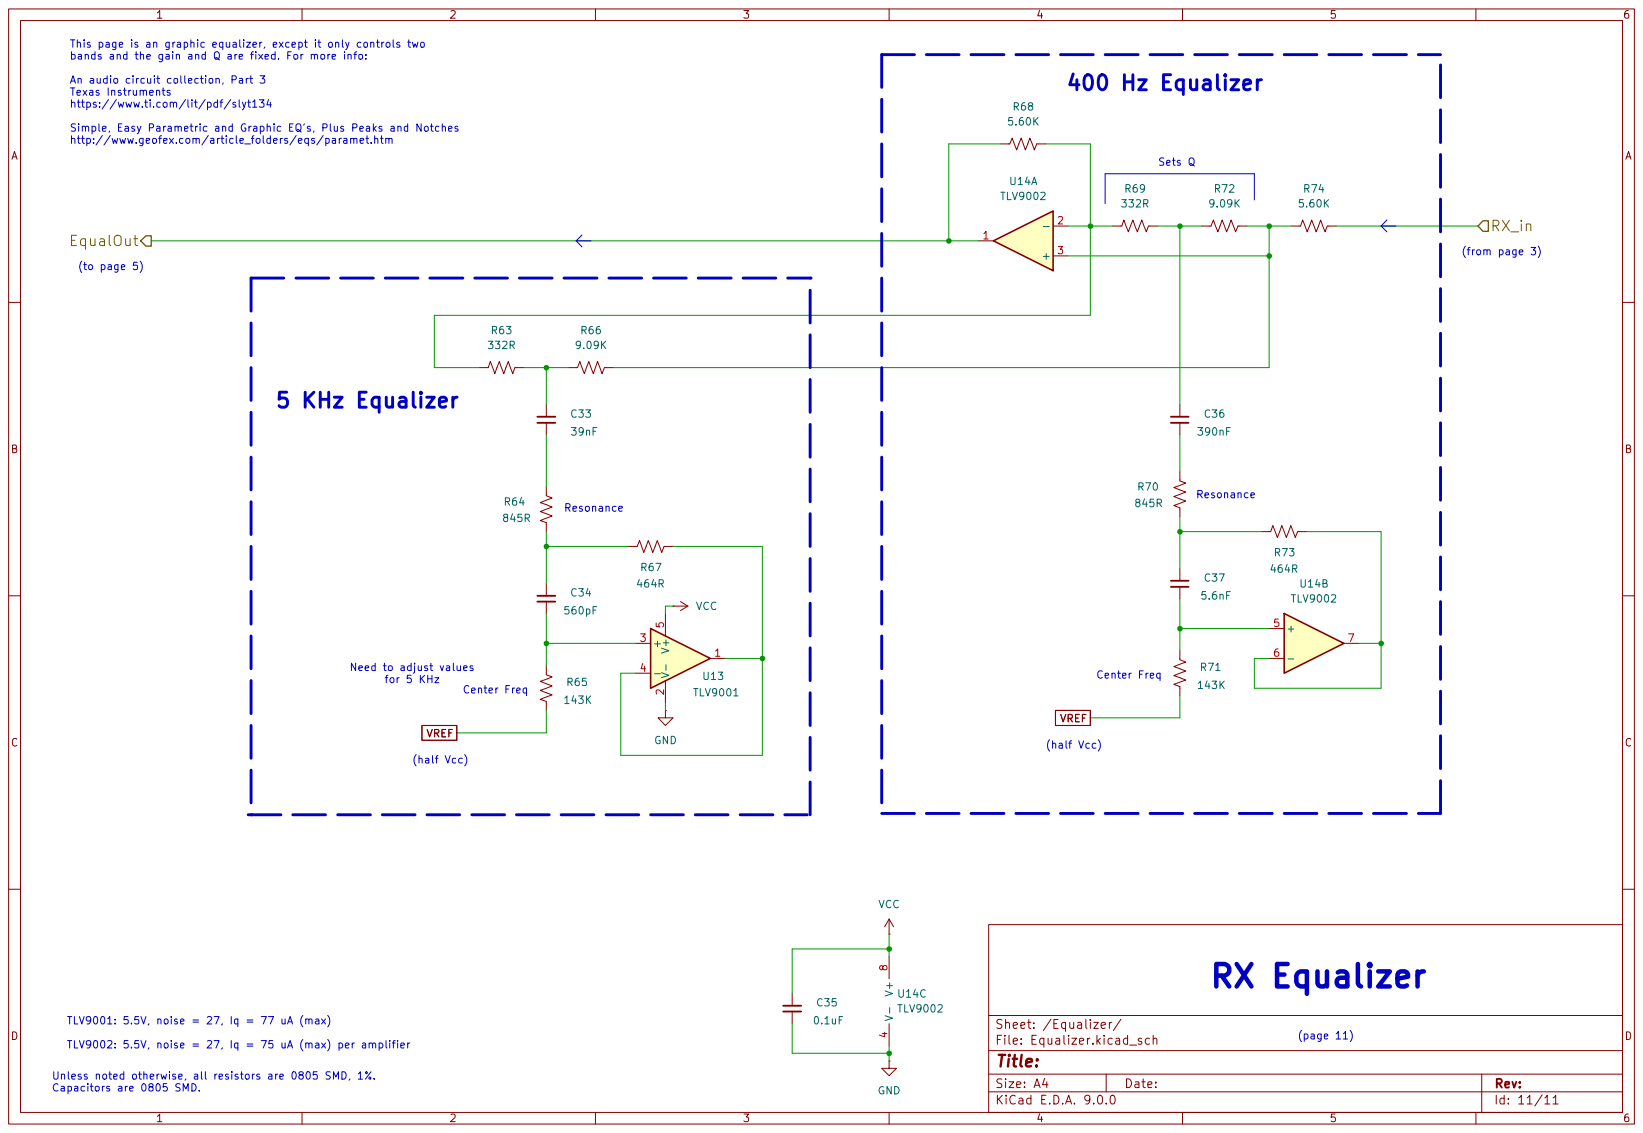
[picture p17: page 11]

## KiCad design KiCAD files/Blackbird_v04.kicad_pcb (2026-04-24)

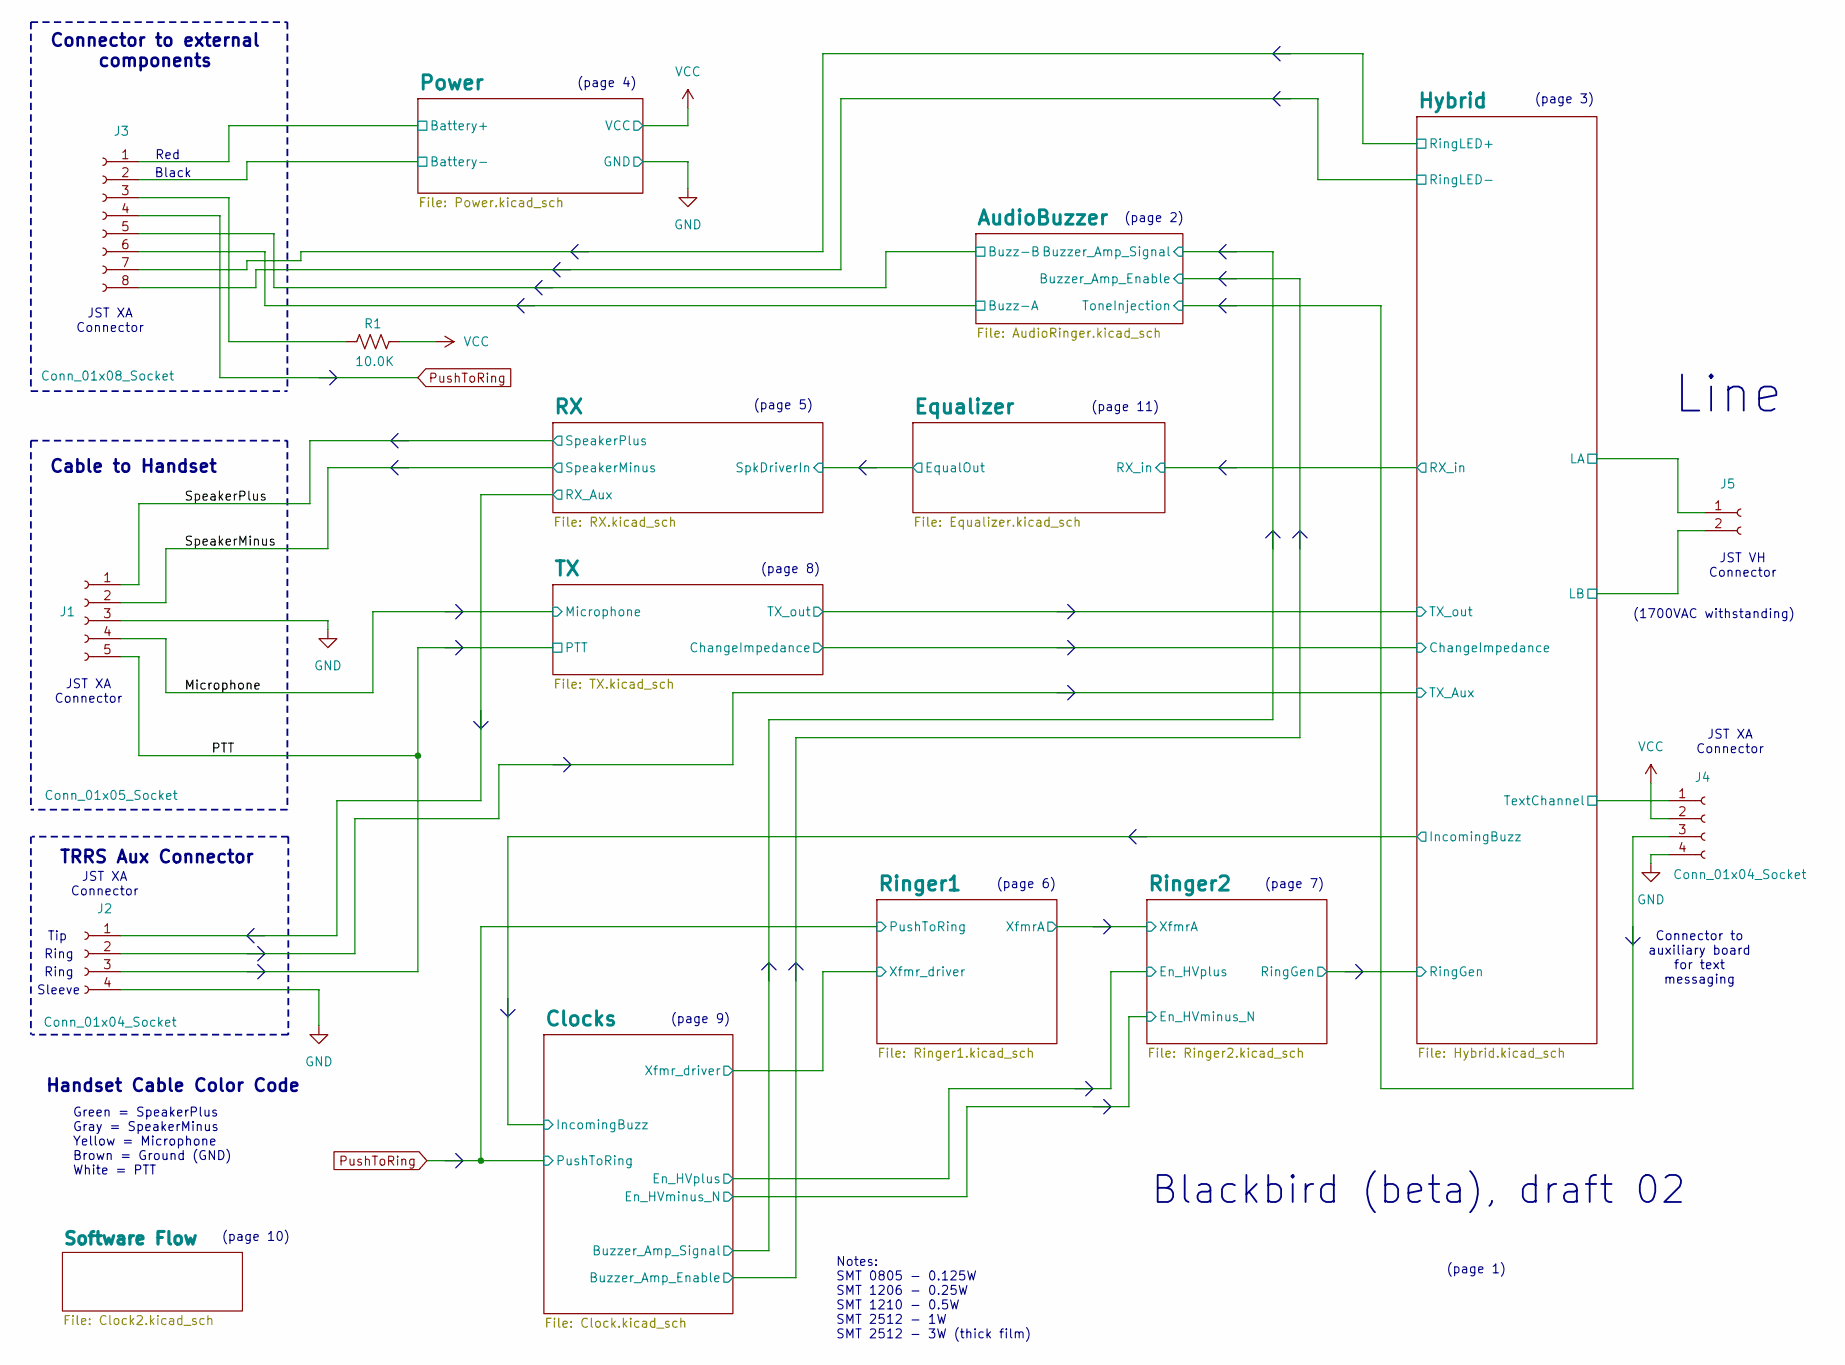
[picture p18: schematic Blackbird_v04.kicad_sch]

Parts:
J1: Conn_01x05_Socket; JST_XA_S05B-XASK-1_1x05_P2.50mm_Horizontal_w_housing
J2, J4: Conn_01x04_Socket; JST_XA_S04B-XASK-1_1x04_P2.50mm_Horizontal_w_housing
J3: Conn_01x08_Socket; JST_XA_S08B-XASK-1_1x08_P2.50mm_Horizontal_w_housing
J5: Conn_01x02_Socket; JST_VH_S2P-VH_1x02_P3.96mm_Horizontal_w_housing
R1: 10.0K; R_0805_2012Metric_Pad1.20x1.40mm_HandSolder

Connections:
/AudioBuzzer/Buzz-A: J3.6; also elsewhere on the board
/AudioBuzzer/Buzz-B: J3.5; also elsewhere on the board
/AudioBuzzer/ToneInjection: J4.3; also elsewhere on the board
/Hybrid/LA: J5.1; also elsewhere on the board
/Hybrid/LB: J5.2; also elsewhere on the board
/Hybrid/RingLED+: J3.7; also elsewhere on the board
/Hybrid/RingLED-: J3.8; also elsewhere on the board
/Hybrid/TX_Aux: J2.2; also elsewhere on the board
/Hybrid/TextChannel: J4.1; also elsewhere on the board
/Microphone: J1.4; also elsewhere on the board
/PTT: J1.5, J2.3; also elsewhere on the board
/Power/Battery+: J3.1; also elsewhere on the board
/Power/Battery-: J3.2; also elsewhere on the board
/RX/RX_Aux: J2.1; also elsewhere on the board
/SpeakerMinus: J1.2; also elsewhere on the board
/SpeakerPlus: J1.1; also elsewhere on the board
GND: J1.3, J2.4, J4.4; also elsewhere on the board
unnamed: J3.3, R1.1
PushToRing: J3.4; also elsewhere on the board
VCC: J4.2, R1.2; also elsewhere on the board

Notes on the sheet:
(page 4)
(page 10)
(page 5)
JST XA Connector
(1700VAC withstanding)
Tip
Cable to Handset
Sleeve
JST VH Connector
(page 8)
Green = SpeakerPlus Gray = SpeakerMinus Yellow = Microphone Brown = Ground (GND) White = PTT
(page 7)
Connector to auxiliary board for text messaging
Notes: SMT 0805 - 0.125W SMT 1206 - 0.25W SMT 1210 - 0.5W SMT 2512 - 1W SMT 2512 - 3W (thick film)
(page 11)
(page 9)
(page 1)
Ring
Red
TRRS Aux Connector
Black
(page 2)
Handset Cable Color Code
Connector to external components
(page 3)
Line
(page 6)
Blackbird (beta), draft 02

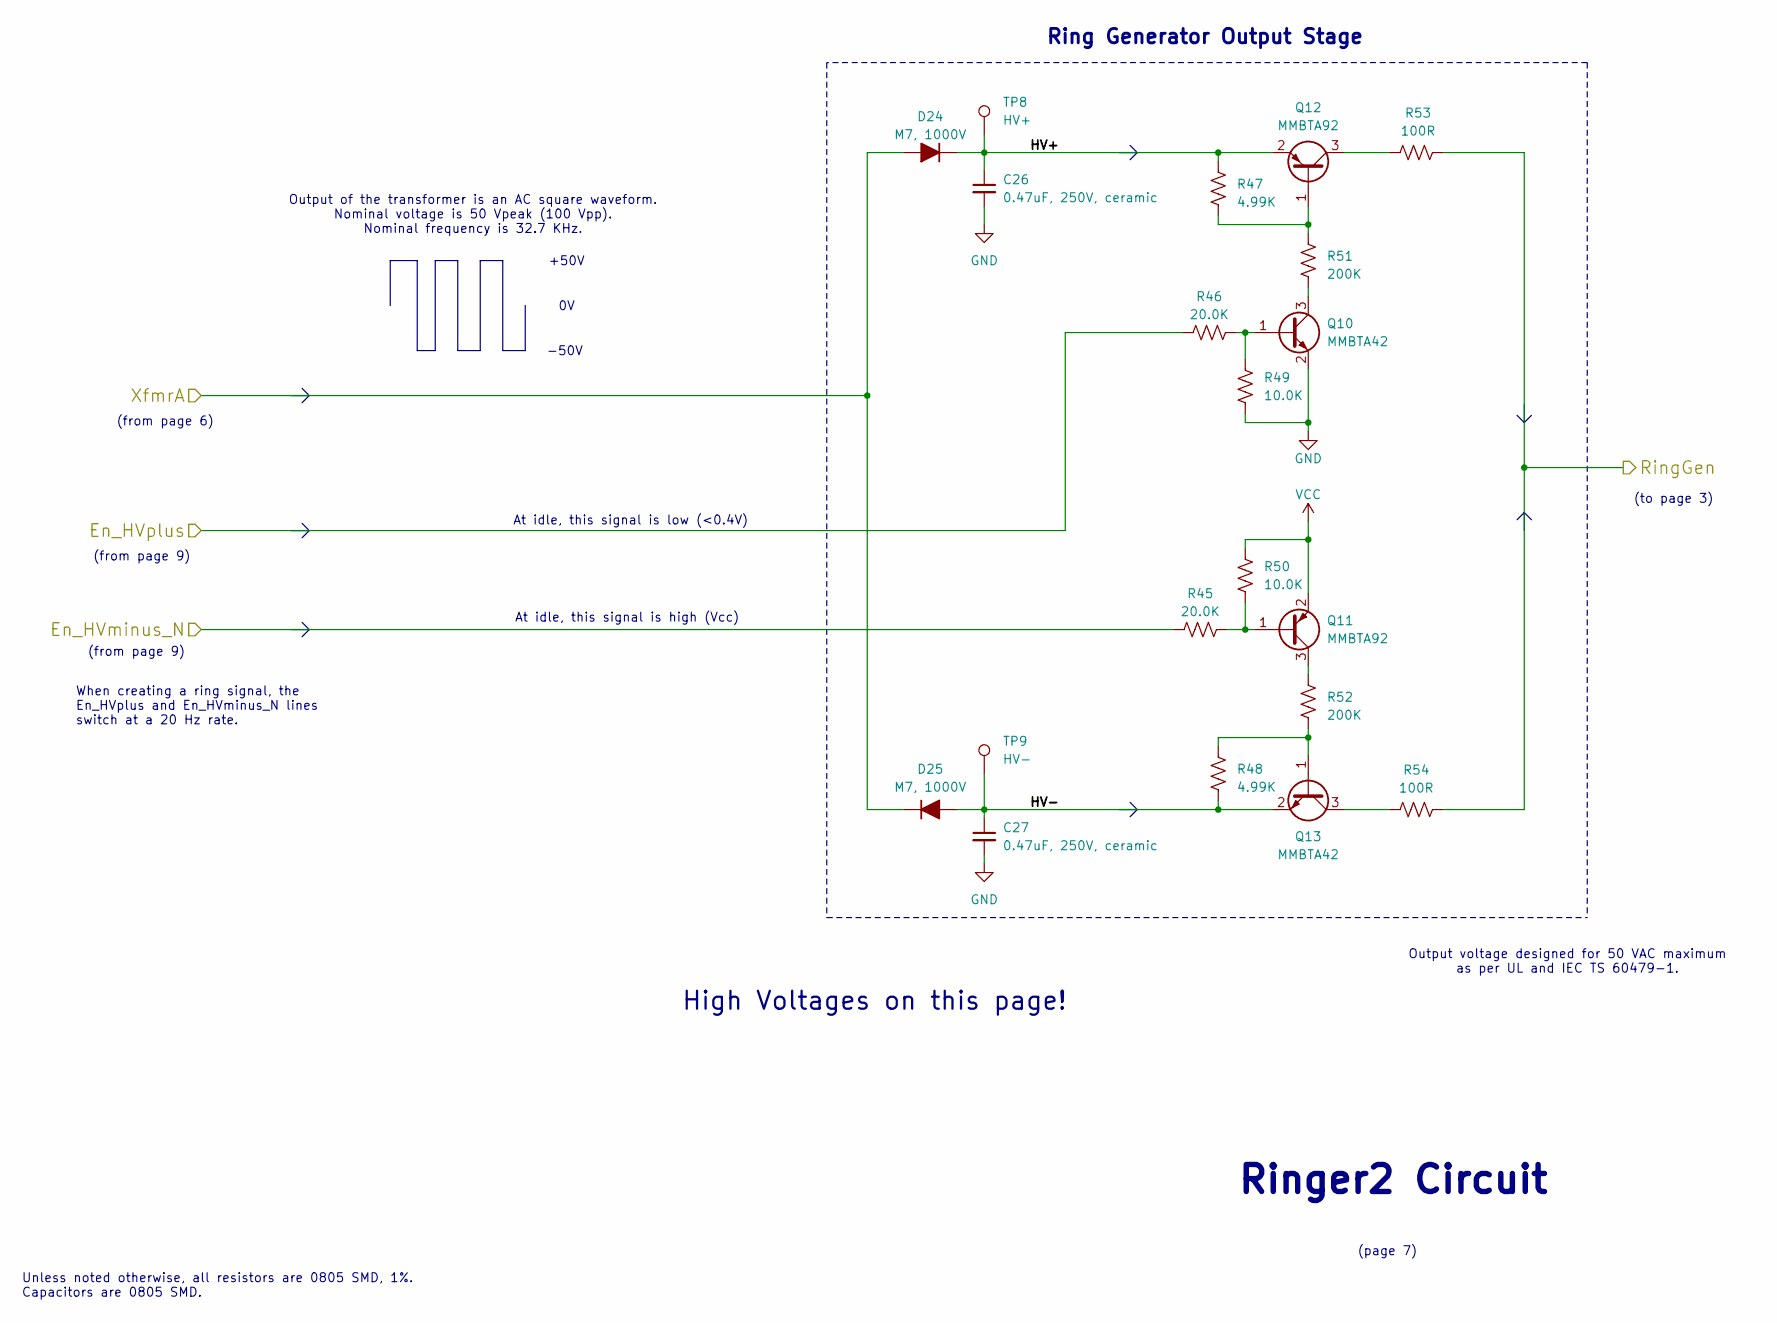
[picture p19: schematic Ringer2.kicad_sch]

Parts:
C26, C27: 0.47uF, 250V, ceramic; C_1812_4532Metric_Pad1.57x3.40mm_HandSolder
D24, D25: M7, 1000V; D_SMA_Handsoldering
Q10, Q13: MMBTA42; SOT-23_Handsoldering
Q11, Q12: MMBTA92; SOT-23_Handsoldering
R45, R46: 20.0K; R_0805_2012Metric_Pad1.20x1.40mm_HandSolder
R47, R48: 4.99K; R_0805_2012Metric_Pad1.20x1.40mm_HandSolder
R49, R50: 10.0K; R_0805_2012Metric_Pad1.20x1.40mm_HandSolder
R51, R52: 200K; R_0805_2012Metric_Pad1.20x1.40mm_HandSolder
R53, R54: 100R; R_1210_3225Metric_Pad1.30x2.65mm_HandSolder
TP8: HV+; Test_point_47mil_scope_probe
TP9: HV-; Test_point_47mil_scope_probe

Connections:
/Clocks/En_HVminus_N: R45.1; also elsewhere on the board
/Clocks/En_HVplus: R46.1; also elsewhere on the board
/Hybrid/RingGen: R53.2, R54.2; also elsewhere on the board
/Ringer1/XfmrA: D24.2 (A), D25.1 (K); also elsewhere on the board
/Ringer2/HV+: C26.1, D24.1 (K), Q12.2 (E), R47.1, TP8.1
/Ringer2/HV-: C27.1, D25.2 (A), Q13.2 (E), R48.2, TP9.1
GND: C26.2, C27.2, Q10.2 (E), R49.1; also elsewhere on the board
unnamed: Q10.1 (B), R46.2, R49.2
unnamed: Q10.3 (C), R51.2
unnamed: Q11.1 (B), R45.2, R50.1
unnamed: Q11.3 (C), R52.1
unnamed: Q12.1 (B), R47.2, R51.1
unnamed: Q12.3 (C), R53.1
unnamed: Q13.1 (B), R48.1, R52.2
unnamed: Q13.3 (C), R54.1
VCC: Q11.2 (E), R50.2; also elsewhere on the board

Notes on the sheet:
At idle, this signal is high (Vcc)
When creating a ring signal, the En_HVplus and En_HVminus_N lines switch at a 20 Hz rate.
(from page 6)
Ringer2 Circuit
(from page 9)
(to page 3)
Output of the transformer is an AC square waveform. Nominal voltage is 50 Vpeak (100 Vpp). Nominal frequency is 32.7 KHz.
Output voltage designed for 50 VAC maximum as per UL and IEC TS 60479-1.
Unless noted otherwise, all resistors are 0805 SMD, 1%. Capacitors are 0805 SMD.
+50V
-50V
Ring Generator Output Stage
At idle, this signal is low (<0.4V)
High Voltages on this page!
(page 7)

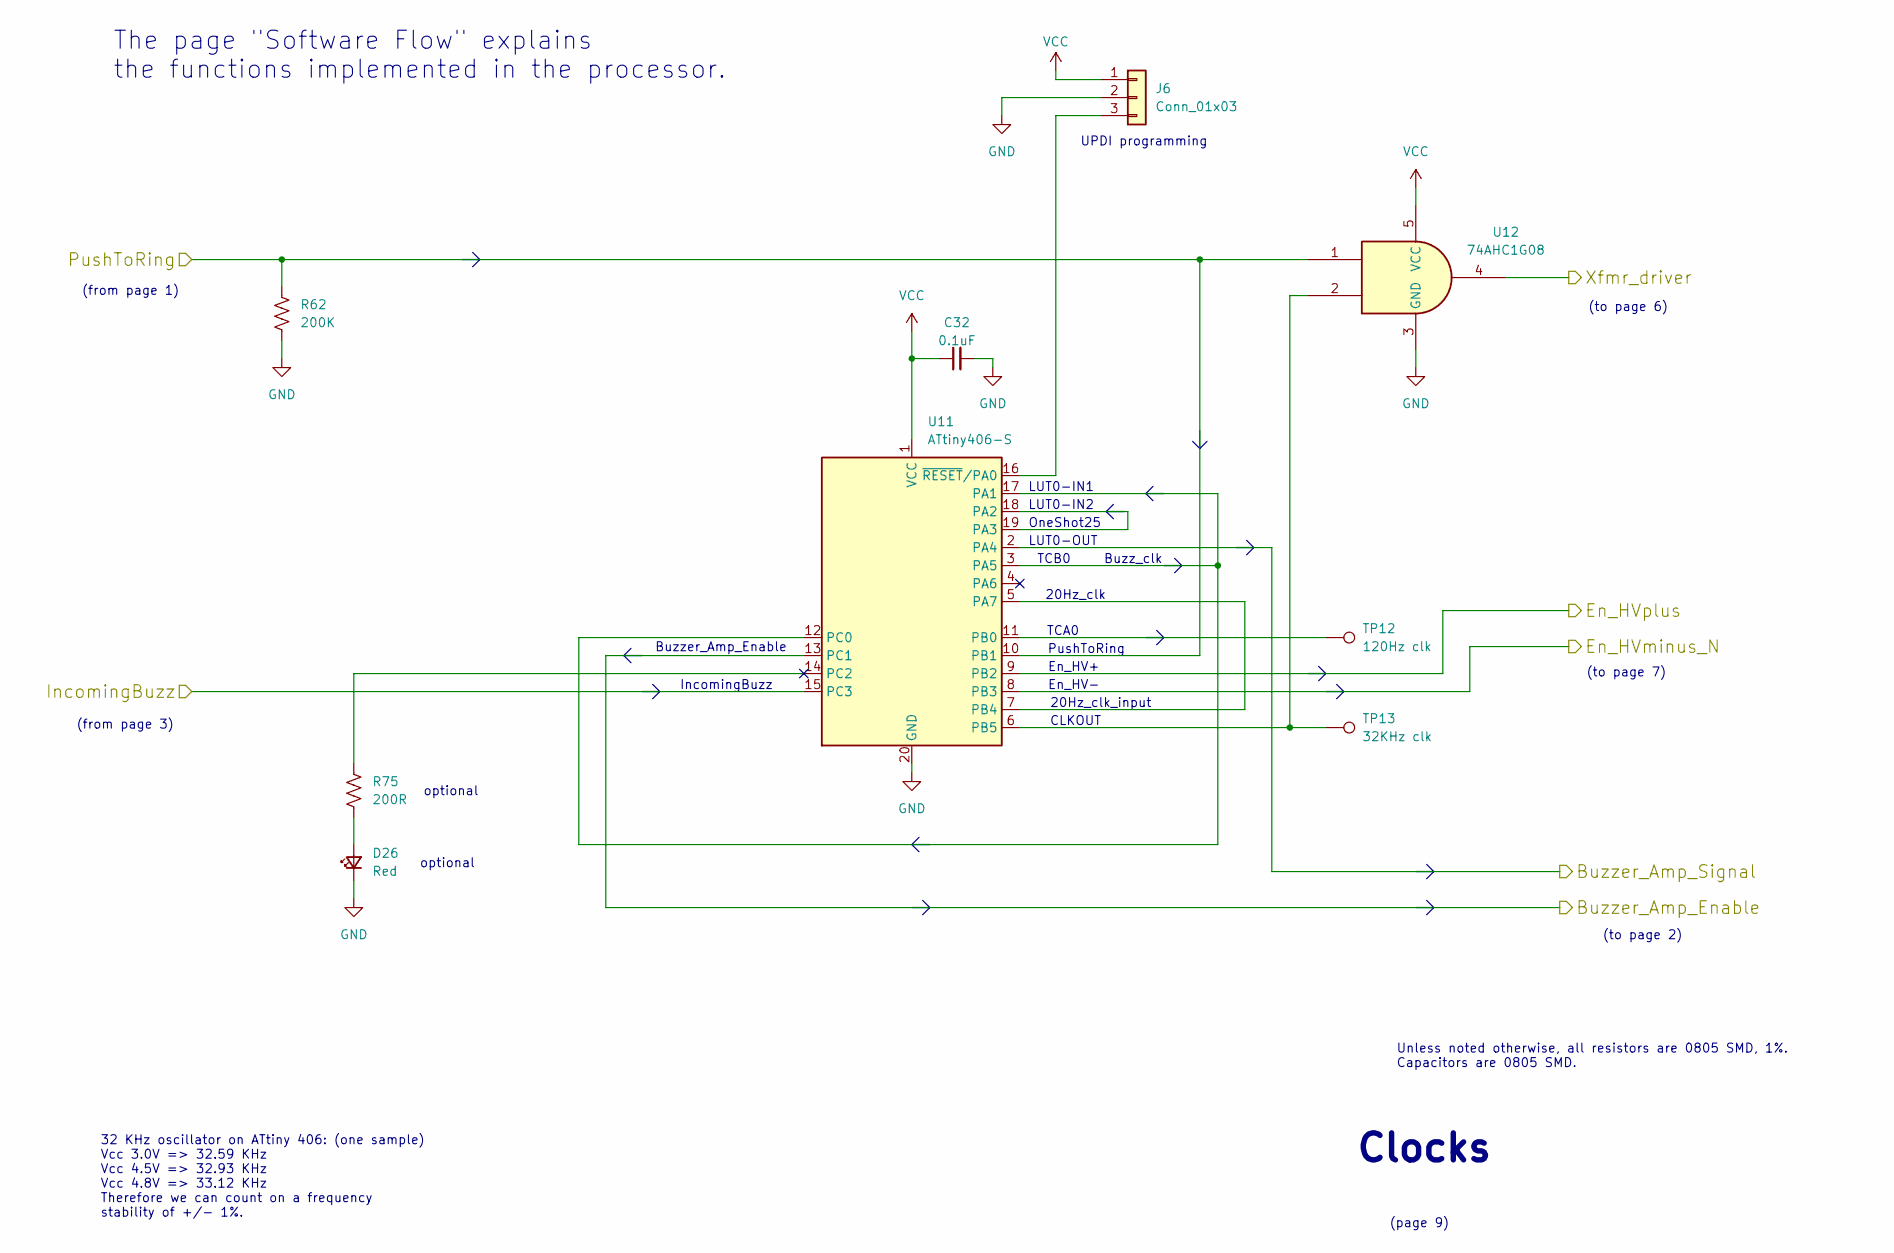
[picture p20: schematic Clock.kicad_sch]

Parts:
C32: 0.1uF; C_0805_2012Metric_Pad1.18x1.45mm_HandSolder
D26: Red; LED_1206_3216Metric_Red
J6: Conn_01x03; PinSocket_1x03_P2.54mm_Vertical
R62: 200K; R_0805_2012Metric_Pad1.20x1.40mm_HandSolder
R75: 200R; R_0805_2012Metric_Pad1.20x1.40mm_HandSolder
TP12: 120Hz clk; Test_point_47mil_scope_probe
TP13: 32KHz clk; Test_point_47mil_scope_probe
U11: ATtiny406-S; SOIC-20W_7.5x12.8mm_P1.27mm
U12: 74AHC1G08; SOT-23-5_HandSoldering

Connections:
/AudioBuzzer/Buzzer_Amp_Enable: U11.13 (PC1); also elsewhere on the board
/AudioBuzzer/Buzzer_Amp_Signal: U11.2 (PA4); also elsewhere on the board
/Clocks/En_HVminus_N: U11.8 (PB3); also elsewhere on the board
/Clocks/En_HVplus: U11.9 (PB2); also elsewhere on the board
/Clocks/IncomingBuzz: U11.15 (PC3); also elsewhere on the board
/Clocks/Xfmr_driver: U12.4; also elsewhere on the board
GND: C32.2, D26.1 (K), J6.2, R62.1, U11.20 (GND), U12.3 (GND); also elsewhere on the board
unnamed: D26.2 (A), R75.1
unnamed: J6.3, U11.16 (~RESET/PA0)
unnamed: U11.3 (PA5), U11.12 (PC0), U11.17 (PA1)
unnamed: U11.18 (PA2), U11.19 (PA3)
unnamed: U11.5 (PA7), U11.7 (PB4)
unnamed: TP12.1, U11.11 (PB0)
unnamed: TP13.1, U11.6 (PB5), U12.2
PushToRing: R62.2, U11.10 (PB1), U12.1; also elsewhere on the board
VCC: C32.1, J6.1, U11.1 (VCC), U12.5 (VCC); also elsewhere on the board

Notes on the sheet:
The page "Software Flow" explains the functions implemented in the processor.
LUT0-OUT
Clocks
Buzzer_Amp_Enable
(from page 1)
TCB0
IncomingBuzz
(page 9)
(to page 6)
LUT0-IN1
UPDI programming
OneShot25
En_HV+
20Hz_clk_input
optional
CLKOUT
(to page 2)
Unless noted otherwise, all resistors are 0805 SMD, 1%. Capacitors are 0805 SMD.
En_HV-
TCA0
LUT0-IN2
20Hz_clk
(from page 3)
PushToRing
32 KHz oscillator on ATtiny 406: (one sample) Vcc 3.0V => 32.59 KHz Vcc 4.5V => 32.93 KHz Vcc 4.8V => 33.12 KHz Therefore we can count on a frequency stability of +/- 1%.
(to page 7)
Buzz_clk

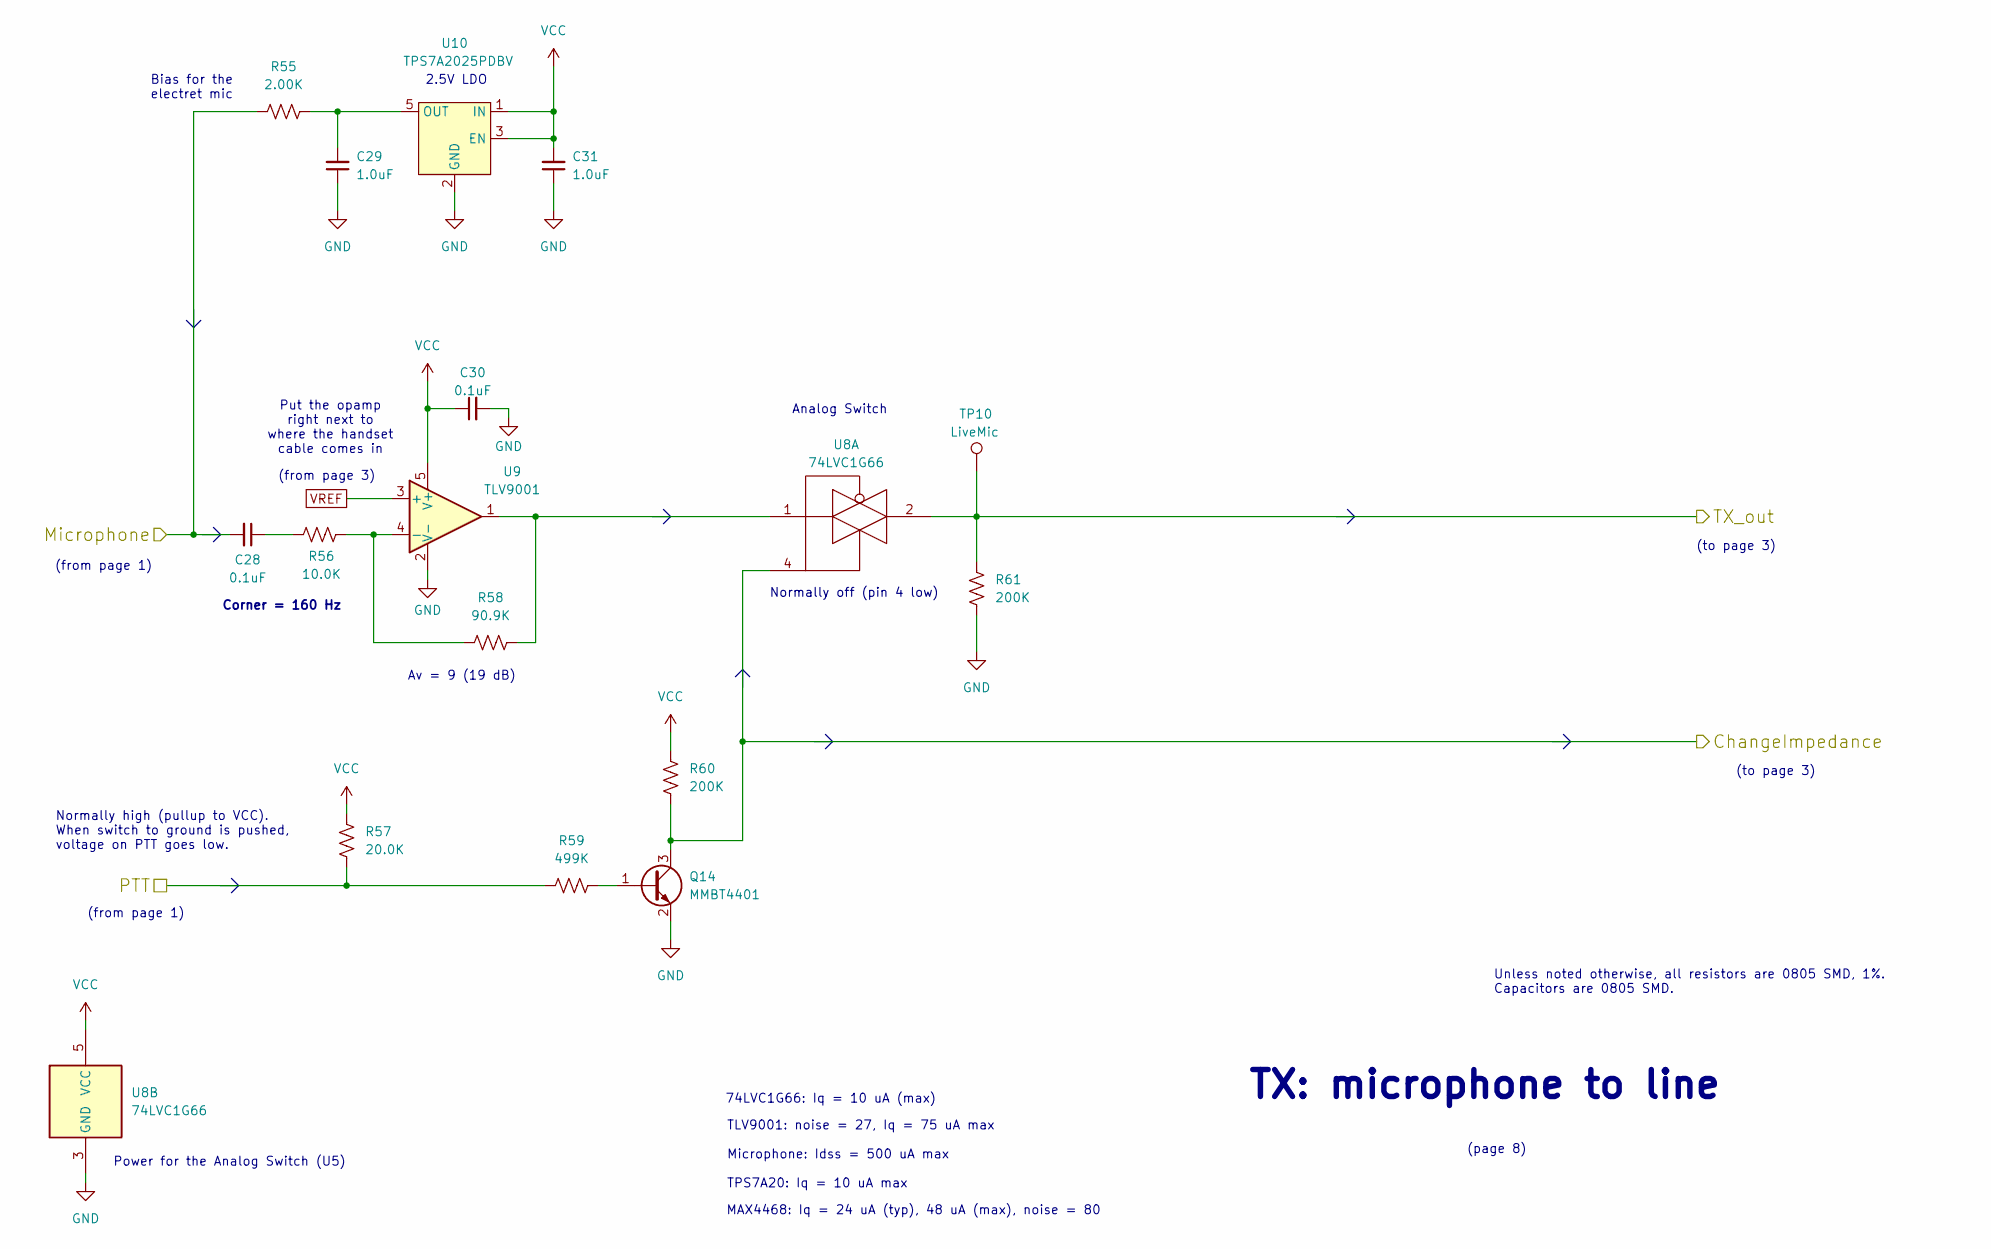
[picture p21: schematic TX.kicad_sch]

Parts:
C28, C30: 0.1uF; C_0805_2012Metric_Pad1.18x1.45mm_HandSolder
C29, C31: 1.0uF; C_0805_2012Metric_Pad1.18x1.45mm_HandSolder
Q14: MMBT4401; SOT-23_Handsoldering
R55: 2.00K; R_0805_2012Metric_Pad1.20x1.40mm_HandSolder
R56: 10.0K; R_0805_2012Metric_Pad1.20x1.40mm_HandSolder
R57: 20.0K; R_0805_2012Metric_Pad1.20x1.40mm_HandSolder
R58: 90.9K; R_0805_2012Metric_Pad1.20x1.40mm_HandSolder
R59: 499K; R_0805_2012Metric_Pad1.20x1.40mm_HandSolder
R60, R61: 200K; R_0805_2012Metric_Pad1.20x1.40mm_HandSolder
TP10: LiveMic; Test_point_47mil_scope_probe
U8: 74LVC1G66; SOT-23-5_HandSoldering
U9: TLV9001; SOT-23-5_HandSoldering
U10: TPS7A2025PDBV; SOT-23-5_HandSoldering

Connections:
/Hybrid/ChangeImpedance: Q14.3 (C), R60.1, U8.4; also elsewhere on the board
/Hybrid/TX_out: R61.1, TP10.1, U8.2; also elsewhere on the board
/Microphone: C28.2, R55.1; also elsewhere on the board
/PTT: R57.2, R59.1; also elsewhere on the board
GND: C29.1, C30.2, C31.1, Q14.2 (E), R61.2, U8.3 (GND), U9.2 (V-), U10.2 (GND); also elsewhere on the board
unnamed: C28.1, R56.1
unnamed: Q14.1 (B), R59.2
unnamed: R58.2, U8.1, U9.1
unnamed: R56.2, R58.1, U9.4 (-)
unnamed: C29.2, R55.2, U10.5 (OUT)
VCC: C30.1, C31.2, R57.1, R60.2, U8.5 (VCC), U9.5 (V+), U10.1 (IN), U10.3 (EN); also elsewhere on the board
VREF: U9.3 (+); also elsewhere on the board

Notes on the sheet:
Corner = 160 Hz
TLV9001: noise = 27, Iq = 75 uA max Microphone: Idss = 500 uA max TPS7A20: Iq = 10 uA max
(page 8)
(from page 1)
2.5V LDO
Av = 9 (19 dB)
Unless noted otherwise, all resistors are 0805 SMD, 1%. Capacitors are 0805 SMD.
Normally off (pin 4 low)
TX: microphone to line
Normally high (pullup to VCC). When switch to ground is pushed, voltage on PTT goes low.
Power for the Analog Switch (U5)
Analog Switch
(to page 3)
74LVC1G66: Iq = 10 uA (max)
(from page 3)
Bias for the electret mic
MAX4468: Iq = 24 uA (typ), 48 uA (max), noise = 80
Put the opamp right next to where the handset cable comes in

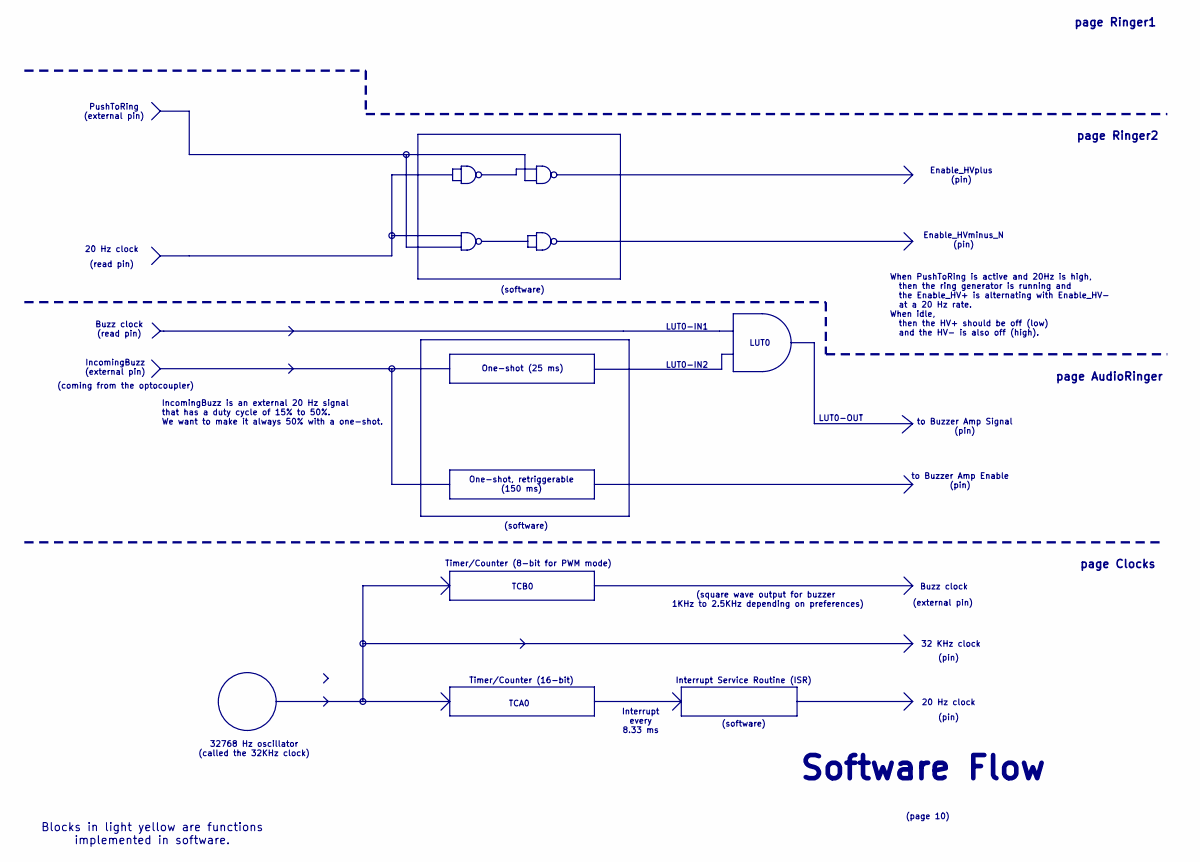
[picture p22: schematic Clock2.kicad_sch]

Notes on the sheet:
20 Hz clock
One-shot, retriggerable (150 ms)
Enable_HVminus_N (pin)
32 KHz clock
to Buzzer Amp Signal (pin)
Interrupt Service Routine (ISR)
Timer/Counter (8-bit for PWM mode)
(external pin)
(page 10)
LUT0-IN2
(pin)
Timer/Counter (16-bit)
Blocks in light yellow are functions implemented in software.
page Clocks
Enable_HVplus (pin)
(square wave output for buzzer 1KHz to 2.5KHz depending on preferences)
(software)
Software Flow
page Ringer1
32768 Hz oscillator (called the 32KHz clock)
LUT0-IN1
IncomingBuzz (external pin)
(read pin)
One-shot (25 ms)
PushToRing (external pin)
page AudioRinger
TCA0
page Ringer2
(coming from the optocoupler)
LUT0
IncomingBuzz is an external 20 Hz signal that has a duty cycle of 15% to 50%. We want to make it always 50% with a one-shot.
TCB0
LUT0-OUT
to Buzzer Amp Enable (pin)
Interrupt every 8.33 ms
Buzz clock (read pin)
When PushToRing is active and 20Hz is high, then the ring generator is running and the Enable_HV+ is alternating with Enable_HV- at a 20 Hz rate. When idle, then the HV+ should be off (low) and the HV- is also off (high).
Buzz clock

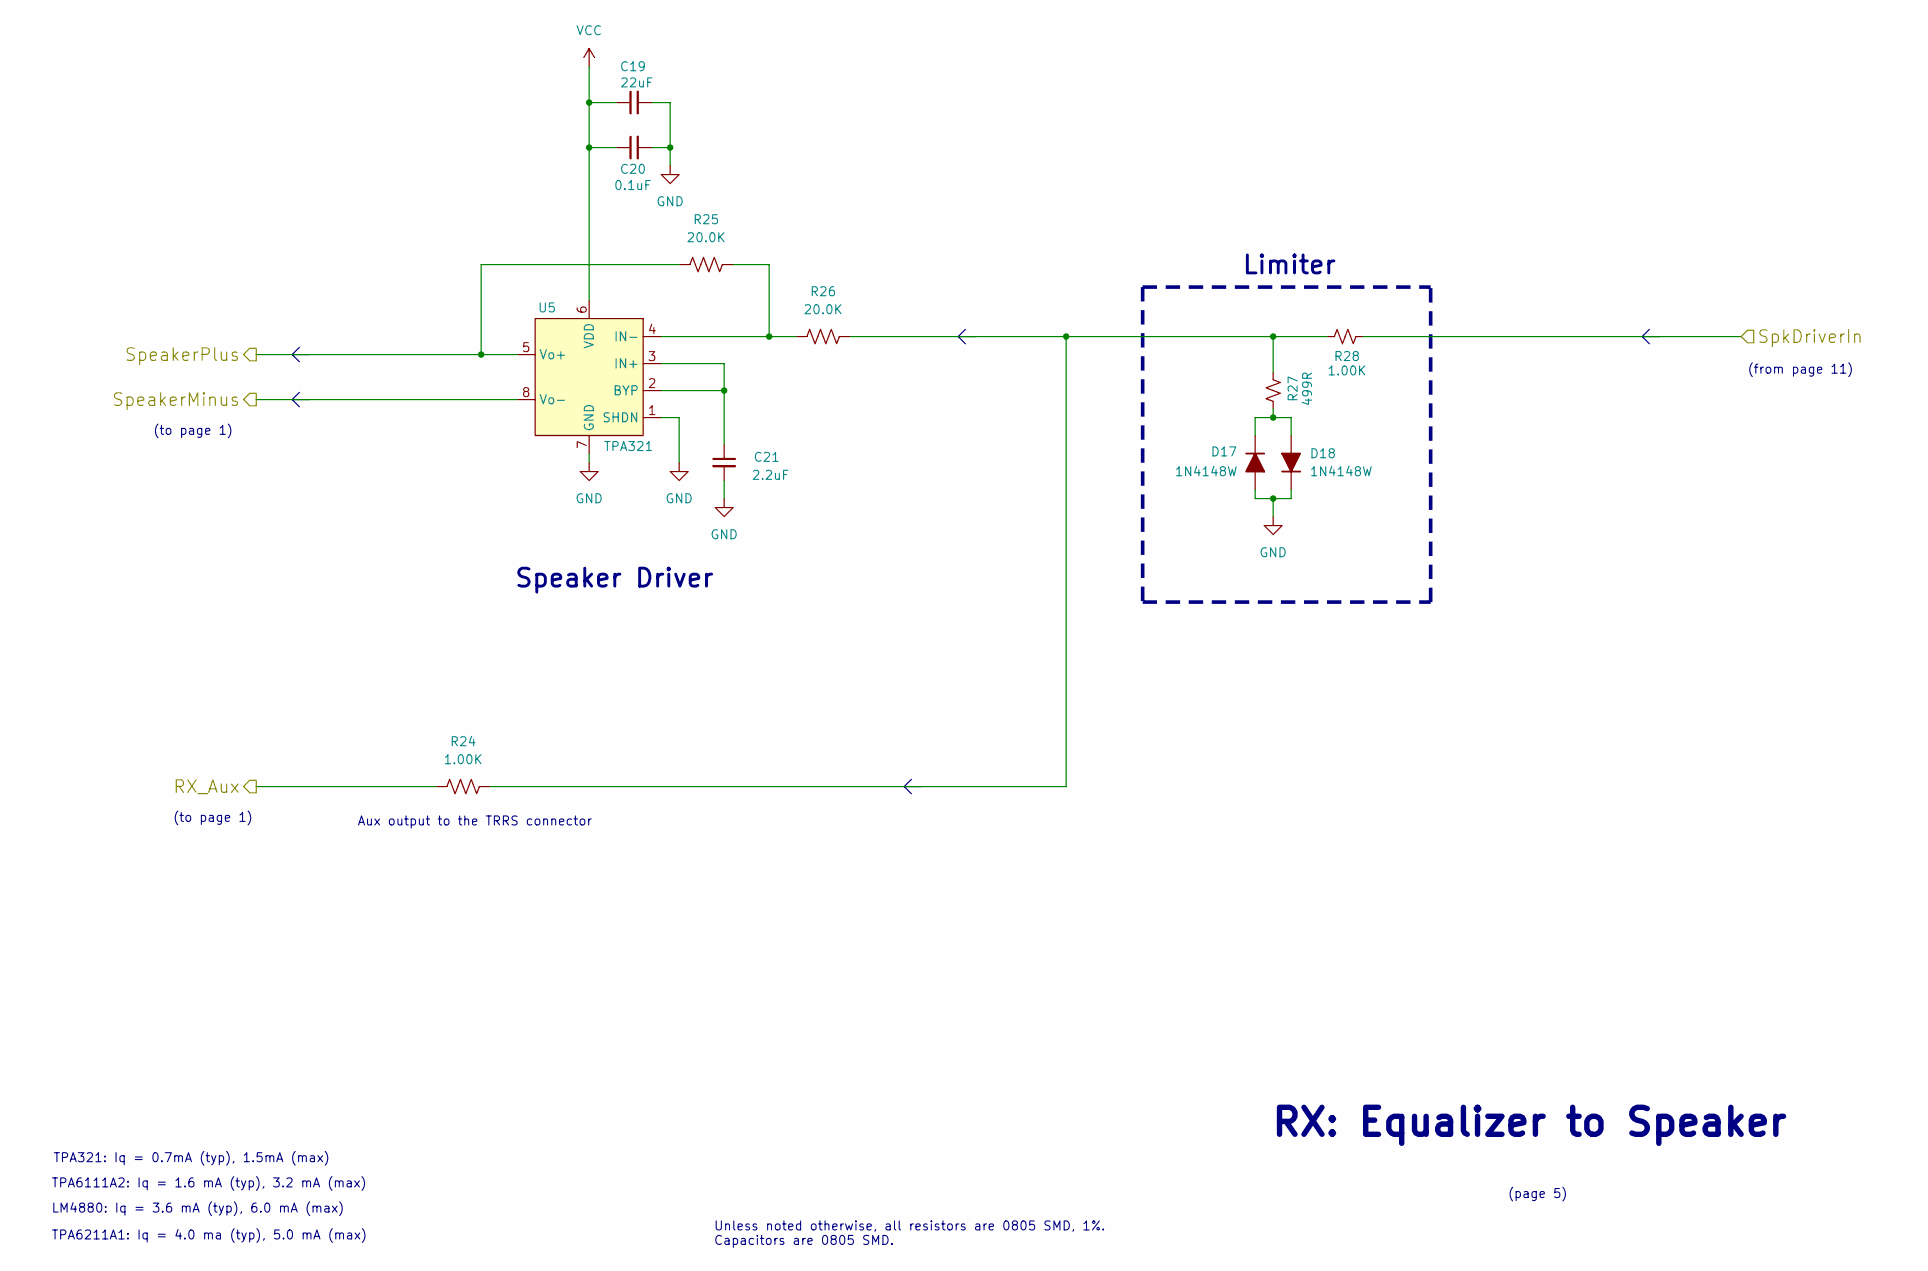
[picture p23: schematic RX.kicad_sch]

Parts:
C19: 22uF; C_0805_2012Metric_Pad1.18x1.45mm_HandSolder
C20: 0.1uF; C_0805_2012Metric_Pad1.18x1.45mm_HandSolder
C21: 2.2uF; C_0805_2012Metric_Pad1.18x1.45mm_HandSolder
D17, D18: 1N4148W; D_SOD-123
R24, R28: 1.00K; R_0805_2012Metric_Pad1.20x1.40mm_HandSolder
R25, R26: 20.0K; R_0805_2012Metric_Pad1.20x1.40mm_HandSolder
R27: 499R; R_0805_2012Metric_Pad1.20x1.40mm_HandSolder
U5: TPA321; SOIC-8_3.9x4.9mm_P1.27mm

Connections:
/Equalizer/EqualOut: R28.2; also elsewhere on the board
/RX/RX_Aux: R24.2; also elsewhere on the board
/SpeakerMinus: U5.8 (Vo-); also elsewhere on the board
/SpeakerPlus: R25.2, U5.5 (Vo+); also elsewhere on the board
GND: C19.2, C20.2, C21.2, D17.2 (A), D18.1 (K), U5.1 (SHDN), U5.7 (GND); also elsewhere on the board
unnamed: D17.1 (K), D18.2 (A), R27.1
unnamed: R24.1, R26.1, R27.2, R28.1
unnamed: C21.1, U5.2 (BYP), U5.3 (IN+)
unnamed: R25.1, R26.2, U5.4 (IN-)
VCC: C19.1, C20.1, U5.6 (VDD); also elsewhere on the board

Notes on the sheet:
RX: Equalizer to Speaker
(to page 1)
(from page 11)
Aux output to the TRRS connector
LM4880: Iq = 3.6 mA (typ), 6.0 mA (max)
Speaker Driver
TPA6211A1: Iq = 4.0 ma (typ), 5.0 mA (max)
TPA321: Iq = 0.7mA (typ), 1.5mA (max)
Unless noted otherwise, all resistors are 0805 SMD, 1%. Capacitors are 0805 SMD.
TPA6111A2: Iq = 1.6 mA (typ), 3.2 mA (max)
Limiter
(page 5)

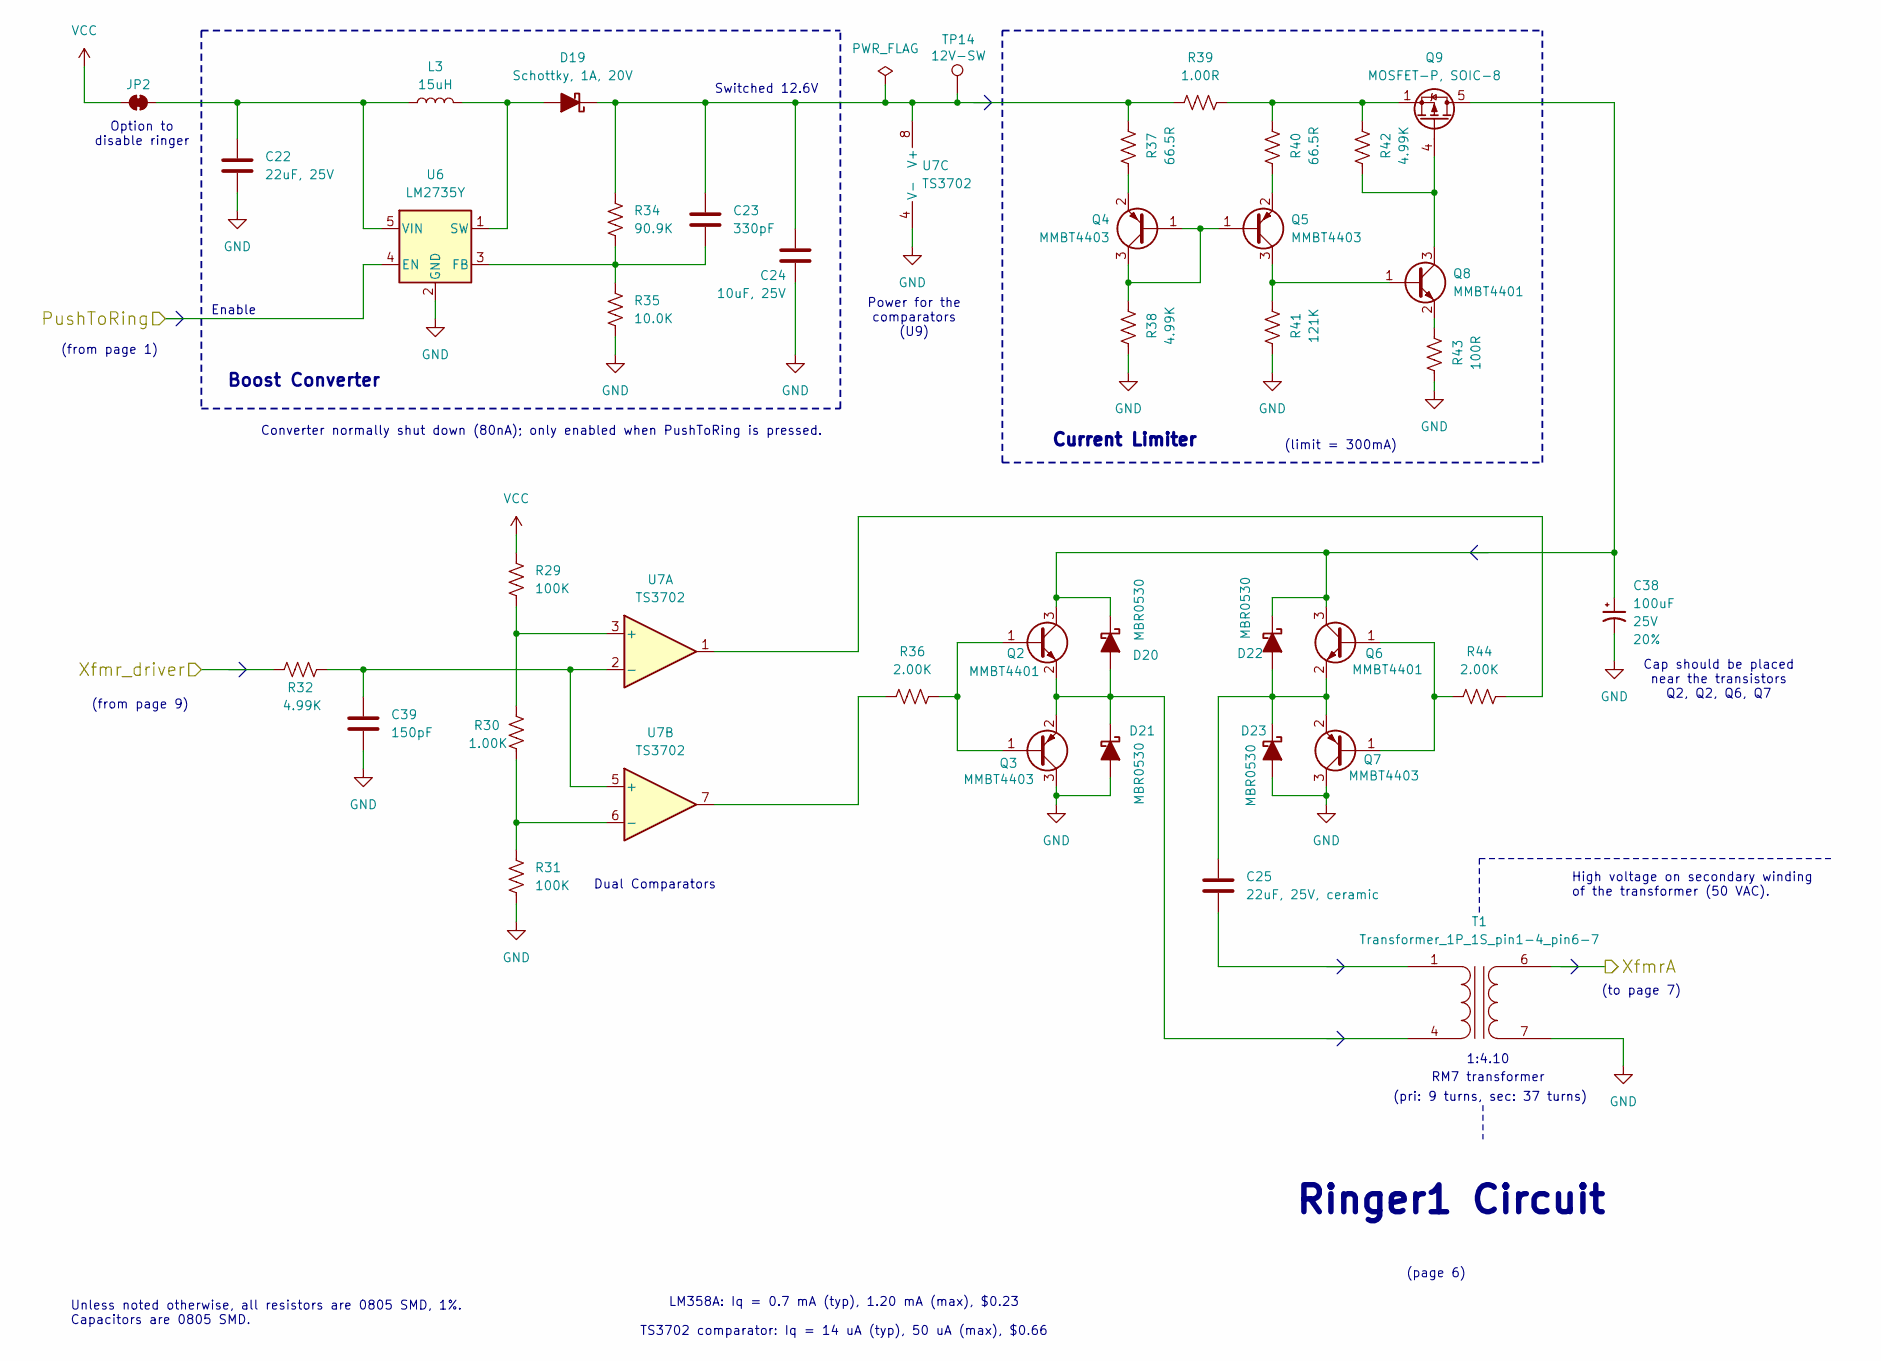
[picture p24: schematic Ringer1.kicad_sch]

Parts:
C22: 22uF, 25V; C_0805_2012Metric_Pad1.18x1.45mm_HandSolder
C23: 330pF; C_0805_2012Metric_Pad1.18x1.45mm_HandSolder
C24: 10uF, 25V; C_0805_2012Metric_Pad1.18x1.45mm_HandSolder
C25: 22uF, 25V, ceramic; C_0805_2012Metric_Pad1.18x1.45mm_HandSolder
C38: 100uF; Panasonic_D; Voltage 25V; Tolerance 20%
C39: 150pF; C_0805_2012Metric_Pad1.18x1.45mm_HandSolder
D19: Schottky, 1A, 20V; D_SOD-123
D20, D21, D22, D23: MBR0530; D_SOD-123
JP2: Jumper_2_NC_Trace
L3: 15uH; L_5x5mm_or_6.3x6.0
Q2, Q6, Q8: MMBT4401; SOT-23_Handsoldering
Q3, Q4, Q5, Q7: MMBT4403; SOT-23_Handsoldering
Q9: MOSFET-P, SOIC-8; SOIC-8_3.9x4.9mm_P1.27mm
R29, R31: 100K; R_0805_2012Metric_Pad1.20x1.40mm_HandSolder
R30: 1.00K; R_0805_2012Metric_Pad1.20x1.40mm_HandSolder
R32, R38, R42: 4.99K; R_0805_2012Metric_Pad1.20x1.40mm_HandSolder
R34: 90.9K; R_0805_2012Metric_Pad1.20x1.40mm_HandSolder
R35: 10.0K; R_0805_2012Metric_Pad1.20x1.40mm_HandSolder
R36, R44: 2.00K; R_0805_2012Metric_Pad1.20x1.40mm_HandSolder
R37, R40: 66.5R; R_0805_2012Metric_Pad1.20x1.40mm_HandSolder
R39: 1.00R; R_0805_2012Metric_Pad1.20x1.40mm_HandSolder
R41: 121K; R_0805_2012Metric_Pad1.20x1.40mm_HandSolder
R43: 100R; R_0805_2012Metric_Pad1.20x1.40mm_HandSolder
T1: Transformer_1P_1S_pin1-4_pin6-7; Transformer_RM7_8-pin
TP14: 12V-SW; Test_point_47mil_scope_probe
U6: LM2735Y; SOT-23-5
U7: TS3702; SOIC-8_3.9x4.9mm_P1.27mm

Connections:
/Clocks/Xfmr_driver: R32.2; also elsewhere on the board
/Ringer1/XfmrA: T1.6 (SB); also elsewhere on the board
GND: C22.2, C24.2, C38.2, C39.2, D21.2 (A), D23.2 (A), Q3.3 (C), Q7.3 (C), R31.1, R35.1, R38.2, R41.2, R43.2, T1.7 (SA), U6.2 (GND), U7.4 (V-); also elsewhere on the board
unnamed: D19.2 (A), L3.2, U6.1 (SW)
unnamed: C23.1, C24.1, D19.1 (K), R34.2, R37.1, R39.2, TP14.1, U7.8 (V+)
unnamed: D20.2 (A), D21.1 (K), Q2.2 (E), Q3.2 (E), T1.4 (AB)
unnamed: C38.1, D20.1 (K), D22.1 (K), Q2.3 (C), Q6.3 (C), Q9.5 (D), Q9.6 (D), Q9.7 (D), Q9.8 (D)
unnamed: C25.1, D22.2 (A), D23.1 (K), Q6.2 (E), Q7.2 (E)
unnamed: C22.1, JP2.2 (B), L3.1, U6.5 (VIN)
unnamed: Q2.1 (B), Q3.1 (B), R36.1
unnamed: Q4.1 (B), Q4.3 (C), Q5.1 (B), R38.1
unnamed: Q4.2 (E), R37.2
unnamed: Q5.3 (C), Q8.1 (B), R41.1
unnamed: Q5.2 (E), R40.2
unnamed: Q6.1 (B), Q7.1 (B), R44.2
unnamed: Q8.3 (C), Q9.4 (G), R42.2
unnamed: Q8.2 (E), R43.1
unnamed: Q9.1 (S), Q9.2 (S), Q9.3 (S), R39.1, R40.1, R42.1
unnamed: R36.2, U7.7
unnamed: R44.1, U7.1
unnamed: C25.2, T1.1 (AA)
unnamed: C23.2, R34.1, R35.2, U6.3 (FB)
unnamed: R29.1, R30.2, U7.3 (+)
unnamed: C39.1, R32.1, U7.2 (-), U7.5 (+)
unnamed: R30.1, R31.2, U7.6 (-)
PushToRing: U6.4 (EN); also elsewhere on the board
VCC: JP2.1 (A), R29.2; also elsewhere on the board

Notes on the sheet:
Dual Comparators
Enable
(from page 9)
Ringer1 Circuit
RM7 transformer
Converter normally shut down (80nA); only enabled when PushToRing is pressed.
1:4.10
Boost Converter
(pri: 9 turns, sec: 37 turns)
High voltage on secondary winding of the transformer (50 VAC).
Option to disable ringer
Power for the comparators (U9)
Current Limiter
(to page 7)
Unless noted otherwise, all resistors are 0805 SMD, 1%. Capacitors are 0805 SMD.
LM358A: Iq = 0.7 mA (typ), 1.20 mA (max), $0.23 TS3702 comparator: Iq = 14 uA (typ), 50 uA (max), $0.66
(limit = 300mA)
Cap should be placed near the transistors Q2, Q2, Q6, Q7
(page 6)
(from page 1)
Switched 12.6V

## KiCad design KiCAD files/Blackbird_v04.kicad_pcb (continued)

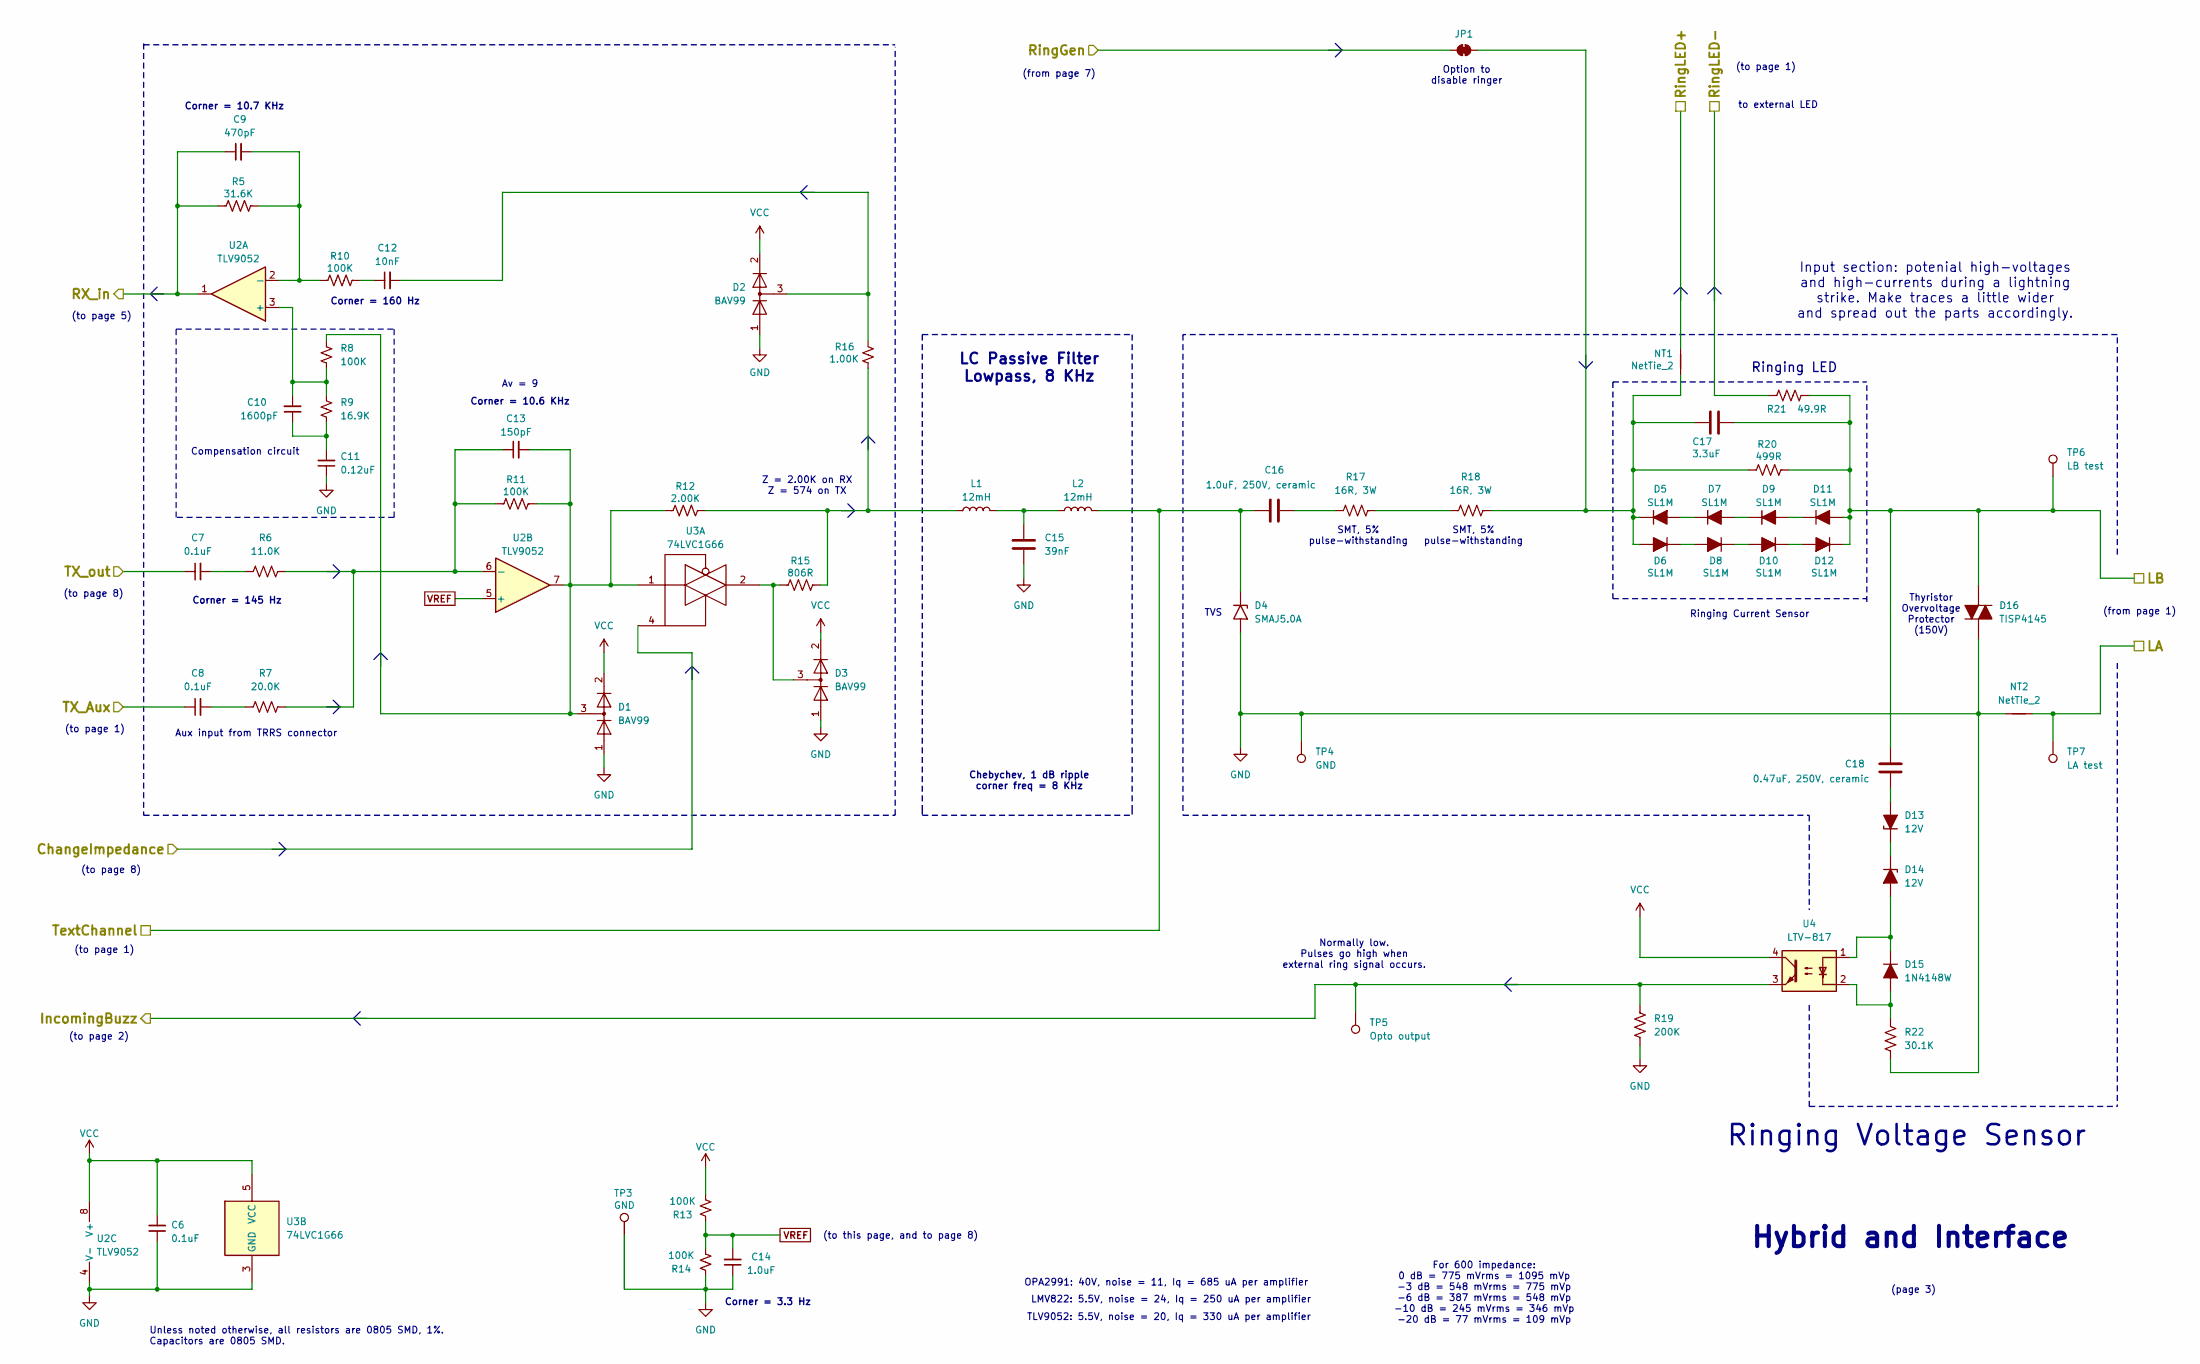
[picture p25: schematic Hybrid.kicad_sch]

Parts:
C6, C7, C8: 0.1uF; C_0805_2012Metric_Pad1.18x1.45mm_HandSolder
C9: 470pF; C_0805_2012Metric_Pad1.18x1.45mm_HandSolder
C10: 1600pF; C_0805_2012Metric_Pad1.18x1.45mm_HandSolder
C11: 0.12uF; C_0805_2012Metric_Pad1.18x1.45mm_HandSolder
C12: 10nF; C_0805_2012Metric_Pad1.18x1.45mm_HandSolder
C13: 150pF; C_0805_2012Metric_Pad1.18x1.45mm_HandSolder
C14: 1.0uF; C_0805_2012Metric_Pad1.18x1.45mm_HandSolder
C15: 39nF; C_0805_2012Metric_Pad1.18x1.45mm_HandSolder
C16: 1.0uF, 250V, ceramic; C_1825_4564Metric_Pad1.57x6.80mm_HandSolder
C17: 3.3uF; C_0805_2012Metric_Pad1.18x1.45mm_HandSolder
C18: 0.47uF, 250V, ceramic; C_1812_4532Metric_Pad1.57x3.40mm_HandSolder
D1, D2, D3: BAV99; SOT-23
D4: SMAJ5.0A; D_SMA
D5, D6, D7, D8, D9, D10, D11, D12: SL1M; D_SOD-123F
D13, D14: 12V; D_SOD-123
D15: 1N4148W; D_SOD-123
D16: TISP4145; D_SMB_Handsoldering
JP1: Jumper_2_NC_Trace
L1, L2: 12mH; L_Radial_D8.7mm_P5.00mm_Fastron_07HCP
NT1, NT2: NetTie_2; NetTie-2_SMD_Pad0.5mm
R5: 31.6K; R_0805_2012Metric_Pad1.20x1.40mm_HandSolder
R6: 11.0K; R_0805_2012Metric_Pad1.20x1.40mm_HandSolder
R7: 20.0K; R_0805_2012Metric_Pad1.20x1.40mm_HandSolder
R8, R10, R11, R13, R14: 100K; R_0805_2012Metric_Pad1.20x1.40mm_HandSolder
R9: 16.9K; R_0805_2012Metric_Pad1.20x1.40mm_HandSolder
R12: 2.00K; R_0805_2012Metric_Pad1.20x1.40mm_HandSolder
R15: 806R; R_0805_2012Metric_Pad1.20x1.40mm_HandSolder
R16: 1.00K; R_0805_2012Metric_Pad1.20x1.40mm_HandSolder
R17, R18: 16R, 3W; R_2512_6332Metric_wide
R19: 200K; R_0805_2012Metric_Pad1.20x1.40mm_HandSolder
R20: 499R; R_0805_2012Metric_Pad1.20x1.40mm_HandSolder
R21: 49.9R; R_0805_2012Metric_Pad1.20x1.40mm_HandSolder
R22: 30.1K; R_0805_2012Metric_Pad1.20x1.40mm_HandSolder
TP3, TP4: GND; Test_point_47mil_scope_probe
TP5: Opto output; Test_point_47mil_scope_probe
TP6: LB test; Test_point_47mil_scope_probe
TP7: LA test; Test_point_47mil_scope_probe
U2: TLV9052; SOIC-8_3.9x4.9mm_P1.27mm
U3: 74LVC1G66; SOT-23-5_HandSoldering
U4: LTV-817; Opto_LTV-817S

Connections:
/Clocks/IncomingBuzz: R19.1, TP5.1, U4.3; also elsewhere on the board
/Equalizer/RX_in: C9.1, R5.1, U2.1; also elsewhere on the board
/Hybrid/ChangeImpedance: U3.4; also elsewhere on the board
/Hybrid/LA: NT2.2, TP7.1; also elsewhere on the board
/Hybrid/LB: C17.2, C18.1, D11.2 (A), D12.1 (K), D16.1, R20.2, R21.2, TP6.1; also elsewhere on the board
/Hybrid/RingGen: JP1.1 (A); also elsewhere on the board
/Hybrid/RingLED+: NT1.2; also elsewhere on the board
/Hybrid/RingLED-: R21.1; also elsewhere on the board
/Hybrid/TX_Aux: C8.1; also elsewhere on the board
/Hybrid/TX_out: C7.1; also elsewhere on the board
/Hybrid/TextChannel: C16.1, D4.1 (A1), L2.2; also elsewhere on the board
GND: C6.1, C11.1, C14.1, C15.2, D1.1 (K), D2.1 (K), D3.1 (K), D4.2 (A2), D16.2, NT2.1, R14.1, R19.2, R22.2, TP3.1, TP4.1, U2.4 (V-), U3.3 (GND); also elsewhere on the board
unnamed: C7.2, R6.1
unnamed: C8.2, R7.1
unnamed: C10.1, C11.2, R9.1
unnamed: C12.1, R10.2
unnamed: C12.2, D2.3 (K), R16.2
unnamed: C13.2, D1.3 (K), R8.2, R11.2, R12.1, U2.7, U3.1
unnamed: C15.1, L1.2, L2.1
unnamed: C16.2, R17.1
unnamed: D3.3 (K), R15.1, U3.2
unnamed: D5.2 (A), D7.1 (K)
unnamed: C17.1, D5.1 (K), D6.2 (A), JP1.2 (B), NT1.1, R18.2, R20.1
unnamed: D6.1 (K), D8.2 (A)
unnamed: D7.2 (A), D9.1 (K)
unnamed: D8.1 (K), D10.2 (A)
unnamed: D10.1 (K), D12.2 (A)
unnamed: D9.2 (A), D11.1 (K)
unnamed: C18.2, D13.2 (A)
unnamed: D13.1 (K), D14.1 (K)
unnamed: D14.2 (A), D15.1 (K), U4.1
unnamed: D15.2 (A), R22.1, U4.2
unnamed: L1.1, R12.2, R15.2, R16.1
unnamed: R17.2, R18.1
unnamed: C10.2, R8.1, R9.2, U2.3 (+)
unnamed: C9.2, R5.2, R10.1, U2.2 (-)
unnamed: C13.1, R6.2, R7.2, R11.1, U2.6 (-)
VCC: C6.2, D1.2 (A), D2.2 (A), D3.2 (A), R13.2, U2.8 (V+), U3.5 (VCC), U4.4; also elsewhere on the board
VREF: C14.2, R13.1, R14.2, U2.5 (+); also elsewhere on the board

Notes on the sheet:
(to page 1)
For 600 impedance: 0 dB = 775 mVrms = 1095 mVp -3 dB = 548 mVrms = 775 mVp -6 dB = 387 mVrms = 548 mVp -10 dB = 245 mVrms = 346 mVp -20 dB = 77 mVrms = 109 mVp
SMT, 5% pulse-withstanding
(to this page, and to page 8)
TLV9052: 5.5V, noise = 20, Iq = 330 uA per amplifier
(to page 8)
Option to disable ringer
Z = 2.00K on RX Z = 574 on TX
Compensation circuit
Input section: potenial high-voltages and high-currents during a lightning strike. Make traces a little wider and spread out the parts accordingly.
(to page 2)
LMV822: 5.5V, noise = 24, Iq = 250 uA per amplifier
(page 3)
(from page 1)
Unless noted otherwise, all resistors are 0805 SMD, 1%. Capacitors are 0805 SMD.
(from page 7)
Chebychev, 1 dB ripple corner freq = 8 KHz
Aux input from TRRS connector
Ringing Voltage Sensor
(to page 5)
Thyristor Overvoltage Protector (150V)
Corner = 10.7 KHz
to external LED
Corner = 160 Hz
TVS
Av = 9
LC Passive Filter Lowpass, 8 KHz
Corner = 145 Hz
Hybrid and Interface
Normally low. Pulses go high when external ring signal occurs.
OPA2991: 40V, noise = 11, Iq = 685 uA per amplifier
Ringing Current Sensor
Corner = 10.6 KHz
Corner = 3.3 Hz
Ringing LED

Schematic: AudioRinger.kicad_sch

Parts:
C1, C2, C5: 0.1uF; C_0805_2012Metric_Pad1.18x1.45mm_HandSolder
C3: 2.2uF; C_0805_2012Metric_Pad1.18x1.45mm_HandSolder
C4: 22uF; C_0805_2012Metric_Pad1.18x1.45mm_HandSolder
R2, R4: 20.0K; R_0805_2012Metric_Pad1.20x1.40mm_HandSolder
R3: 10.0K; R_0805_2012Metric_Pad1.20x1.40mm_HandSolder
U1: TPA321; SOIC-8_3.9x4.9mm_P1.27mm

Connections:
/AudioBuzzer/Buzz-A: R4.1, U1.5 (Vo+); also elsewhere on the board
/AudioBuzzer/Buzz-B: U1.8 (Vo-); also elsewhere on the board
/AudioBuzzer/Buzzer_Amp_Enable: U1.1 (SHDN); also elsewhere on the board
/AudioBuzzer/Buzzer_Amp_Signal: C2.1; also elsewhere on the board
/AudioBuzzer/ToneInjection: C1.1; also elsewhere on the board
GND: C3.2, C4.2, C5.2, U1.7 (GND); also elsewhere on the board
unnamed: C1.2, R2.2
unnamed: C2.2, R3.2
unnamed: C3.1, U1.2 (BYP), U1.3 (IN+)
unnamed: R2.1, R3.1, R4.2, U1.4 (IN-)
VCC: C4.1, C5.1, U1.6 (VDD); also elsewhere on the board

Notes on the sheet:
Shutdown is enabled most of the time. When a pulse comes by, then the tone is enabled for a short time.
Audio Ringer
(to page 1)
(page 2)
Unless noted otherwise, all resistors are 0805 SMD, 1%. Capacitors are 0805 SMD.
Audio Amplifier
(from page 1)
(from page 9)
To Buzzer
This port gives us the option to add a sound at the buzzer speaker from text messages or some other auxiliary function.

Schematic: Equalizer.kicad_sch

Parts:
C33: 39nF; C_0805_2012Metric_Pad1.18x1.45mm_HandSolder
C34: 560pF; C_0805_2012Metric_Pad1.18x1.45mm_HandSolder
C35: 0.1uF; C_0805_2012Metric_Pad1.18x1.45mm_HandSolder
C36: 390nF; C_0805_2012Metric_Pad1.18x1.45mm_HandSolder
C37: 5.6nF; C_0805_2012Metric_Pad1.18x1.45mm_HandSolder
R63, R69: 332R; R_0805_2012Metric_Pad1.20x1.40mm_HandSolder
R64, R70: 845R; R_0805_2012Metric_Pad1.20x1.40mm_HandSolder
R65, R71: 143K; R_0805_2012Metric_Pad1.20x1.40mm_HandSolder
R66, R72: 9.09K; R_0805_2012Metric_Pad1.20x1.40mm_HandSolder
R67, R73: 464R; R_0805_2012Metric_Pad1.20x1.40mm_HandSolder
R68, R74: 5.60K; R_0805_2012Metric_Pad1.20x1.40mm_HandSolder
U13: TLV9001; SOT-23-5_HandSoldering
U14: TLV9002; SOIC-8_3.9x4.9mm_P1.27mm

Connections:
/Equalizer/EqualOut: R68.2, U14.1; also elsewhere on the board
/Equalizer/RX_in: R74.1; also elsewhere on the board
GND: C35.1, U13.2 (V-), U14.4 (V-); also elsewhere on the board
unnamed: C33.1, R64.1
unnamed: C33.2, R63.1, R66.2
unnamed: C34.2, R64.2, R67.1
unnamed: C36.1, R70.1
unnamed: C36.2, R69.1, R72.2
unnamed: C37.2, R70.2, R73.1
unnamed: C34.1, R65.1, U13.3 (+)
unnamed: R67.2, U13.1, U13.4 (-)
unnamed: R66.1, R72.1, R74.2, U14.3 (+)
unnamed: R63.2, R68.1, R69.2, U14.2 (-)
unnamed: C37.1, R71.1, U14.5 (+)
unnamed: R73.2, U14.6 (-), U14.7
VCC: C35.2, U13.5 (V+), U14.8 (V+); also elsewhere on the board
VREF: R65.2, R71.2; also elsewhere on the board

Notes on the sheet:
RX Equalizer
Need to adjust values for 5 KHz
(to page 5)
Resonance
(page 11)
Center Freq
5 KHz Equalizer
(half Vcc)
400 Hz Equalizer
(from page 3)
TLV9001: 5.5V, noise = 27, Iq = 77 uA (max) TLV9002: 5.5V, noise = 27, Iq = 75 uA (max) per amplifier
This page is an graphic equalizer, except it only controls two bands and the gain and Q are fixed. For more info: An audio circuit collection, Part 3 Texas Instruments https://www.ti.com/lit/pdf/slyt134 Simple, Easy Parametric and Graphic EQ's, Plus Peaks and Notches http://www.geofex.com/article_f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
Unless noted otherwise, all resistors are 0805 SMD, 1%. Capacitors are 0805 SMD.
Sets Q

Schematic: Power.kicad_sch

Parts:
NT3: NetTie_2; NetTie-2_SMD_Pad0.5mm
Q1: NMOS; SOT-23_Handsoldering
R23: 499K; R_0805_2012Metric_Pad1.20x1.40mm_HandSolder

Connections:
/Power/Battery+: NT3.1; also elsewhere on the board
/Power/Battery-: Q1.3 (D); also elsewhere on the board
GND: Q1.2 (S), R23.1; also elsewhere on the board
VCC: NT3.2, Q1.1 (G), R23.2; also elsewhere on the board

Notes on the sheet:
Power can come from three AA batteries or one Li-on 18650 cell. * Three alkaline AA batteries have a nominal voltage of 4.5V (max 4.8V). * Three lithium AA batteries (primary, not rechargeable) have a new voltage of 5.4V * 18650 cell has nominal voltage of 4.2 fully charged, 3.7V nominal. * All cel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
(to all pages)
(from page 1)
(page 4)
Reverse-battery protection
Unless noted otherwise, all resistors are 0805 SMD, 1%. Capacitors are 0805 SMD.
Voltage = (3.0V, 4.5V, 5.5V)
Power

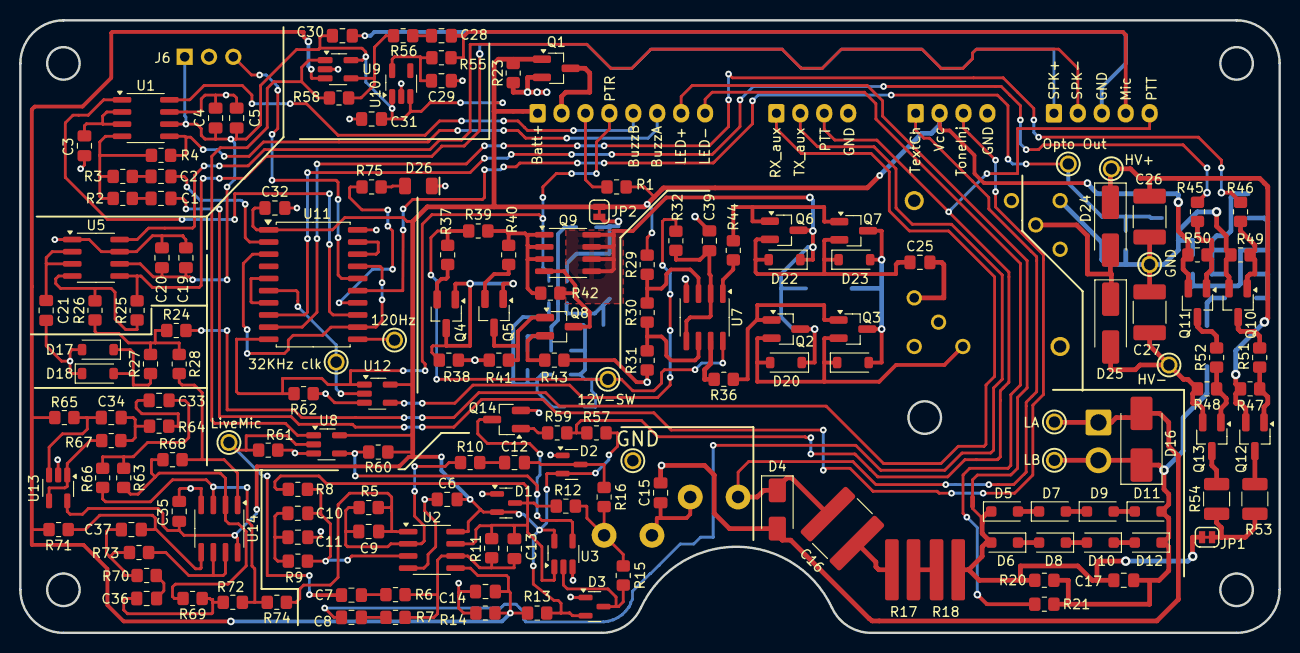
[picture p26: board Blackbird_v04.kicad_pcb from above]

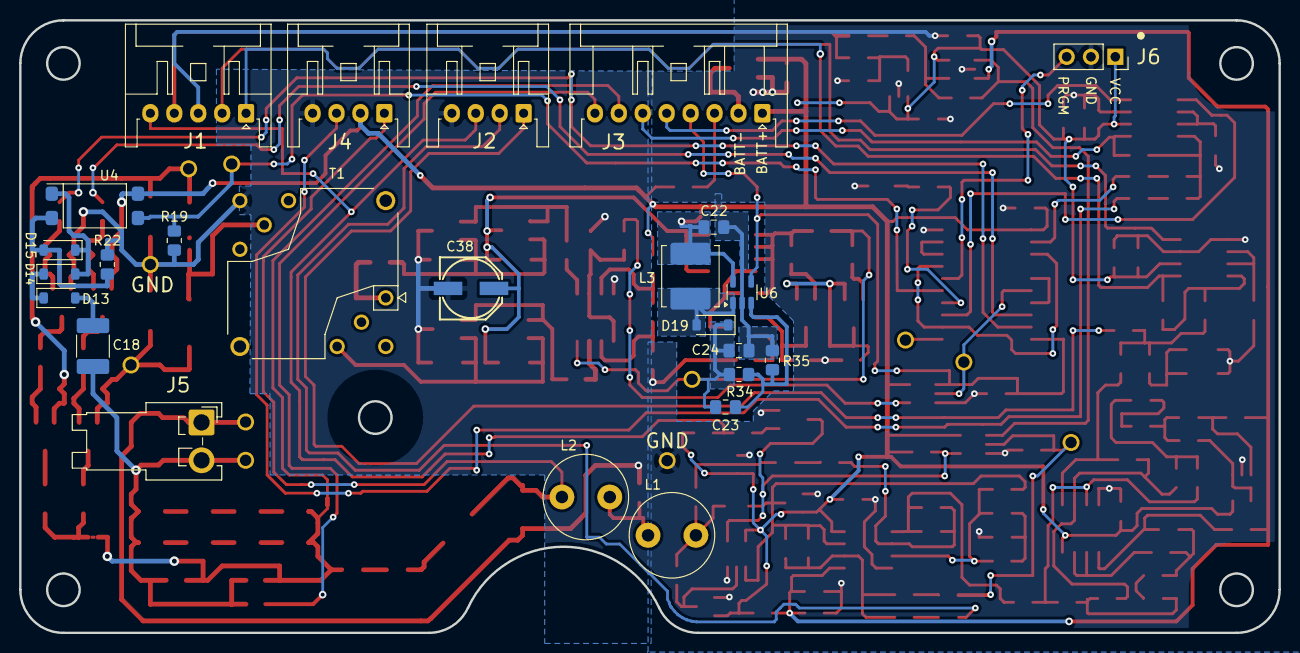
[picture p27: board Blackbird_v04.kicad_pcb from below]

Board: 2 copper layers, 131.6 x 64.0 mm, 193 parts (25 on the bottom side), 122 nets.

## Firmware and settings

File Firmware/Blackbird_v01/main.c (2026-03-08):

/*
 * main.c
 *
 * Created: 29-Sep-2025
 * Updated: 9-Nov-2025
 * Author : Steve Reames
 * Released to Creative Commons
 */ 

/* Pinout
	PA0 = UDPI programming pin (in/out)
	PA1 = <unused>
	PA2 = <unused>
	PA3 = <unused>
	PA4 = <unused>
	PA5 = TCB0, WO, Buzz_clk (output)
	PA6 = <unused>
	PA7 = <unused>
	
	PB0 = TCA0, WO0, 20Hz_clk (output)
	PB1 = PushToRing (input)
	PB2 = EnHVpositive (output)
	PB3 - EnHVnegative (output)
	PB4 = 20Hz_clk (input)
	PB5 = CLKOUT (output)
	
	PC0 = Buzz_clk (input)
	PC1 = EnBuzzerAmp (output)
	PC2 = BuzzerAmpInput (output)
	PC3 = IncomingBuzz (input)
*/

#include "Blackbird.h"


/*****************************************************************************/
/*                            Hardware Fuses                                 */
/*****************************************************************************/
//
FUSES = {
	.WDTCFG = PERIOD_OFF_gc || WINDOW_OFF_gc,  /* Watchdog Configuration - off */
	.BODCFG = ACTIVE_DIS_gc,  /* BOD Configuration - BOD disabled */
	.OSCCFG = FREQSEL_16MHZ_gc,  /* Oscillator Configuration */
	//	.reserved_1[2];
	.SYSCFG0 = CRCSRC_NOCRC_gc || RSTPINCFG_UPDI_gc,	/* System Configuration 0 - CRC & UPDI programming pin */
	.SYSCFG1 = SUT_8MS_gc,  /* System Configuration 1 - 8ms wake up */
	.APPEND = 0x00,  /* Application Code Section End */
	.BOOTEND = 0x00,  /* Boot Section End */
};


/*****************************************************************************/
/*                          Global Variables                                 */
/*****************************************************************************/
volatile uint8_t TimerTickFlag;					// flag generated by periodic interrupt
uint8_t OneShot1Counter = 0;
uint8_t OneShot2Counter = 0;
uint8_t OneShot1State = 0;
uint8_t OneShot2State = 0;
uint8_t IncomingBuzz = 0;
uint8_t IncomingBuzzPrevious = 0;
uint8_t IncomingBuzzPreviousPrevious = 0;

uint8_t T20HzCounter = 0;						// used in the ISR


/*****************************************************************************/
int main(void)
{
	InitializeHardware();
	
    while (1)	// loop forever
    {
		if (TimerTickFlag == TRUE)
		{
			// Enable High-voltage controls:
			// Inputs: PushToRing (PB1) and 20Hz_clk (PB4)
			// Outputs: EnHVpositive (PB2) and EnHVnegative (PB3)
			if ((PORTB.IN & PIN1_bm) && (PORTB.IN & PIN4_bm))			// PushToRing true and 20Hz_clk is high
			{
				PORTB.OUTSET = PIN2_bm | PIN3_bm;	// RingGen goes positive
			}
			else if ((PORTB.IN & PIN1_bm) && ((~PORTB.IN) & PIN4_bm))	// PushToRing true and 20Hz_clk is low
			{
				PORTB.OUTCLR = PIN2_bm | PIN3_bm;	// RingGen goes negative
			}
			else																	// PushToRing false
			{
				PORTB.OUTCLR = PIN2_bm;				// HV+ set low (RingGen floating)
				PORTB.OUTSET = PIN3_bm;				// HV- set high (RingGen floating)
			}

			// One-shot routines:
			// Inputs: IncomingBuzz (PC3) and BuzzClk (PA5)
			// Outputs: OneShot25 (PA3) and Buzzer_Amp_Enable (PC1)
			// One-Shot 1 is set for 25 ms
			// One-Shot 2 is set for 150 ms
			if (PORTC.IN & PIN3_bm)			// IncomingBuzz pin
			{
				IncomingBuzz = TRUE;
			}
			else
			{
				IncomingBuzz = FALSE;
			}
			
			
			// One-shot 1 routine: (25 ms)
			if (IncomingBuzz && IncomingBuzzPrevious && (~IncomingBuzzPreviousPrevious))		// rising edge (debounced)
			{
				OneShot1Counter = 2;				// Timer Tick is 8.33 ms, one-shot set for 25 ms, hence counter = (25ms/8.33ms) - 1 = 2
				OneShot1State = TRUE;
				PORTA.OUTSET = PIN3_bm;
			}
			else
			{
				if (OneShot1Counter != 0) OneShot1Counter--;
			}
			
			if (OneShot1Counter == 0)
			{
				OneShot1State = FALSE;
				PORTA.OUTCLR = PIN3_bm;
			}
			
			// One-shot 2 routine (150 ms, re-triggerable):
			if (IncomingBuzz && IncomingBuzzPrevious)				// rising edge (debounced)
			{
				OneShot2Counter = 18;				// Timer Tick is 8.33 ms, one-shot set for 150 ms, hence counter = 150ms/8.33mm = 18
			}
			if (OneShot2Counter != 0)
			{
				OneShot2Counter--;
				OneShot2State = TRUE;
				PORTC.OUTSET = PIN1_bm;
			}
			else
			{
				OneShot2State = FALSE;
				PORTC.OUTCLR = PIN1_bm;
			}
			
			
			// End of loop cleanup code:
			TimerTickFlag = FALSE;									// done with the loop
			IncomingBuzzPrevious = IncomingBuzz;					// used for de-bounced rising edge detector
			IncomingBuzzPreviousPrevious = IncomingBuzzPrevious;	// used for de-bounced rising edge detector
		}
    } // end while(forever)
} // end main()

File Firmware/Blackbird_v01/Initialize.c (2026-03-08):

/*
 * Initialize.c
 *
 * Created: 29-Sep-2025
 * Updated: 10-Oct-2025
 * Author: Steve Reames
 * Released ...
 */ 

#include "Blackbird.h"

/*****************************************************************************/
/*                         Initialize Hardware                               */
/*****************************************************************************/
// The chapter references in these comments are from the Atmel ATtiny406 (tinyAVR 0-series) Datasheet.
// The fuse bits will select the 16/20 MHz clock at power-up. That will be changed
//   later in this code.
// This code assumes a 32 KHz clock.
void InitializeHardware(void)
{
	// *** Interrupts configuration - Chapter 13 ***
	// The Timer Tick will be the highest priority interrupt (Level 1).
	//   All other interrupts will be Level 0, but also a round-robin schedule.
	// Set the Round-robin Scheduling Enable bit:
	CPUINT.CTRLA |= CPUINT_LVL0RR_bm;
	// Set the level 1 interrupt vector:
	CPUINT.LVL1VEC = TCA0_CMP0_vect_num;				//The Timer/Counter creates the Timer Tick
	
	
	// *** I/O Ports Configuration - Chapter 16 ***
	// Port Control
	// PINOUT (ATtiny406, SOIC-20 package)
	// * pin 16 = PA0, UDPI programming pin
	// * pin 17 = PA1, LUT0-IN1 (input)
	// * pin 18 = PA2, LUT0-IN2 (input)
	// * pin 19 = PA3, OneShot25 (output)
	// * pin 2 = PA4, LUT0-OUT (output)
	// * pin 3 = PA5, TCB0, Buzz_clk (output)
	// * pin 4 = PA6, <unused>
	// * pin 5 = PA7, 20Hz_clk (output)

	// Output pins:
	PORTA.DIRSET = PIN3_bm | PIN4_bm | PIN5_bm | PIN7_bm;						// set PA3, PA4, PA5 and PA7 to output
	
	//PORTA.PIN0CTRL = 0;											// UPDI programming pin (in/out)
	//PORTA.PIN1CTRL = 0;
	//PORTA.PIN2CTRL = 0;
	//PORTA.PIN3CTRL = 0;											// output
	//PORTA.PIN4CTRL = 0;											// output
	//PORTA.PIN5CTRL = 0;											// output
	PORTA.PIN6CTRL = PORT_PULLUPEN_bm | PORT_ISC_INPUT_DISABLE_gc;	// pullup (unused)
	//PORTA.PIN7CTRL = 0;											// output
	
	
	// * pin 11 = PB0, TCA0, WO0, 20Hz_clk (output)
	// * pin 10 = PB1, PushToRing (input)
	// * pin 9 = PB2, EnHVpositive (output)
	// * pin 8 = PB3, EnHVnegative (output)
	// * pin 7 = PB4, 20Hz_clk_input (input)
	// * pin 6 = PB5, CLKOUT (output)
	
	// Output pins:
	PORTB.DIRSET = PIN5_bm | PIN3_bm | PIN2_bm | PIN0_bm;	// set PB5, PB3, PB2, PB0 to output
	
	//PORTB.PIN0CTRL = 0;
	//PORTB.PIN1CTRL = 0;
	//PORTB.PIN2CTRL = 0;
	//PORTB.PIN3CTRL = 0;
	//PORTB.PIN4CTRL = 0;
	//PORTB.PIN5CTRL = 0;


	// * pin 12 = PC0, BuzzClkIn (input)
	// * pin 13 = PC1, EnBuzzerAmp (output)
	// * pin 14 = PC2, (unused)
	// * pin 15 = PC3, IncomingBuzz (input)
	
	// Output pins:
	PORTC.DIRSET = PIN1_bm;											// set PC1 to output
	
	//PORTC.PIN0CTRL = 0;
	//PORTC.PIN1CTRL = 0;
	PORTC.PIN2CTRL = PORT_PULLUPEN_bm | PORT_ISC_INPUT_DISABLE_gc;	// pullup (unused)
	//PORTC.PIN3CTRL = 0;


	// *** Clock Control configuration - Chapter 10 ***	// Clock is set for 32 KHz internal
	ccp_write_io((void *) & (CLKCTRL.MCLKCTRLB), (0x00));				// Set main clock prescale to 1
	ccp_write_io((void *) & (CLKCTRL.OSC32KCTRLA), (0x02));				// Run the 32 KHz all of the time.
	while ((CLKCTRL.MCLKSTATUS & CLKCTRL_OSC32KS_bm) == 0) { ; }		// Wait while the 32 KHz clock stabilizes:
	ccp_write_io((void *) & (CLKCTRL.MCLKCTRLA), (0x81));				// Switch to the internal low-power 32 KHz clock & enable output on pin	
	while ((CLKCTRL.MCLKSTATUS & CLKCTRL_OSC32KS_bm) == 0) { ; }		// Wait while the 32 KHz clock stabilizes:
	ccp_write_io((void *) & (CLKCTRL.OSC20MCTRLA), (0x00));				// Do not run the 16/20 MHz clock
	// Now, the pins have been set and the clock system has been configured.
	//   For peripherals, the clock will be 32KHz divided by 1.
	
	// *** Timer/Counter type A (TCA) configuration - Chapter 20 ***
	// This timer has two main functions. One, to create a 8.33 ms (120 Hz) interrupt that
	//   will becomes the timer tick for all software loops. The ISR will create
	//   the 20 Hz clock based on this timer.
	TCA0.SINGLE.CTRLA = TCA_SINGLE_CLKSEL_DIV1_gc;				// No divider
	TCA0.SINGLE.CTRLB = TCA_SINGLE_CMP0EN_bm					// Compare 0 enable, output pin enabled
						| TCA_SINGLE_WGMODE_SINGLESLOPE_gc;		// Single Slope PWM mode
	TCA0.SINGLE.PER = 272;										// TOP value, freq of PWM = 32768/(N+1) where N is TCA0.SINGLE.PER (8.33 ms)
	TCA0.SINGLE.CNT = 0x0000;									// clear the counter
	TCA0.SINGLE.CMP0 = 136;										// set output pin at 50% duty cycle
	TCA0.SINGLE.INTCTRL = TCA_SINGLE_CMP0EN_bm;					// enable interrupts
	TCA0.SINGLE.CTRLA |= TCA_SINGLE_ENABLE_bm;					// Enable the peripheral

	// *** Timer/Counter type B (TCB) configuration - Chapter 21 ***
	// Create PWM signals to control the frequency of the Buzz Clock.
	TCB0.CTRLA = TCB_CLKSEL_CLKDIV1_gc;							// Divide clock by 1 (no divider)
	TCB0.CTRLB = TCB_CCMPEN_bm									// Enable compare and output pin
				| TCB_CNTMODE_PWM8_gc;							// 8-bit PWM mode
	TCB0.CCMPL = 18;											// TOP value, 8-bit value, the period of the waveform
	TCB0.CCMPH = 6;												// COMPARE value, 8-bit value, controls the duty cycle, set output pin at about 1/3 of the period for high harmonic content
	TCB0.CNT = 0;												// Counter should be initialized to BOTTOM value
	TCB0.CTRLA |= TCB_ENABLE_bm;								// Enable the peripheral


	// *** Custom Configurable Logic - Chapter 27 ***
	// We are implementing a 2-input AND gate.
	CCL.LUT0CTRLB = CCL_INSEL0_MASK_gc | CCL_INSEL1_IO_gc;		// IN0 is masked, IN1 is I/O pin
	CCL.LUT0CTRLC = CCL_INSEL2_IO_gc;							// IN2 is I/O pin
	
	CCL.TRUTH0 = 0x40;											// Truth table for AND gate
	
	CCL.LUT0CTRLA = CCL_OUTEN_bm;								// Enable output pin for LUT0-OUT
	
	CCL.LUT0CTRLA |= CCL_ENABLE_bm;								// Enable LUT0
	CCL.CTRLA = CCL_ENABLE_bm;									// Enable the CCL module

	// *** Port Multiplexer configuration - Chapter 15 ***
	// Only used when the output pin for a module is connected to the
	//   default port. For this case no alternate pinout is used.
	

	// *** Sleep Controller configuration - Chapter 11 ***
	// Sleep mode is not used.

	sei();					// enable all interrupts

}

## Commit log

2026-04-24 beta version
    [AudioRinger.kicad_sch, Blackbird_v04.kicad_pcb, Blackbird_v04.kicad_sch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]
2026-04-24 Blackbird version beta
    [NCC_Blackbird_PoC_BOM_verB_013.xlsx]
2026-06-06 Update BOM and iBOM
    Minor changes to component package sizes and values.
    [NCC_Blackbird_PoC_BOM_verB_013.xlsx]
